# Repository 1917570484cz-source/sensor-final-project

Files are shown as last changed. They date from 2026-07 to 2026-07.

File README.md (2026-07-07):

# sensor-final-project

ESP32-S3 多传感器融合扩展板课程设计项目。项目实现了 MPU6050/MPU6500 兼容 IMU、HMC5883L 磁力计、BMP280/BME280 气压计和 GNSS 模块的数据采集、标定、融合与实验分析。

## 目录说明

```text
sensor-final-project/
├── hardware/                 # 硬件设计文件
│   ├── schematic.pdf          # 原理图 PDF
│   ├── pcb.pdf                # PCB 布局/制板文件说明 PDF
│   ├── gerber/                # Gerber 生产文件
│   └── BOM.csv                # 物料清单
├── firmware/                 # 固件与算法代码
│   ├── drivers/               # 串口记录、离线读取和驱动辅助脚本
│   ├── calibration/           # 加速度计、磁力计、Allan 方差和航向残差标定
│   ├── fusion/                # 互补滤波、Mahony、GNSS/INS、实时姿态显示分析脚本
│   ├── ai_enhance/            # 1D-CNN/卷积去噪与 Kalman 对比
│   └── main.c                 # ESP32-S3 主固件
├── data/                     # 测试数据
│   ├── calibration/           # 标定数据
│   ├── fusion_comparison/     # 融合与算法对比数据
│   └── performance/           # 更新频率、CPU 占用和时间同步数据
├── docs/                     # 文档
│   ├── spec.md                # 系统设计要求
│   ├── test_report.md         # 测试报告
│   ├── final_report.pdf       # 最终课程论文
│   └── final_report.docx      # 可编辑最终课程论文
├── figures/                  # 论文和实验图表
└── README.md                 # 仓库说明
```

## 已完成内容

- 硬件：完成 ESP32-S3 扩展板设计，I2C 总线连接 MPU、HMC5883L 和 BMP280，GNSS 使用 UART 与 PPS 引脚。
- 固件：完成 I2C 扫描、传感器初始化、CSV 串口输出、GPS NMEA 解析、PPS 时间同步记录、BMP/GPS 离线记录。
- 标定：完成加速度计六位置 12 参数标定、磁力计椭球拟合、陀螺仪 Allan 方差分析和温度补偿实验。
- 融合：实现互补滤波和 Mahony 姿态融合，完成实时网页姿态显示。
- AI 增强：完成 IMU 静态数据 1D 卷积去噪，并与传统低通、一阶 Kalman 混合结构进行 SNR 对比。
- 实验：完成标定精度、磁力计 3D 散点、Allan 曲线、BMP 楼梯高度、GNSS NMEA 解析、GNSS/INS 松耦合静态分析和更新频率测试。

## 构建与运行

固件基于 ESP-IDF，目标芯片为 ESP32-S3。

```powershell
cd firmware
idf.py set-target esp32s3
idf.py -p COM7 flash monitor
```

Python 分析脚本位于 `firmware/calibration`、`firmware/fusion`、`firmware/ai_enhance` 和 `firmware/drivers`。原始实验 CSV 位于 `data/`。

## 说明

本仓库是课程提交用整理版。原始 ESP-IDF 工程采用单文件主固件 `main.c`，传感器驱动、标定参数、融合算法和日志命令均集中在该文件中；离线标定和可视化脚本按老师要求拆分到对应目录。

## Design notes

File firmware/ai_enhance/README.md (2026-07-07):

# ai_enhance

本目录包含 AI 增强传感器算法：

- `ai_imu_denoise.py`：基于 1D 卷积的 IMU 静态噪声抑制，并对比传统低通和 1D 卷积 + 一阶 Kalman 混合结构。

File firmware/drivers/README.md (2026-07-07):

# drivers

ESP32-S3 固件主驱动集中在 `../main.c` 中，包括：

- I2C 初始化与扫描
- MPU6050/MPU6500 兼容 IMU 读取
- HMC5883L 磁力计读取
- BMP280/BME280 气压计补偿读取
- GNSS UART/NMEA 接收
- PPS GPIO 中断时间同步

本目录存放 PC 端串口记录和离线读取辅助脚本。

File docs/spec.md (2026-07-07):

# 二、系统设计要求

## 1. 硬件设计要求（ESP32 扩展板）

### 1.1 基础规格

- 尺寸限制：≤70mm×50mm（适配嘉立创打样尺寸，标准 2 层板）
- 供电：通过 ESP32 开发板 5V/3.3V 供电，无需外部电源
- 接口：
  - 全部采用 2.54mm 排针，与 ESP32 开发板引脚一一对应
  - I²C 总线共享（SCL/SDA），所有传感器挂同一 I²C 总线
  - GPS 接口：4-pin 2.54mm 排针（VCC/GND/TX/RX），外接 NEO-6M，用杜邦线连
  - LED 指示：至少 1 个电源指示 LED，绿色，串 1kΩ 电阻
- 布局建议：
  - MPU6050 放板中央，减少边缘应力，距板边 ≥ 5mm
  - HMC5883L 远离 ESP32，避免 ESP32 芯片 / WiFi 天线的磁干扰
  - 远离发热元件，避免温度影响气压读数
  - GPS 排针在板边缘，方便连线朝外
  - I²C 上拉电阻一组就够（多个会并联降阻），4.7kΩ × 2（SCL/SDA 各一个）

### 1.2 必修传感器电路

#### MPU6050 六轴 IMU

- 通信接口：SPI（优先）或 I2C
- 必须包含 0.1μF 去耦电容、电源滤波电路
- 预留中断引脚，用于数据就绪触发

#### HMC5883L 三轴磁力计

- 通信接口：I2C
- 必须包含去耦电容和上拉电阻
- 布局远离电源、电机等强干扰源

### 1.3 选修传感器电路（鼓励至少选 1 种）

- MS5611 或 BMP280 气压计：SPI 接口，高精度气压高度测量
- Ublox M6N GPS 模块：UART 接口，预留天线接口
- 电源管理：可选 3.3V LDO，为传感器提供干净电源

### 1.4 信号完整性要求（对应第六讲内容）

- 所有传感器电源引脚必须就近放置 0.1μF 陶瓷去耦电容
- 模拟信号走线尽量短，避免与数字信号走线交叉
- 完整的地平面设计，分割数字地和模拟地
- 预留测试点，方便调试和信号测量

## 2. 算法设计要求

### 2.1 基础算法（所有组必须完成）

#### 传感器标定算法

- 加速度计六位置标定（12 参数模型），零偏 50mg → 2mg（25×）
- 磁力计椭球拟合标定（硬铁 / 软铁补偿），航向 ±15° → ±2°（7×）
- 陀螺仪零偏校准与 Allan 方差分析，零偏漂移降 10×

#### 传统姿态融合算法（至少实现 2 种）

- 互补滤波
- Mahony 滤波
- Madgwick 滤波
- 扩展卡尔曼滤波（EKF）

#### 性能对比分析

- 对比不同算法的姿态精度、计算复杂度、CPU 占用率
- 量化每种算法带来的精度提升幅度

#### 数据可视化（必做）

| 内容 | 工具 / 方式 | 要求 |
| --- | --- | --- |
| 标定前后精度对比表 | Python matplotlib | 误差降低倍数 |
| Allan 方差曲线 | Python allantools | ARW/BI 标注 |
| 磁力计 3D 散点（校准前后） | Python mplot3d | 椭球 → 球 |
| 实时姿态显示 | 串口 + Python / Web | 倾斜板子看角度变化 |
| GPS 轨迹叠加 | Python folium | 户外测试轨迹 |

### 2.2 进阶算法（80 分以上必须完成）

#### 误差状态卡尔曼滤波（ESKF）

- 基于李群李代数 SO(3) 的姿态表示
- 实现 IMU 预积分与误差状态更新
- 目标姿态精度：≤±0.2°（静态）

#### AI 增强传感器算法（至少实现 1 种）

- 1D-CNN IMU 噪声去除：对比传统低通滤波的 SNR 提升 dB 数
- 一阶卡尔曼滤波与 1D-CNN 的混合去噪架构
- 目标：纯惯导漂移从 10m/min 降低至 ≤3m/min

### 2.3 挑战算法（90 分以上可选）

- 多速率传感器融合：GPS 1Hz + IMU 200Hz 异步状态更新
- LSTM GPS 失锁预测：当 GPS 信号丢失时，用 LSTM 预测轨迹
- TLIO/DeepVIO 核心模块复现：基于深度学习的紧耦合惯导里程计
- 多传感器时间同步：实现 IMU、磁力计、GPS 的微秒级时间对齐

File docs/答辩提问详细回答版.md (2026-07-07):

# 答辩提问详细回答版

这个文档是给不熟悉传感器和融合算法的人准备的详细版。答辩时不需要逐字全背，但要理解每题的核心逻辑。每题都分成：

- 老师到底在问什么
- 基础原理怎么理解
- 结合本项目应该怎么说
- 可以直接背的回答
- 可能追问怎么接

特别注意：本项目有些内容只做了原理分析或离线验证，没有完整做成最终主结果。遇到这些问题时，不要硬说“我已经完整实现”，要先说明项目边界，再回答原理。

---

# 第一类：传感器物理与误差本质

## Q1. 六位置标定得到 12 个参数，它们对应 MPU6050 的哪些物理误差？

### 1. 老师到底在问什么

老师不是只想听你说“我用了最小二乘”。他想确认你知道标定出来的数字到底修正了什么物理问题。

你加速度计的标定模型可以写成：

```text
a_cal = A_inv · (a_raw - c)
```

含义是：

```text
校正后的加速度 = 3×3 修正矩阵 × (原始加速度 - 零偏)
```

其中：

- `a_raw`：MPU6050 原始读数。
- `c`：3×1 零偏向量。
- `A_inv`：3×3 误差修正矩阵。
- `a_cal`：校正后的加速度。

所以 12 个参数就是：

```text
3 个零偏参数 + 9 个矩阵参数 = 12 个参数
```

### 2. c 向量对应什么误差

`c` 是：

```text
c = [cx, cy, cz]^T
```

它对应三轴零偏误差。

比如板子水平静止时，理论上应该是：

```text
ax = 0
ay = 0
az = 1g
```

但实际可能读到：

```text
ax = 0.02g
ay = -0.01g
az = 1.05g
```

其中 `ax`、`ay` 明明应该接近 0，却读出非零值，这就是零偏。`az` 理论上应该接近 1g，却多出一部分，也包含零偏和比例误差。

所以第一步 `(a_raw - c)` 就是先把固定偏移减掉。

### 3. A_inv 矩阵对应什么误差

`A_inv` 是一个 3×3 矩阵：

```text
A_inv =
[ a11  a12  a13
  a21  a22  a23
  a31  a32  a33 ]
```

它主要修正三类误差。

第一类是比例因子误差，也叫灵敏度误差。

比如 X 轴真实受到 1g 加速度，理想输出应该是：

```text
ax = 1.000g
```

但实际可能输出：

```text
ax = 0.980g
```

或者：

```text
ax = 1.030g
```

说明 X 轴这把“尺子”不准。`A_inv` 的对角线元素主要修正三轴比例误差：

```text
a11 修正 X 轴比例
a22 修正 Y 轴比例
a33 修正 Z 轴比例
```

第二类是轴间耦合误差。

理想情况下，X 轴只测 X 方向，Y 轴只测 Y 方向，Z 轴只测 Z 方向。但实际传感器三轴不可能完全独立。

比如真实加速度只有 X 方向：

```text
真实加速度 = [1g, 0, 0]
```

理想读数应该是：

```text
输出 = [1g, 0, 0]
```

但实际可能是：

```text
输出 = [1g, 0.03g, -0.02g]
```

这说明 X 方向的加速度串到了 Y/Z 轴上。`A_inv` 的非对角线元素就是用来修正这种耦合：

```text
a12, a13, a21, a23, a31, a32
```

第三类是安装角误差和三轴不正交误差。

即使 MPU 芯片本身正常，它焊在 PCB 上也可能有非常小的倾斜。比如你以为板子的 X 方向就是传感器 X 方向，但芯片实际歪了 1°。这样真实 X 方向的加速度会投影到 Y/Z 轴，表现出来也像轴间耦合。这部分同样由 `A_inv` 的非对角线修正。

### 4. 如果只有零偏误差，A_inv 应该长什么样

要分两种情况说，最完整。

第一种：只有零偏，比例因子和三轴方向都完全理想。

这时只需要减掉 `c`，不需要矩阵修正，所以：

```text
A_inv =
[1  0  0
 0  1  0
 0  0  1]
```

也就是单位矩阵。

第二种：有零偏，也有各轴比例误差，但没有轴间耦合。

这时 `A_inv` 应该是对角矩阵：

```text
A_inv =
[kx  0   0
 0   ky  0
 0   0   kz]
```

其中 `kx`、`ky`、`kz` 分别修正 X/Y/Z 三轴的灵敏度。非对角线为 0，表示 X 不影响 Y/Z，Y 不影响 X/Z，Z 不影响 X/Y。

### 5. 结合本项目怎么说

本项目中，六位置 12 参数标定后：

- 平均误差从约 `20.068 mg` 降到 `1.798 mg`。
- 最大误差从约 `55.789 mg` 降到 `2.120 mg`。

这说明零偏、比例误差和安装耦合误差都被明显补偿了。

### 6. 可直接背的回答

> 我的加速度计标定模型是 `a_cal = A_inv · (a_raw - c)`。其中 `c` 是 3×1 零偏向量，表示 X、Y、Z 三轴的固定偏移。`A_inv` 是 3×3 修正矩阵，对角线元素主要修正三轴灵敏度或比例因子误差，非对角线元素主要修正轴间耦合、三轴不正交以及传感器安装角误差。如果只有零偏且比例完全理想，`A_inv` 应该接近单位矩阵；如果还有比例误差但没有轴间耦合，`A_inv` 应该退化为对角矩阵，对角元素是各轴灵敏度修正系数，非对角线接近 0。

### 7. 可能追问

如果老师问“为什么叫 A_inv？”：

> 可以把原始传感器看成真实加速度先经过一个误差矩阵 A 扭曲后输出。标定的目的就是求它的逆，把扭曲后的数据拉回真实坐标系，所以代码中叫 `A_inv`。

如果老师问“c 和 A_inv 谁先作用？”：

> 先减零偏 `c`，再乘 `A_inv`。因为零偏是固定偏移，先去掉固定偏移，再修正比例和轴间耦合。

---

## Q2. Allan 方差曲线短时间 -1/2、中段最低点、长时间 +1/2 分别代表什么？

### 1. 老师到底在问什么

老师想知道你是否理解 Allan 方差不是普通曲线，而是用来分析 IMU 噪声来源的工具。

Allan 方差横轴通常是平均时间 `τ`，纵轴是 Allan deviation。它回答的问题是：

> 如果我把陀螺仪数据按不同时间窗口平均，噪声会怎么变化？

不同斜率对应不同噪声源。

### 2. 短时间段斜率 -1/2 是什么

短时间段通常由白噪声主导。对白噪声来说，平均时间越长，随机噪声越容易被平均掉，所以 Allan deviation 会下降。

在双对数图上，白噪声对应斜率约为：

```text
-1/2
```

对陀螺仪来说，这段常用来估计角随机游走 ARW，即 Angular Random Walk。

通俗理解：

> 短时间里，陀螺仪输出主要是在真实值附近随机抖动，这种抖动可以通过平均减小。

### 3. 中段最低点是什么

曲线下降到某个位置后会出现最低点或平台，这附近表示平均到这个时间尺度时噪声最小。

这一段通常和零偏不稳定性 BI，也就是 Bias Instability 有关。

通俗理解：

> 平均时间太短，白噪声还没平均干净；平均时间太长，零偏慢漂移又开始显现。中间最低点就是两类误差折中后最稳定的位置。

### 4. 长时间段斜率 +1/2 是什么

长时间段如果曲线上升，常表示零偏随机游走、温漂、慢变化环境等低频漂移开始主导。

在双对数图上，如果斜率约为：

```text
+1/2
```

通常可理解为 rate random walk 或 bias random walk 类型的慢漂移。

通俗理解：

> 时间越长，陀螺仪零点不是固定的，而是慢慢飘走，所以平均反而不能继续降低误差。

### 5. 和 Kalman 滤波 Q、R 的关系

Kalman 滤波里：

- `R` 表示观测噪声，也就是传感器测量本身有多吵。
- `Q` 表示过程噪声，也就是系统状态预测有多不可靠。

对应关系可以这样理解：

短时间白噪声/角随机游走：

- 反映陀螺仪测量噪声。
- 可以用于设置陀螺仪测量噪声或姿态更新里的噪声项。
- 更接近 `R` 或角速度测量噪声。

长期零偏漂移：

- 反映陀螺仪 bias 会随时间变化。
- 如果滤波器把陀螺零偏作为状态估计，那么 bias 的随机游走噪声应该放进 `Q`。

### 6. 结合本项目怎么说

本项目完成了约 300 s 静态陀螺仪数据采集和 Allan 方差曲线绘制。它主要用于分析噪声特性和辅助滤波器参数选择。

注意不要说“已经严格证明零偏漂移降低 10×”，因为这个需要补偿前后长期对比数据，而当前主要是 Allan 噪声分析。

### 7. 可直接背的回答

> Allan 方差短时间段斜率约 -1/2，说明白噪声主导，对陀螺仪来说对应角随机游走 ARW；中间最低点表示在这个平均时间尺度下零偏最稳定，和 bias instability 有关；长时间段如果斜率变成 +1/2，说明零偏随机游走或慢漂移开始主导。和 Kalman 滤波对应时，短时间白噪声更多用于设置陀螺测量噪声，也就是 R 或角速度噪声；长期零偏漂移则对应状态模型里 bias 的过程噪声，应该进入 Q 矩阵。

### 8. 可能追问

如果老师问“为什么不是平均越久越准？”：

> 因为平均只能降低白噪声，但不能消除零偏慢漂移。时间太长后，零偏本身会变，平均反而把漂移包含进去，所以 Allan 曲线会重新上升。

---

## Q3. HMC5883L 分辨率是 5 mGauss，为什么校准后磁场模长 std 仍然远大于它？

### 1. 老师到底在问什么

老师想看你是否能区分：

- 数据手册里的分辨率
- 实际系统中的精度
- 实验环境带来的干扰

很多人会误以为传感器分辨率就是最终精度，这是错误的。

### 2. 单位先换算

HMC5883L 分辨率是 5 mGauss。

换算关系：

```text
1 Gauss = 100 uT
1 mGauss = 0.1 uT
5 mGauss = 0.5 uT
```

所以数据手册分辨率约为：

```text
0.5 uT
```

### 3. 本项目实测数据

本项目磁力计模长结果：

- 标定前模长标准差：`3.303 uT`
- 标定后模长标准差：`1.892 uT`

校准后 `1.892 uT` 仍然大于数据手册分辨率 `0.5 uT`。

### 4. 为什么会这样

原因是 datasheet 分辨率只说明传感器输出能分辨的最小变化，不等于最终整机精度。

实际系统中还有很多误差：

1. 周围磁环境干扰
   - 桌面、螺丝、手机、电源线、电脑、USB 线都可能影响磁场。

2. PCB 布局和电源噪声
   - 磁力计附近如果有高频数字信号、大电流走线或去耦不好，会增加噪声。

3. 硬铁和软铁残差
   - 椭球拟合能补偿一部分，但如果采集数据覆盖不均匀，补偿不可能完全理想。

4. 采集动作不均匀
   - 如果没有完整覆盖整个球面，某些方向的数据不足，拟合结果会偏。

5. 传感器本身老旧或模块差异
   - HMC5883L 属于较老的磁力计，实际模块质量差异较大。

### 5. 算法不对还是硬件原因

不能简单说算法不对。

如果标定后标准差从 `3.303 uT` 降到 `1.892 uT`，说明算法确实有效。但是剩余误差大于 datasheet 分辨率，主要说明系统级环境和硬件因素仍然存在。

### 6. 可直接背的回答

> HMC5883L 的 5 mGauss 约等于 0.5 uT。我的磁力计标定前模长标准差是 3.303 uT，标定后是 1.892 uT，虽然明显下降，但仍然大于 0.5 uT。这不一定说明算法错误，因为 datasheet 分辨率不等于整机精度。剩余误差主要来自磁环境干扰、PCB 电源和走线影响、采集球面覆盖不均匀，以及硬铁软铁补偿残差。

### 7. 可能追问

如果老师问“怎么进一步降低？”：

> 我会让磁力计远离 ESP32 天线、USB 和电源走线，增加去耦，采集时远离手机和铁磁物体，并用更均匀的全空间旋转数据进行鲁棒椭球拟合。

---

## Q4. 气压计测高精度是多少？误差预算怎么分解？

### 1. 老师到底在问什么

老师想知道你是否明白：BMP280 测高度不是直接测“高度”，而是先测气压，再用气压换算高度。

所以误差不仅来自 BMP280 本身，还来自参考气压、温度、天气变化和真实高度参考。

### 2. 本项目结果

楼梯实验数据：

- 人工测量楼层高度：`3.950 m`
- BMP280 测量相对高度：`3.980 m`
- 绝对误差：`0.030 m`
- 相对误差：`0.76%`

也就是说，在这次短时间楼梯相对高度实验中，误差约为 3 cm。

### 3. 气压高度为什么依赖 P0

气压高度不是直接测出来的，而是由气压公式换算：

```text
h = f(P / P0)
```

其中：

- `P` 是当前气压。
- `P0` 是参考气压。

如果 `P0` 不准，即使 BMP280 当前压力测得很准，高度也会整体偏。

### 4. 误差预算怎么拆

可以拆成以下几项：

1. 传感器压力噪声
   - BMP280 自身压力读数会有噪声。
   - 短时间平均可以降低这部分噪声。

2. P0 参考气压误差
   - 高度换算对 P0 很敏感。
   - P0 不准会造成整体高度偏移。
   - 在绝对高度测量中，这通常是主导误差。

3. 温度补偿误差
   - BMP280 压力补偿依赖温度。
   - 温度变化或温度读取滞后会影响压力换算。

4. 天气漂移
   - 气压会随天气变化。
   - 长时间测试时，天气变化可能造成几十米级高度漂移。
   - 但本项目楼梯实验时间短，所以影响较小。

5. 人工真值误差
   - 楼层高度 3.95 m 是人工测量值，也有测量误差。

6. 气流和动态扰动
   - 上下楼、开门、风流会改变局部气压。

### 5. 哪一项是主导误差

在本项目的短时间楼梯相对高度实验中：

- 主要瓶颈不是 BMP280 分辨率。
- 更主要的是 `P0` 参考、环境气压稳定性、人工测量真值和窗口平均方法。

在长时间绝对高度实验中：

- `P0` 和天气漂移通常是主导误差。

### 6. 可直接背的回答

> 我这次 BMP280 楼梯实验中，人工测量高度是 3.950 m，BMP280 测得 3.980 m，绝对误差 0.030 m，相对误差 0.76%。误差预算可以分为传感器压力噪声、P0 参考气压误差、温度交叉敏感、天气气压漂移、人工高度真值误差和气流扰动。短时间相对高度实验中，BMP280 分辨率不是主要瓶颈，主要瓶颈是 P0 和环境条件；长时间绝对高度中，天气漂移和 P0 会成为主导误差。

---

## Q5. HMC5883L 离 ESP32 WiFi 天线距离变化会怎样影响航向？

### 1. 老师到底在问什么

老师想看你是否从系统电磁兼容角度理解磁力计，而不是只看算法。

磁力计测的是微弱地磁场，地磁场量级大约几十 uT。任何附近电流、天线、高频数字信号、铁磁材料都可能改变磁场读数。

### 2. 距离从 15 mm 变 5 mm 会怎样

如果磁力计离 ESP32 WiFi 天线或电源路径更近，可能会出现：

- 磁场三轴均值偏移。
- 磁场模长标准差变大。
- 航向 yaw 出现固定偏差。
- WiFi 发射时 yaw 抖动增加。

距离变近通常会让干扰增强。具体增强多少取决于天线、电流路径、地平面和磁力计方向。

### 3. 怎么实验验证

可以设计一个很简单的对比实验：

1. 固定板子，不让它动。
2. 记录 WiFi 关闭时的磁场三轴和 yaw。
3. 打开 WiFi 但不传输数据，再记录。
4. WiFi 高负载发包，再记录。
5. 比较三种情况下：
   - `mag_x/y/z` 均值变化。
   - 磁场模长标准差。
   - yaw 平均值偏移。
   - yaw 标准差。

如果 WiFi 影响明显，高负载发包时 yaw 标准差和模长标准差会变大。

### 4. 本项目怎么说

你没有精确测 HMC5883L 到 WiFi 天线距离，也没有做开关 WiFi 对比实验，所以不要乱报具体数值。

可以回答：

> 这一项我没有单独量化，但从 EMC 角度，下一版 PCB 会让磁力计远离 ESP32 天线、电源和 USB 区域。

### 5. 可直接背的回答

> 磁力计测的是几十 uT 量级的地磁场，离 ESP32 WiFi 天线或大电流路径太近，会引入电磁干扰和局部磁场扰动。距离从 15 mm 减到 5 mm，我预期磁场模长波动和 yaw 标准差都会增大。验证方法是固定板子，分别在 WiFi 关闭、开启、持续发包三种情况下采集磁场和 yaw，比较均值偏移和标准差变化。

---

# 第二类：标定算法的数学深度

## Q6. 椭球拟合 SVD 为什么取最小奇异值对应的右奇异向量？

### 1. 老师到底在问什么

老师想确认你知道 SVD 在这里不是“固定套路”，而是在求一个最小残差解。

椭球拟合可以写成齐次方程：

```text
Phi · q = 0
```

其中：

- `Phi` 是由磁力计采样点构成的矩阵。
- `q` 是椭球方程参数。

### 2. 为什么不能直接解

因为这是齐次方程，`q = 0` 永远满足：

```text
Phi · 0 = 0
```

但 `q=0` 没有任何物理意义。所以要加一个约束：

```text
||q|| = 1
```

也就是在单位长度的所有 `q` 里面，找一个让残差最小的方向。

目标变成：

```text
min ||Phi · q||
subject to ||q|| = 1
```

### 3. SVD 为什么取最小奇异值

SVD 分解：

```text
Phi = U · S · V^T
```

奇异值表示矩阵在不同方向上的放大能力。

最小奇异值对应的右奇异向量，就是被 `Phi` 放大最小的方向。也就是说，在单位长度条件下，它让：

```text
||Phi · q||
```

最小。

所以取最小奇异值对应的右奇异向量，而不是最大奇异值。最大奇异值方向是残差最大的方向，正好相反。

### 4. 如果数据只覆盖半个球面会怎样

椭球拟合要求数据尽量覆盖完整三维空间。如果只转了半个球面，会出现：

- 某些方向没有约束。
- 奇异值分布退化。
- 最小奇异值对应的方向不稳定。
- 椭球中心和轴长可能严重偏。
- 解可能不唯一。

通俗说：

> 数据没有告诉算法“另一半球面长什么样”，算法只能猜，所以拟合会不可靠。

### 5. 可直接背的回答

> 椭球拟合可以写成齐次方程 `Phi q = 0`。因为零解没有意义，所以加 `||q||=1` 的约束，本质上是在单位长度的 q 中找让 `||Phi q||` 最小的方向。SVD 中最小奇异值对应的右奇异向量正是最小残差方向，所以取它。如果采集数据只覆盖半个球面，某些方向约束不足，奇异值会退化，解会变得不唯一或不稳定，椭球中心和轴长都可能偏。

---

## Q7. 六位置标定时桌面不水平，误差会进入标定结果吗？

### 1. 老师到底在问什么

老师想看你是否理解“六个面的真值”不是天然准确的。你把板子放在桌面上，默认桌面是水平的。但如果桌面倾斜 2°，理论真值就不是完美的 ±X/±Y/±Z。

### 2. 桌面倾斜会造成什么

假设你以为当前是 +Z 朝上，理论加速度应为：

```text
[0, 0, 1g]
```

但桌面倾斜 2° 时，重力会在 X/Y 方向有投影。

小角度下：

```text
sin(2°) ≈ 0.0349
```

也就是会产生约：

```text
0.035g = 35 mg
```

的横向分量。

这已经比 2 mg 目标大很多。

### 3. 误差会不会进入标定结果

会。

如果你仍然把这个位置当作理想 +Z，那么标定算法会认为这个横向分量是传感器误差，并把它吸收到：

- 零偏 `c`
- 非正交矩阵 `A_inv`
- 安装角误差项

里。

这样标定出来的参数会包含桌面倾斜误差。

### 4. 如何消除

方法：

1. 使用水平仪或高精度水平平台。
2. 每个方向多次摆放并取平均。
3. 用夹具保证六个方向正交。
4. 不只用六位置，而是采集更多随机姿态，用重力模长 `|g|=1` 约束做球面标定。
5. 标定时记录平台倾角并修正真值方向。

### 5. 本项目怎么说

你的项目中确实是手动六位置采集，所以可以承认：

> 摆放误差会影响标定结果，因此我通过每个位置采集多样本并筛选稳定数据来降低随机影响，但如果平台系统性倾斜，仍然会进入标定参数。

### 6. 可直接背的回答

> 会进入。因为六位置标定默认六个面的真值是 ±X、±Y、±Z，如果桌面倾斜 2°，重力会产生约 sin2°≈0.035g，也就是 35mg 的横向分量。算法可能把这个误差吸收到非正交矩阵或安装角误差里。消除方法是使用水平平台或夹具，或者采集更多随机姿态，用重力模长约束做自校准。

---

## Q8. 温度补偿二次多项式系数怎么确定？外推到 60°C 会怎样？

### 1. 老师到底在问什么

老师想确认你知道标定模型有适用范围。一个模型在标定温度范围内可能有效，但超出范围就不一定可靠。

### 2. 二次温度补偿模型是什么

陀螺仪零偏会随温度变化，可以建模为：

```text
b(T) = α + βT + γT²
```

其中：

- `b(T)` 是某一温度下的零偏。
- `T` 是温度。
- `α、β、γ` 是拟合系数。

三轴陀螺通常每个轴都要拟合一组三个系数。

### 3. 系数怎么确定

需要在多个温度点下采集静态陀螺数据：

```text
T1 -> b1
T2 -> b2
T3 -> b3
...
```

然后用最小二乘拟合：

```text
b(T) = α + βT + γT²
```

温度点越多、覆盖越均匀，拟合越可靠。

### 4. 20°C 到 50°C 和 60°C 的区别

如果标定数据覆盖 20°C 到 50°C：

- 在 20-50°C 内使用，叫插值。
- 在 60°C 使用，叫外推。

插值相对可靠，因为模型在已知数据范围内。

外推不可靠，因为 60°C 没有数据约束，二次多项式可能偏离真实传感器特性。

### 5. 外推误差属于什么误差

属于模型外推误差，也可以说是模型适用范围外误差。

如果多项式阶数更高，还可能出现 Runge 现象，即在区间外或边缘出现剧烈振荡。

### 6. 项目边界

如果老师问“你的温度补偿”，但你没有完整做温箱实验，不要硬说已经做完。

你可以说：

> 本项目主要完成 Allan 方差和静态噪声分析，温度补偿作为可扩展方法；如果要做，需要按温度点采集零偏并拟合系数。

### 7. 可直接背的回答

> 二次温度补偿系数需要在多个温度点下静态采集陀螺零偏，然后用最小二乘拟合 `b(T)=α+βT+γT²`。20°C 到 50°C 内使用属于插值，60°C 使用属于外推。外推没有实测数据约束，误差可能明显增大，属于模型外推误差；高阶多项式还可能在区间外产生振荡。

---

## Q9. 磁力计椭球拟合中离群点有什么影响？如何减少？

### 1. 老师到底在问什么

老师想看你是否知道普通最小二乘对异常点很敏感。

### 2. 为什么离群点影响大

SVD 椭球拟合本质上是最小二乘思想，最小化所有点的整体残差。

普通最小二乘相当于使用 L2 损失：

```text
loss = residual²
```

残差会被平方，所以一个很大的离群点会被赋予非常大的影响。

比如采集时手机靠近一下，磁力计读数突然跳变，这个点可能把椭球中心和轴长拉偏。

### 3. 离群点会造成什么结果

可能导致：

- 硬铁中心估计错误。
- 软铁矩阵估计错误。
- 校准后球面仍然不圆。
- 航向角出现固定偏差或局部方向误差。

### 4. 如何减少离群点影响

方法：

1. 采集时实时看磁场模长，明显异常就重采。
2. 标定前按模长范围筛选数据。
3. 用 RANSAC：
   - 随机选一部分点拟合。
   - 看有多少点符合模型。
   - 保留内点最多的模型。
4. 用 Huber 损失或 Tukey 损失替代普通 L2。
5. 拟合后根据残差再次剔除异常点并重新拟合。

### 5. 可直接背的回答

> 离群点对普通 SVD 椭球拟合影响很大，因为它本质上接近最小二乘，L2 损失会把大残差平方放大。一个手机靠近造成的异常点可能拉偏椭球中心和轴长。减少影响的方法包括采集前后做模长阈值筛选、用 RANSAC 找内点、用 Huber 等鲁棒损失，或者先拟合再按残差剔除异常点重新拟合。

---

## Q10. BMP280 的 t_fine 是什么？为什么温度补偿结果会用于气压补偿？

### 1. 老师到底在问什么

老师想确认你不是直接复制 Bosch 代码，而是理解温度和压力补偿之间的耦合。

### 2. t_fine 是什么

BMP280 里温度 ADC 不是直接等于真实温度，压力 ADC 也不是直接等于真实压力。

Bosch 补偿算法先根据温度原始值和芯片内部校准参数算出一个中间量：

```text
t_fine
```

它可以理解为高精度内部温度补偿状态。

它不是简单的摄氏温度显示值，而是用于后续补偿计算的内部变量。

### 3. 为什么气压补偿也要用 t_fine

压力传感器对温度敏感。也就是说，同一个真实压力下，如果温度不同，压力 ADC 输出也会变。

所以压力补偿时必须知道当前温度状态。

Bosch 的算法就是：

1. 先用温度原始值计算 `t_fine`。
2. 再用 `t_fine` 修正压力原始值。

这说明温度补偿和压力补偿不是完全独立的。

### 4. 温度和气压读取时间差 100 ms 会怎样

如果温度和气压读取差了 100 ms，在室内慢温变条件下影响可能很小。

但如果环境温度变化很快，比如：

- 手指触摸芯片
- 热风吹过
- 设备从室内到室外
- 电路发热快速变化

那么压力补偿使用的温度就不是压力采样时的真实温度，会引入温度交叉敏感误差。

### 5. 可直接背的回答

> t_fine 是 Bosch 补偿算法中的内部精细温度变量，由温度原始 ADC 和芯片校准参数计算得到。BMP280 的压力输出受温度影响，所以压力补偿必须使用 t_fine。若温度和压力读取相差 100 ms，在温度变化慢的室内影响较小；但在快速温变下，会用不匹配的温度去补偿压力，从而引入温度交叉敏感误差。

---

# 第三类：融合算法的工程理解

## Q11. Madgwick 滤波器 beta 怎么选？快速机动时有什么影响？

### 1. 先说明项目边界

本项目最终展示的是：

- 互补滤波
- Mahony 滤波
- ESKF 静态分析

没有把 Madgwick 滤波作为最终主结果。因此答题时不能硬说“我的 Madgwick 参数是多少”。可以先说明：

> 本项目最终没有把 Madgwick 作为主结果，但从 Madgwick 原理看，beta 的作用是这样的。

### 2. beta 是什么

Madgwick 滤波中，陀螺仪负责预测姿态，加速度计和磁力计负责修正姿态。`beta` 控制修正项强度。

简单理解：

- `beta` 大：更相信加速度计/磁力计修正，收敛快，但动态时容易被干扰。
- `beta` 小：更相信陀螺积分，动态更平滑，但长期漂移更明显。

### 3. 快速急转弯时为什么 beta 要小心

飞机快速急转弯时，加速度计测到的不再只是重力，还包含：

- 离心加速度
- 机动加速度
- 振动

Madgwick 的姿态修正默认加速度计主要测重力方向。如果这个假设不成立，过大的 beta 会把非重力加速度误认为姿态倾斜，从而把姿态拉错。

### 4. 200 deg/s 持续 0.5 秒的影响

角速度 200 deg/s 持续 0.5 s，姿态变化量约：

```text
200 × 0.5 = 100°
```

这是很强的动态机动。此时应降低加速度计修正权重，也就是降低 beta，或者动态调整 beta。

### 5. 可直接背的回答

> 本项目最终展示的是互补滤波和 Mahony 滤波，没有把 Madgwick 作为主结果。如果从 Madgwick 原理看，beta 是梯度下降修正项权重。beta 越大，越相信加速度计和磁力计，收敛快但动态机动时容易被非重力加速度误导；beta 越小，越相信陀螺积分，动态更平滑但长期漂移更大。飞机快速急转时，加速度计测到的不只是重力，所以 beta 应该适当降低或自适应调整。

---

## Q12. Roll/Pitch 和 Yaw 精度是多少？为什么 Yaw 比 Roll/Pitch 差？

### 1. 本项目可报数据

静态姿态实验：

- ESKF roll 标准差：`0.074643°`
- ESKF pitch 标准差：`0.132308°`
- 静态稳定 RMS：`0.151800°`

航向残差补偿：

- 平均绝对误差：`1.907°`
- 最大绝对误差：`6.940°`

### 2. 为什么 Roll/Pitch 比 Yaw 好

静止时，加速度计可以测到重力方向。

重力方向可以约束：

- Roll
- Pitch

因为板子前后倾、左右倾，重力在三轴上的投影会变化。

但是 Yaw 是绕重力轴旋转。比如板子水平放在桌上，原地转一圈，重力方向在传感器坐标里的投影基本不变。

所以：

```text
加速度计无法观测 Yaw
```

Yaw 必须依赖：

- 磁力计
- GPS 航向
- 视觉
- 双天线 GNSS

而磁力计很容易受到磁环境影响，所以 Yaw 通常比 Roll/Pitch 差。

### 3. 如果去掉磁力计，Yaw 10 分钟会漂多少

去掉磁力计后，Yaw 只能靠陀螺积分。

漂移估算公式：

```text
Yaw 漂移 ≈ 陀螺零偏 × 时间
```

10 分钟：

```text
600 s
```

如果陀螺 Z 轴零偏是 `0.05 deg/s`，则：

```text
0.05 × 600 = 30°
```

如果零偏是 `0.01 deg/s`，则：

```text
0.01 × 600 = 6°
```

所以具体漂移要看实测陀螺零偏，但一定会随时间累积。

### 4. 可直接背的回答

> 本项目静态姿态中，Roll 标准差约 0.0746°，Pitch 标准差约 0.1323°，静态稳定 RMS 约 0.1518°。航向补偿后平均绝对误差约 1.907°，最大约 6.940°。Yaw 比 Roll/Pitch 差，是因为加速度计只能观测重力方向，可以约束 Roll 和 Pitch，但绕重力轴旋转的 Yaw 对加速度计不可观，必须依赖磁力计，而磁力计又容易受环境干扰。去掉磁力计后，Yaw 会按陀螺零偏乘时间累积漂移，比如 0.05 deg/s 的零偏 10 分钟会漂约 30°。

---

## Q13. 卡尔曼滤波 Q 矩阵代表什么？Q 过小或过大会怎样？

### 1. 老师到底在问什么

老师想确认你理解 KF 调参，而不是只会调用公式。

Kalman 滤波核心是平衡：

- 模型预测
- 传感器观测

### 2. Q 和 R 的区别

`Q` 是过程噪声协方差。

它表示：

> 我对系统模型预测有多不信任。

`R` 是观测噪声协方差。

它表示：

> 我对传感器测量有多不信任。

### 3. Q 过小会怎样

Q 过小表示滤波器过度相信模型预测。

现象：

- 曲线很平滑。
- 对真实变化反应慢。
- 楼梯高度变化时可能跟不上。
- 严重时滤波器过度自信，真实状态变化后仍不修正，可能发散。

这叫：

- over-confidence
- filter divergence

### 4. Q 过大会怎样

Q 过大表示滤波器认为模型很不可靠，于是更相信观测。

现象：

- 曲线跟着测量抖动。
- 滤波效果变差。
- 近似退化成直接测量或加权平均。

### 5. 项目边界

如果老师问“你的高度 KF”，但本项目最终主要展示 BMP280 相对高度实验，而不是完整 GPS/气压高度 KF，可以说：

> 本项目主要完成 BMP280 相对高度验证，KF 参数属于扩展分析。如果使用高度 KF，Q 应根据真实垂直运动变化和气压高度模型误差来设置。

### 6. 可直接背的回答

> Q 是过程噪声协方差，表示模型预测的不确定性；R 是观测噪声协方差，表示传感器测量的不确定性。Q 设得太小，滤波器过度相信模型，输出很平滑但跟踪真实变化慢，严重时过度自信甚至发散；Q 设得太大，滤波器过度相信观测，输出会抖，滤波效果减弱，接近直接跟随测量。

---

## Q14. GPS/气压互补滤波 alpha=0.98 对应多长时间常数？气压天气漂移怎么办？

### 1. 项目边界

本项目最终没有把 GPS/气压动态互补滤波作为主结果，完成的是：

- BMP280 楼梯相对高度实验。
- GNSS NMEA 解析。
- 静态 GPS 数据分析。

所以如果老师问，可以先说：

> 本项目没有把 GPS/气压动态互补作为最终主结果，但从一阶互补滤波原理看，alpha 可以这样理解。

### 2. alpha 和时间常数关系

一阶滤波中，近似时间常数：

```text
tau = dt / (1 - alpha)
```

如果：

```text
alpha = 0.98
dt = 0.02 s
```

则：

```text
tau = 0.02 / 0.02 = 1 s
```

意思是滤波器大约用 1 秒时间响应变化。

### 3. 台风前气压下降 3 hPa 会造成多大高度误差

近似关系：

```text
1 hPa ≈ 8.4 m
```

所以：

```text
3 hPa ≈ 25.2 m
```

如果不更新 `P0`，气压高度会慢慢漂移约 25 m。

### 4. 怎么补偿

方法：

1. 定期用 GPS 高度或已知高度修正 `P0`。
2. 引入气象站参考气压。
3. 对气压慢漂建模，把 `P0` 作为状态估计。
4. 动态调整 alpha，在长期慢漂时增加 GPS/外部参考权重。

### 5. 可直接背的回答

> 本项目没有把 GPS/气压动态互补作为最终主结果。如果按 alpha=0.98、dt=0.02s 计算，时间常数约为 1s。气压高度对天气很敏感，1hPa 约等于 8.4m 高度变化，所以 1 小时下降 3hPa 会造成约 25m 的高度漂移。解决方法是定期用 GPS 或已知高度重置 P0，或者把 P0 漂移作为状态估计，而不能长期只依赖气压计。

---

## Q15. I2C 总线上三个传感器如何调度？中断竞争怎么处理？

### 1. 老师到底在问什么

老师想看你是否理解嵌入式实时系统中总线共享和中断竞争。

本项目 I2C 总线挂了：

- MPU6050/MPU6500：`0x68`
- HMC5883L：`0x1E`
- BMP280：`0x76`

### 2. I2C 总线基本特点

I2C 是主从总线。

ESP32-S3 是主设备，传感器是从设备。所有读写都由 ESP32-S3 发起。

关键点：

> 同一时刻 I2C 总线上只能有一个事务。

所以不能同时读 MPU、HMC 和 BMP，必须排队。

### 3. 如何调度读取顺序

按传感器更新需求：

- IMU 频率最高，优先读。
- 磁力计频率中等。
- BMP280 气压变化慢，频率可以最低。

可用调度方式：

```text
每个循环读 IMU
每 N 个循环读磁力计
每 M 个循环读 BMP280
```

这样既保证姿态融合实时性，也减少总线占用。

### 4. MPU 中断在 BMP 读取途中触发会怎样

如果 MPU 的 data ready 中断在 BMP280 I2C 读取途中触发：

- 硬件上不会打断当前 I2C 事务。
- 中断只是通知“MPU 数据好了”。
- 正确做法是在中断服务函数里只置标志位。
- 当前 BMP 读完后，主循环或任务再处理 MPU 读取。

### 5. 多任务竞争怎么处理

如果 FreeRTOS 多个任务都可能访问 I2C，需要 mutex：

```text
take mutex
I2C read/write
give mutex
```

否则任务切换可能导致两个任务同时操作 I2C 驱动，造成通信异常。

### 6. 可直接背的回答

> I2C 是主从总线，ESP32-S3 控制所有时序，所以三个传感器不能同时读，必须由主控调度。我会让 IMU 高频读取，磁力计和 BMP280 低频读取。MPU 中断在 BMP280 读取途中触发时，不会打断当前 I2C 事务，中断里只置 data-ready 标志，等当前事务结束后再读 MPU。如果多个 FreeRTOS 任务访问 I2C，则必须用 mutex 保护总线。

---

# 第四类：系统工程与批判性思维

## Q16. MPU6050 安装倾斜能被六位置标定补偿吗？

### 1. 老师到底在问什么

老师想确认你理解“标定参数”和“机械安装状态”绑定。

如果传感器焊死在 PCB 上，安装误差是固定的，可以通过标定补偿。

如果传感器用杜邦线晃来晃去，安装误差每次都变，标定参数就失效。

### 2. 安装倾斜是什么

安装倾斜指的是：

> 传感器芯片坐标系和 PCB 板坐标系不完全重合。

比如板子 X 方向和 MPU 芯片 X 方向差了 1°。

这会导致真实 X 方向加速度投影到 Y/Z 轴，看起来像轴间耦合。

### 3. 六位置标定能不能补偿

能，但有前提：

- 传感器固定在 PCB 上。
- 标定后相对位置不再变化。
- 后续使用时仍保持同一安装状态。

补偿发生在：

```text
a_cal = A_inv · (a_raw - c)
```

其中 `A_inv` 的非对角项吸收安装角误差。

### 4. 什么情况不能补偿

如果传感器不是固定的，比如：

- 杜邦线连接
- 模块悬空
- 每次插拔角度不同

那安装关系会变。一次标定得到的 `A_inv` 只对当时状态有效，换个姿态就不准确。

### 5. 可直接背的回答

> 如果 MPU6050 固定焊接在 PCB 上，安装倾斜是固定误差，可以被六位置 12 参数标定补偿，主要体现在 A_inv 的非对角项里。补偿发生在 `A_inv · (raw-c)` 这一步。但如果传感器用杜邦线连接，每次相对角度都变，那么安装误差不是固定的，之前的标定参数就不能长期有效。

---

## Q17. 无人机电机启动后磁力计跳变，有哪些解决方案？

### 1. 老师到底在问什么

老师想看你能不能从系统工程角度解决磁干扰问题，而不是只说“屏蔽一下”。

电机启动后，磁力计跳变可能来自：

- 电机磁场。
- 电调电流。
- 电源线大电流。
- 机架铁磁材料。
- 高频 EMI。

### 2. 方案一：磁力计远离干扰源

做法：

- 用延伸杆把磁力计远离电机、电调和大电流线。

优点：

- 从源头降低干扰。
- 简单直接。

缺点：

- 结构复杂。
- 线缆变长，可能引入通信和振动问题。

### 3. 方案二：电流补偿

做法：

- 测量电机电流。
- 建立磁干扰和电流之间的模型。
- 飞行中根据电流补偿磁力计。

类似 ArduPilot 的 COMPASS_MOT 思路。

优点：

- 能补偿随油门变化的磁干扰。

缺点：

- 需要电流传感器。
- 需要专门标定。
- 对复杂干扰不一定完全有效。

### 4. 方案三：降低磁力计权重

做法：

- 当检测到磁场模长异常时，降低磁力计在姿态融合里的权重。
- 短时间更多依赖陀螺和其他传感器。

优点：

- 软件实现，不需要改硬件。

缺点：

- 长时间不用磁力计，Yaw 会漂。

### 5. 方案四：双天线 GNSS 测向

做法：

- 用双 GNSS 天线直接测航向。

优点：

- 不受电机磁场影响。
- 大型无人机上更可靠。

缺点：

- 成本高。
- 需要足够天线基线。
- 室内或遮挡环境不好用。

### 6. 我会选什么

优先级：

1. 先做硬件隔离：磁力计远离电机和大电流线。
2. 再做磁异常检测和电流补偿。
3. 如果是大型平台，再考虑双天线 GNSS。

### 7. 可直接背的回答

> 我会先从硬件上把磁力计远离电机、电调和大电流线，这是最直接有效的；其次可以做类似 COMPASS_MOT 的电流补偿，根据电流估计磁干扰；软件上还可以检测磁场模长异常，在异常时降低磁力计权重；如果是大型无人机，可以用双天线 GNSS 测向替代磁罗盘。单纯屏蔽不一定可靠，因为低频磁场很难用普通屏蔽完全消除。

---

## Q18. 如果重新设计 PCB，会改哪些 Layout？

### 1. 老师到底在问什么

老师想看你是否能批判性分析自己的硬件，而不是只说“下次优化布局”。

### 2. 不知道铺铜覆盖率怎么办

如果你没有精确计算背面铺铜覆盖率，不要乱报数字。

可以说：

> 我没有在答辩前精确统计铺铜覆盖率，但从这次调试结果看，下一版我会重点改磁力计位置、电源去耦和 I2C 参考地。

### 3. 改进点一：磁力计远离干扰源

问题：

- HMC5883L 对磁环境很敏感。
- 靠近 ESP32、USB、电源走线或大电流路径会影响 yaw。

改进：

- 把磁力计放到 PCB 边缘。
- 远离天线、电源芯片、USB 口、大电流走线。

收益：

- 降低磁场均值偏移和模长波动。
- 有助于降低航向角误差。

### 4. 改进点二：去耦电容靠近传感器

问题：

- 电源噪声会影响传感器读数。

改进：

- 每个传感器 VCC 附近放 0.1 uF 去耦电容。
- BMP280、HMC5883L、MPU 电源旁边尽量短回路。

收益：

- 降低电源纹波。
- 减少 uT 级磁场波动和 I2C 通信异常概率。

### 5. 改进点三：I2C 走线和参考地

问题：

- I2C 是数字信号，如果走线长、参考地不连续，容易产生毛刺。

改进：

- SDA/SCL 尽量短。
- 走线下方保持连续地平面。
- 上拉电阻靠近总线合适位置。
- 避免穿过电源噪声区域。

收益：

- 提高 400 kHz I2C 稳定性。
- 降低通信错误和边沿串扰。

### 6. 改进点四：地平面连续

问题：

- 地平面被切割会导致回流路径变长，增加 EMI。

改进：

- 保持连续铺地。
- 高速数字区和敏感传感器区合理分区。

收益：

- 减少数字噪声耦合到模拟/磁传感器。

### 7. 可直接背的回答

> 我没有精确统计铺铜覆盖率，但如果重新设计，我会优先改三点。第一，把 HMC5883L 放到远离 ESP32 天线、USB 和电源走线的位置，降低磁干扰。第二，把各传感器去耦电容更靠近电源引脚，减小电源纹波。第三，优化 I2C 走线，保证 SDA/SCL 短且有连续参考地，避免跨分割地。这样可以提高 I2C 稳定性，并降低磁力计模长波动和航向误差。

---

## Q19. 系统最终精度是多少？误差预算怎么做？

### 1. 老师到底在问什么

这是综合题。老师想看你是否知道每个结果的瓶颈在哪里，而不是只报一个数字。

### 2. 本项目可报精度

| 指标 | 当前结果 | 主要瓶颈 |
|---|---:|---|
| Roll 静态标准差 | 0.0746° | 加速度计噪声、安装误差、桌面水平度 |
| Pitch 静态标准差 | 0.1323° | 加速度计噪声、安装误差、桌面水平度 |
| 姿态静态 RMS | 0.1518° | 静态数据质量、滤波参数 |
| 航向平均绝对误差 | 1.907° | 磁环境、参考方向摆放、磁力计残差 |
| 航向最大误差 | 6.940° | 局部磁干扰、采集方向误差 |
| BMP 相对高度误差 | 0.030 m | P0、温度、气压环境、人工真值 |
| GPS 静态最大漂移 | 0.171 m | 卫星几何、室外环境、接收机噪声 |

### 3. Roll/Pitch 的瓶颈

Roll/Pitch 主要由重力方向约束，因此瓶颈是：

- 加速度计标定残差。
- 板子放置水平度。
- 静态振动和噪声。
- 滤波参数。

纯软件提升空间：

- 继续优化加速度计标定。
- 使用更好的异常检测和滤波。
- 提升有限，因为硬件和摆放误差已经成为重要因素。

### 4. Yaw/航向的瓶颈

Yaw 的瓶颈主要是磁力计：

- 磁环境干扰。
- HMC5883L 安装位置。
- 椭球拟合数据覆盖程度。
- 参考方向摆放误差。

纯软件提升空间：

- 鲁棒椭球拟合。
- 磁异常检测。
- 航向残差补偿。
- 但如果硬件环境磁干扰很大，纯软件提升有限。

### 5. 高度的瓶颈

BMP280 相对高度短时间表现较好，但长期高度瓶颈不是分辨率，而是：

- `P0` 参考气压。
- 天气气压漂移。
- 温度交叉敏感。
- 气流扰动。

### 6. 可直接背的回答

> 当前 Roll/Pitch 静态标准差分别约 0.0746° 和 0.1323°，静态 RMS 约 0.1518°；航向补偿后平均绝对误差约 1.907°，最大约 6.940°；BMP280 楼梯相对高度误差约 0.030 m；GPS 静态最大漂移约 0.171 m。误差瓶颈上，Roll/Pitch 主要受加速度计标定残差和平台水平度影响，Yaw 主要受磁干扰和参考方向影响，高度主要受 P0 和气压环境影响，而不是 BMP280 分辨率。现有硬件上，软件还能通过鲁棒磁标定、磁异常检测和更好的滤波继续改善，但如果磁环境和安装位置不变，Yaw 提升会有限。

---

## Q20. 如果装到真实大型垂起固定翼无人机，还缺什么？

### 1. 老师到底在问什么

老师想看你能不能从课程实验扩展到真实工程系统。

真实无人机和实验桌面最大区别是：

- 振动更强。
- 电机电流更大。
- 磁干扰更复杂。
- GNSS 会丢星或延迟。
- 温度、电源、机械冲击都更复杂。
- 安全性要求更高。

### 2. 优先改进点一：航向可靠性

问题：

- 无人机电机和电调会严重干扰磁力计。

改进：

- 磁力计延伸杆安装。
- 电流补偿。
- 磁异常检测。
- 双天线 GNSS 测向。

预期收益：

- 航向从数度级波动向 2°以内逼近。
- 悬停和航线跟踪更稳定。

### 3. 优先改进点二：动态 GNSS/INS 融合

问题：

- 当前项目主要是静态或离线验证，没有完整飞行动力学融合。

改进：

- IMU 高频预测。
- GNSS 低频校正。
- 处理 GPS 延迟、丢星、异常点。
- 增加速度和位置状态估计。

预期收益：

- 动态定位更连续。
- GPS 短时异常时系统不至于立刻失效。

### 4. 优先改进点三：工程可靠性

问题：

- 课程实验板还不是飞控级可靠系统。

改进：

- 电源冗余。
- EMI/EMC 优化。
- 振动隔离。
- 温度补偿。
- 日志和故障检测。

预期收益：

- 提高安全性和可追溯性。
- 让系统从实验验证走向工程应用。

### 5. 可直接背的回答

> 如果装到真实大型垂起固定翼无人机，我认为最缺的是工程可靠性和动态环境适应能力。第一要提升航向可靠性，包括磁力计远离电机、电流补偿和必要时双天线 GNSS 测向；第二要做真正的动态 GNSS/INS 融合，处理 GPS 延迟、丢星和异常点；第三要加强电源、EMC、振动隔离、温度补偿和日志系统。这样带来的提升不是单纯静态精度，而是飞行中的安全性和鲁棒性。

---

# 最后提醒：哪些话不能硬说

以下说法答辩时不要讲：

- 不要说动态 GPS 轨迹已经完整完成。
- 不要说航向所有方向都达到 ±2°。
- 不要说陀螺仪零偏漂移已经严格下降 10×。
- 不要说 AI 模型已经部署到 ESP32-S3 板端。
- 不要说 GNSS/INS 达到厘米级动态定位。
- 不要说 BMP280 绝对高度很准，应强调短时间相对高度。
- 不要说 Madgwick 是你的主结果，因为项目主展示是互补滤波和 Mahony。

答辩时更稳的说法是：

> 本项目已经完成硬件采集、传感器驱动、加速度计与磁力计标定、姿态融合、AI 离线去噪、BMP 相对高度和 GNSS 静态解析。部分动态 GPS/INS 和板端 AI 部署属于后续扩展，没有作为最终主结果。

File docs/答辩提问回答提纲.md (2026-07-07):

# 答辩提问回答提纲

原则：回答时以自己真实完成的实验为准。没做完整验证的内容不要硬说已经完成，可以回答“本项目中未作为最终主结果，但从原理上应这样处理”。

## 第一类：传感器物理与误差本质

### Q1. 六位置标定 12 参数分别对应哪些物理误差？

回答要点：

- 12 参数模型可以写成：

  `a_cal = A_inv * (a_raw - c)`

- `c` 是 3×1 零偏向量，对应 X/Y/Z 三轴在零输入时的固定偏移。
- `A_inv` 是 3×3 修正矩阵：
  - 对角线元素主要对应三轴比例因子/灵敏度误差。
  - 非对角线元素对应三轴非正交、轴间耦合、安装角误差。
- 如果只有零偏和各轴比例误差，没有轴间耦合，`A_inv` 应该退化为对角矩阵：

  `diag(kx, ky, kz)`

- 如果三轴比例也完全理想，那么 `A_inv` 接近单位矩阵，只剩下 `c` 起作用。

可答版本：

> 我的 12 参数中，3 个是零偏，9 个是比例因子和轴间耦合修正。理想情况下如果只有零偏，没有轴间耦合，A_inv 应该是对角矩阵，对角元素是各轴灵敏度修正系数；如果连比例误差也没有，它就接近单位阵。

### Q2. Allan 方差三段斜率和 KF 的 Q/R 有什么关系？

回答要点：

- 短时间段斜率约 `-1/2`：白噪声主导，对应角随机游走 ARW。
- 中段最低点：零偏稳定性最好的一段，可用于估计 bias instability。
- 长时间段斜率约 `+1/2`：零偏随机游走或慢漂移开始主导。
- 对 KF 的关系：
  - 陀螺仪白噪声影响量测噪声或角速度积分噪声，可用于设定 `R` 或陀螺测量噪声。
  - 零偏随机游走影响状态方程里的 bias 漂移，主要进入 `Q` 矩阵。

可答版本：

> Allan 曲线短时间 -1/2 斜率说明白噪声主导，也就是角随机游走；中间最低点代表零偏最稳定的时间尺度；长时间 +1/2 斜率说明慢漂移或零偏随机游走变明显。白噪声更多影响测量噪声 R，零偏随机游走对应状态噪声 Q 中 bias 状态的过程噪声。

### Q3. HMC5883L 分辨率 5 mGauss，实测 std 远大于它说明什么？

项目数据：

- 标定前磁场模长标准差：`3.303 uT`
- 标定后磁场模长标准差：`1.892 uT`
- 5 mGauss = `0.5 uT`

回答要点：

- 校准后 `1.892 uT` 仍大于数据手册分辨率 `0.5 uT`。
- 这不一定说明算法错了，因为 datasheet 分辨率只是理想量化/输出分辨率，不等于整机系统误差。
- 主要可能来自：
  - 周围铁磁物体和电流造成的磁干扰。
  - PCB 走线、电源噪声和去耦不足。
  - 采集旋转不均匀，椭球拟合残差较大。
  - HMC5883L 本身老旧，模块一致性有限。

可答版本：

> 我的标定后模长标准差约 1.892 uT，确实大于 5 mGauss，也就是 0.5 uT。这说明当前误差主要不是量化分辨率限制，而是系统级误差，包括磁环境干扰、PCB 电源和布局影响、采集覆盖不均匀以及传感器本身噪声。

### Q4. 气压计测高误差预算怎么分解？

项目数据：

- 人工测量楼层高度：`3.950 m`
- BMP280 测量相对高度：`3.980 m`
- 绝对误差：`0.030 m`
- 相对误差：`0.76%`

回答要点：

- 气压高度公式本质依赖参考气压 `P0`。
- 短时间相对高度实验中，BMP280 分辨率不是主要误差。
- 误差来源：
  - `P0` 参考气压标定误差：通常是主导项。
  - 温度补偿误差：影响气压换算。
  - 天气气压漂移：长时间实验会变成主导项。
  - 楼层真实高度测量误差。
  - 窗口平均和动态气流扰动。

可答版本：

> 我这次楼梯实验的相对误差约 3 cm。短时间相对测高里，BMP280 分辨率不是主要瓶颈，主要瓶颈是 P0 校准、环境气压变化、温度交叉敏感和人工高度参考。长时间测试时，天气气压漂移会比传感器分辨率更重要。

### Q5. HMC5883L 离 WiFi 天线距离变化会怎样影响航向？

回答要点：

- 如果磁力计离 ESP32 WiFi 天线或大电流路径更近，可能引入电磁干扰和局部磁场扰动。
- 距离从 15 mm 减到 5 mm，干扰通常会明显增大，航向角波动和偏移都会变大。
- 实验验证方法：
  - 固定板子方向不动。
  - 分别关闭 WiFi、打开 WiFi、连续发包。
  - 记录磁场三轴、模长、yaw 标准差。
  - 比较 yaw std、模长 std 和均值偏移。

可答版本：

> 距离变近会增加磁力计受到的电磁和电源干扰，航向角可能出现固定偏移和更大波动。我会用开关 WiFi 对比实验验证：固定姿态，分别记录 WiFi 关闭和高负载发包时的磁场模长标准差与 yaw 标准差。

## 第二类：标定算法的数学深度

### Q6. 椭球拟合为什么取最小奇异值对应右奇异向量？

回答要点：

- 椭球拟合齐次方程：`Phi q = 0`。
- 不能取零解，所以约束 `||q|| = 1`。
- 目标是让残差 `||Phi q||` 最小。
- SVD 中最小奇异值对应的右奇异向量，就是单位长度条件下残差最小的方向。
- 如果数据只覆盖半个球面：
  - 某些方向约束不足。
  - 奇异值可能接近退化。
  - 解不稳定，椭球轴长和中心可能严重偏移。

可答版本：

> 因为齐次方程不能直接取 q=0，所以加单位范数约束后，本质是求使 ||Phi q|| 最小的方向。SVD 中最小奇异值对应的右奇异向量正是最小残差方向。如果只采半个球面，约束不充分，奇异值会退化，解会变得不唯一或非常不稳定。

### Q7. 桌面倾斜 2° 会进入六位置标定结果吗？如何消除？

回答要点：

- 会影响每个面的“真实重力方向”。
- 如果直接把每个面当作完全标准的 ±X/±Y/±Z，桌面倾斜会被模型吸收到 `A_inv` 的非对角项里。
- 但六位置标定本质利用的是重力模长 `|g|=1`，如果算法用模长约束或多姿态拟合，可以减小单个桌面不水平带来的影响。
- 消除方法：
  - 使用水平仪或调平平台。
  - 多次换方向采集并平均。
  - 使用更多随机姿态的球面标定，而不是只依赖六个理想面。
  - 用高精度夹具。

可答版本：

> 会进入结果。如果桌面倾斜而我还把它当成理想六方向，模型会把这部分误差吸收到安装误差或非正交矩阵里。消除方法是用水平平台、夹具，或者使用更多姿态并利用重力模长约束做自校准。

### Q8. 温度补偿二次多项式系数怎么确定？外推到 60°C 会怎样？

回答要点：

- 系数通过不同温度下静态采集零偏数据，然后最小二乘拟合 `b(T)=α+βT+γT²`。
- 20-50°C 内使用是插值。
- 60°C 使用是外推。
- 外推误差通常不可控，高阶多项式可能在区间外放大误差，甚至出现振荡。
- 属于模型外推误差/模型适用范围误差。

项目注意：

- 如果你没有完整做温度箱实验，要说“我的项目主要完成 Allan 和静态噪声分析，温度补偿属于可扩展方法”。

可答版本：

> 系数应通过不同温度点下采集陀螺零偏，然后最小二乘拟合得到。20 到 50°C 内属于插值，60°C 属于外推，误差会明显增大，因为多项式在标定区间外没有约束，甚至可能出现 Runge 现象。这属于模型外推误差。

### Q9. 离群点对 SVD 椭球拟合有什么影响？如何降低？

回答要点：

- 标准 SVD/最小二乘对离群点敏感，因为 L2 损失会放大大残差点影响。
- 一个手机靠近造成的磁异常可能拉偏椭球中心和轴长。
- 解决方法：
  - 采集前做实时模长范围检查。
  - 用 RANSAC 剔除离群点。
  - 用 Huber 损失、Tukey 损失等鲁棒估计替代普通 L2。
  - 先按模长、三轴范围、残差阈值剔除异常点，再拟合。

可答版本：

> 离群点会显著影响普通最小二乘，因为大残差会被平方放大，可能导致椭球中心和软铁矩阵被拉偏。可以用 RANSAC、Huber 损失或拟合前的模长阈值筛选来提高鲁棒性。

### Q10. BMP280 的 t_fine 是什么？温压读取相差 100 ms 会怎样？

回答要点：

- `t_fine` 是 Bosch 补偿算法中的中间温度变量。
- 它不是最终温度，而是用温度 ADC 和温度校准系数算出的高精度内部温度补偿量。
- BMP280 的压力测量受温度影响，所以压力补偿公式要使用 `t_fine`。
- 如果温度和气压读取间隔较大：
  - 在温度变化快的环境中，压力补偿使用的温度不匹配。
  - 会引入温度交叉敏感误差。
  - 100 ms 在室内慢温变下通常很小，但在热风、手触、快速气流下会变明显。

可答版本：

> t_fine 是温度补偿计算出的内部精细温度量，压力补偿也要用它，因为压力传感器本身存在温度交叉敏感。温度和压力读取相差 100 ms 时，如果环境温度变化快，就会用错误温度补偿压力，产生交叉敏感误差；室内慢温变时影响较小。

## 第三类：融合算法的工程理解

### Q11. Madgwick 的 beta 怎么选？快速机动有什么影响？

项目注意：

- 你的最终项目主要实现的是互补滤波和 Mahony 滤波，不要硬说实现了 Madgwick。

回答方式：

> 本项目最终展示的是互补滤波和 Mahony 滤波，没有把 Madgwick 作为主结果。如果从 Madgwick 原理看，beta 是梯度下降校正项权重，beta 越大，越相信加速度计/磁力计修正，收敛快但动态机动时容易被非重力加速度误导；beta 越小，越相信陀螺积分，动态响应更平滑但长期漂移更大。飞机快速急转时，加速度计测到的不再只是重力，所以 beta 应适当降低。

### Q12. Roll/Pitch 和 Yaw 精度是多少？为什么 Yaw 更差？

项目数据：

- ESKF roll std：`0.074643°`
- ESKF pitch std：`0.132308°`
- 静态稳定 RMS：`0.151800°`
- 航向残差补偿后平均绝对误差：`1.907°`
- 航向残差补偿后最大绝对误差：`6.940°`

回答要点：

- Roll/Pitch 可由加速度计观测重力方向，因此静态可观测。
- Yaw 是绕重力方向旋转，加速度计无法约束，必须依赖磁力计或 GNSS/视觉等外部参考。
- 去掉磁力计后，Yaw 只能靠陀螺积分，会随零偏漂移。
- 10 分钟漂移估计：`漂移角 ≈ 陀螺零偏 deg/s × 600 s`。

可答版本：

> 静态实验中 Roll/Pitch 的 1σ 稳定性约 0.075° 和 0.132°，RMS 约 0.152°。Yaw 经过残差补偿后平均绝对误差约 1.91°，最大约 6.94°。Yaw 更差是因为加速度计只能约束重力方向，也就是 Roll/Pitch，绕重力轴的 Yaw 对加速度计不可观，必须依赖磁力计，而磁力计又容易受环境干扰。若去掉磁力计，10 分钟漂移可按陀螺零偏乘 600 秒估算。

### Q13. KF 的 Q 矩阵代表什么？Q 过大过小会怎样？

回答要点：

- `Q` 是过程噪声协方差，表示模型预测本身有多不可靠。
- `R` 是观测噪声协方差，表示传感器观测有多不可靠。
- Q 太小：
  - 滤波器过度相信模型。
  - 对真实变化反应慢。
  - 可能出现过度自信，严重时发散。
- Q 太大：
  - 过度相信观测。
  - 曲线变抖，滤波效果变差。
  - 近似退化为直接跟随测量。

项目注意：

- 如果问高度 KF，你可以说本项目主要完成 BMP 相对高度实验和静态分析，KF 参数更多是工程扩展。

可答版本：

> Q 表示状态模型的不确定性。Q 设得太小，滤波器会过度相信预测，真实高度变化时跟踪慢，严重时出现 over-confidence 甚至发散；Q 设得太大，则过度相信观测，输出会抖，滤波效果减弱。

### Q14. GPS/气压互补 alpha=0.98 对应时间常数？台风气压漂移怎么办？

项目注意：

- 你没有把 GPS/气压动态互补作为最终主结果，回答时先说明。

原理回答：

- 一阶低通/互补滤波时间常数近似：`tau = dt / (1 - alpha)`。
- 如果 `dt = 0.02 s`，`alpha=0.98`，则 `tau ≈ 1 s`。
- 气压变化 1 hPa 约对应 8.4 m 高度变化。
- 3 hPa 约对应 `25.2 m` 高度误差。
- 气象慢漂会完全渗透到气压高度中，因此需要：
  - 定期用 GPS 或已知高度重置 `P0`。
  - 引入气象站参考气压。
  - 对气压慢漂单独建模。
  - 动态调整 alpha。

可答版本：

> 本项目没有把 GPS/气压动态互补作为最终主结果。如果按 alpha=0.98、dt=0.02 s 估算，时间常数约 1 s。台风前 1 小时下降 3 hPa，会造成约 25 m 的气压高度漂移，因此必须定期用 GPS 或已知高度重置 P0，不能长期只信气压高度。

### Q15. I2C 多设备读取怎么调度？中断竞争怎么处理？

回答要点：

- I2C 是主从总线，ESP32-S3 是主设备，所有读写由主设备发起。
- 同一时刻总线上只能有一个事务。
- MPU 中断只是提醒数据就绪，不会物理上打断正在进行的 BMP280 I2C 读操作。
- 程序上应该：
  - 高频读取 IMU。
  - 磁力计、BMP280 低频读取。
  - 所有 I2C 访问用同一任务串行调度，或用 mutex 保护。
  - 中断中只置标志位，不直接做 I2C 读写。

可答版本：

> I2C 是主设备控制时序，所以即使 MPU 中断在 BMP280 读取中触发，也不会打断当前 I2C 事务。正确做法是中断里只置 data-ready 标志，在任务里按优先级调度读取；如果多任务访问 I2C，则必须用 mutex 保证一次只有一个 I2C 事务。

## 第四类：系统工程与批判性思维

### Q16. 安装倾斜能被六位置标定补偿吗？

回答要点：

- 如果传感器固定在 PCB 上，且标定后不再移动，安装倾斜可以被 12 参数模型中的非对角项吸收。
- 补偿发生在 `A_inv * (raw - c)` 这一步。
- 如果传感器不是固定安装，比如杜邦线每次弯折位置不同，那么安装关系变化，旧标定参数失效。

可答版本：

> 可以补偿固定安装后的安装角误差，主要体现在 A_inv 的非对角项里。前提是标定后传感器和板子的相对姿态不再变化。如果用杜邦线悬空连接，每次姿态都变，就不能靠一次标定长期补偿。

### Q17. 无人机电机启动后磁力计跳变怎么办？

方案：

1. 磁力计远离电机和电源线，例如延伸杆安装。
   - 优点：从源头降低干扰。
   - 缺点：结构复杂，线缆更长。
2. 做电流补偿，类似 ArduPilot COMPASS_MOT。
   - 优点：能补偿随电流变化的磁干扰。
   - 缺点：需要电流传感器和标定。
3. 飞行中降低磁力计权重，更多依赖陀螺、GPS 航向或视觉。
   - 优点：动态抗干扰更好。
   - 缺点：低速或悬停时 yaw 约束变弱。
4. 双天线 GNSS 测向替代磁罗盘。
   - 优点：不受电机磁场影响。
   - 缺点：成本和尺寸更高。

可答版本：

> 我会优先把磁力计远离电机和大电流线，同时做电流相关补偿。如果是大型平台，可以考虑双天线 GNSS 测向。单纯屏蔽不一定有效，因为低频磁场很难靠普通屏蔽解决。

### Q18. 如果重新设计 PCB，改哪些 Layout？

可答三点：

1. 磁力计远离 ESP32 天线、USB、电源和大电流走线。
   - 预期收益：降低磁场偏置和 yaw 波动。
2. 传感器电源去耦电容更靠近 VCC/GND 引脚。
   - 预期收益：降低电源纹波和 I2C/ADC 噪声，改善 uT 级磁场波动。
3. I2C 走线短、等长、有连续参考地，避免跨分割地。
   - 预期收益：降低通信毛刺，提高 400 kHz I2C 稳定性。
4. 地平面连续铺铜，模拟传感器下方避免高速数字线穿过。
   - 预期收益：降低 EMI 耦合。

如果不知道铺铜覆盖率，不要乱报：

> 我没有在答辩前精确计算背面铺铜覆盖率，但从工程角度，下一版会优先保证连续地平面和磁力计区域远离高频/大电流干扰源。

### Q19. 系统最终精度和误差预算

项目可报数据：

| 指标 | 当前结果 | 主要瓶颈 |
|---|---:|---|
| Roll 静态标准差 | 0.0746° | 加速度计噪声、安装姿态、桌面水平度 |
| Pitch 静态标准差 | 0.1323° | 加速度计噪声、安装姿态、桌面水平度 |
| 姿态 RMS | 0.1518° | 静态数据质量和滤波参数 |
| 航向平均绝对误差 | 1.907° | 磁干扰、参考方向摆放、磁力计标定残差 |
| 航向最大误差 | 6.940° | 局部磁环境和采集方向误差 |
| BMP 相对高度误差 | 0.030 m | P0 参考、温度、气压环境、人工真值 |

回答要点：

- Roll/Pitch 瓶颈主要是加速度计标定残差和静态平台误差。
- Yaw/航向瓶颈主要是磁环境，不是算法本身。
- 高度瓶颈主要是 P0 和环境气压漂移，不是 BMP280 分辨率。
- 纯软件还能提升：
  - 航向通过鲁棒椭球拟合、在线磁异常检测可能提升。
  - 高度通过 GPS/气压/已知高度重置 P0 改善长期漂移。
  - Roll/Pitch 提升空间较小，更多依赖机械固定和标定条件。

可答版本：

> 当前 Roll/Pitch 静态标准差约 0.075° 和 0.132°，航向平均绝对误差约 1.91°，最大约 6.94°，BMP 相对高度误差约 0.03 m。Roll/Pitch 的瓶颈是加速度计残差和静态平台，Yaw 的瓶颈是磁干扰，高度的瓶颈是 P0 和气象漂移。现有硬件上，航向通过鲁棒标定和磁异常检测还有提升空间。

### Q20. 装到真实大型垂起固定翼还缺什么？

优先改进三点：

1. 航向系统可靠性
   - 磁力计延伸杆、电流补偿、双 GNSS 测向。
   - 预期：降低电机磁干扰，航向误差从数度级向 2°以内逼近。
2. 动态 GNSS/INS 融合
   - 真正实现 IMU 高频预测 + GNSS 低频校正。
   - 增加丢星、延迟、异常值检测。
   - 预期：提升动态位置和速度估计稳定性。
3. 工程可靠性
   - 电源冗余、EMC、振动隔离、温度补偿、日志系统。
   - 预期：提升飞行安全性，而不仅是静态精度。

可答版本：

> 如果装到真实 VTOL，无人机电机、电源和振动都会比实验室复杂得多。我会优先改航向可靠性、动态 GNSS/INS 融合和工程可靠性。特别是磁力计必须远离电机并做电流补偿，动态融合要考虑 GPS 延迟、丢星和异常点，硬件上还要考虑振动、电源冗余和 EMI。

## 不要硬说的内容

- 不要说动态 GPS 轨迹已经完成。
- 不要说航向所有方向都达到 ±2°。
- 不要说陀螺仪零偏漂移严格下降 10×。
- 不要说 AI 模型已经板端部署。
- 不要说 GNSS/INS 达到厘米级动态定位。
- 不要说 BMP280 绝对高度很准，应强调短时间相对高度。

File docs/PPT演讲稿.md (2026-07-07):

# ESP32-S3 多传感器融合项目汇报演讲稿

说明：本稿按 17 页 PPT 编写，语气偏正式，适合课堂汇报。讲述时以实测数据为准，避免把静态实验或离线分析说成完整工程部署。

## 第 1 页：标题页

各位老师、同学好，我汇报的题目是《ESP32-S3 多传感器融合扩展板与精度提升结果展示》。

本项目围绕课程中对传感器驱动、PCB 硬件设计、传感器标定、多传感器融合以及实验验证的要求展开。系统以 ESP32-S3 为主控，外接 IMU、磁力计、气压计和 GNSS 模块，通过板端固件完成数据采集和串口输出，再在 PC 端用 Python 完成标定、融合分析和可视化。

我这次汇报主要分三部分：第一是系统硬件和总体架构；第二是加速度计、磁力计、陀螺仪等传感器的标定和精度提升；第三是姿态融合、AI 去噪、BMP 高度实验、GNSS 解析和系统性能测试结果。

## 第 2 页：目录

本次汇报按照四个部分展开。

第一部分介绍项目概述与系统设计，包括主控、传感器和上位机分析链路。

第二部分是传感器标定与精度提升，重点包括加速度计六位置 12 参数标定、磁力计椭球标定和航向残差补偿。

第三部分是姿态融合与系统性能，包括互补滤波、Mahony 滤波、Allan 方差、AI 去噪、BMP 高度实验、GNSS 静态分析和更新频率测试。

最后一部分是总结与附录，汇总当前已经完成的内容和仍然适合作为后续扩展的部分。

## 第 3 页：项目概述与系统设计

这一页展示的是系统整体结构。

硬件上，系统以 ESP32-S3 为主控，连接 MPU6500/MPU6050 兼容 IMU、HMC5883L 三轴磁力计、BMP280 气压计和 GNSS 模块。IMU、磁力计和 BMP280 主要通过 I2C 总线完成数据交互，GNSS 模块通过 UART 输出 NMEA 数据。

软件上，ESP32-S3 负责传感器初始化、周期采样、时间戳记录、姿态计算和串口输出。PC 端 Python 程序负责读取串口数据，并完成离线标定、精度分析、融合算法对比和图表生成。

整个系统的目标不是单独读取某一个传感器，而是把硬件采集、传感器误差补偿、姿态估计和实验验证连成一个完整流程。

## 第 4 页：加速度计六位置 12 参数标定

这一页是加速度计标定结果。

加速度计原始数据会受到零偏、比例因子误差和三轴不正交等影响，所以我采用六位置静态标定方法，建立 12 参数误差模型。这里的 12 个参数包括一个 3×3 误差矩阵和 3 个零偏参数，用来修正三轴之间的比例和交叉耦合误差。

从结果看，标定前平均误差约为 20.068 mg，标定后平均向量误差降到 1.798 mg，已经达到约 2 mg 的目标水平。

最大误差方面，标定前最大误差约为 55.789 mg，标定后最大向量误差为 2.120 mg。这个最大值略高于 2 mg，但已经非常接近目标阈值。

所以这一部分的结论是：加速度计 12 参数标定明显降低了静态测量误差，为后续姿态融合提供了更可靠的加速度输入。

## 第 5 页：磁力计椭球标定

这一页展示的是磁力计三维点云标定前后的变化。

磁力计容易受到硬铁和软铁干扰。硬铁误差主要表现为磁场中心偏移，软铁误差会造成三轴比例变化和椭球畸变。因此，理想情况下，板子在空间中旋转一圈后，磁力计三维数据应该接近一个球面；如果存在干扰，点云就会偏移或变成椭球。

图中左侧是标定前的数据，点云明显不是以原点为中心的规则球面；右侧是椭球拟合补偿后的结果，点云分布更接近球面。

这说明通过椭球拟合可以同时补偿硬铁偏移和软铁缩放误差，使磁力计输出更适合用于航向角估计。

## 第 6 页：磁力计模长稳定性

这一页从模长角度进一步量化磁力计标定效果。

标定前，磁场模长均值和标准差为 46.285 / 3.303 uT；标定后，模长均值和标准差变为 52.248 / 1.892 uT。

这里最关键的是标准差从 3.303 uT 降到 1.892 uT，下降约 42.7%。这说明标定后磁场模长的一致性更好，数据波动更小。

磁力计模长稳定之后，航向角计算受到异常缩放和偏移的影响会减小。但需要说明的是，磁力计仍然会受周围磁环境影响，所以后面又进一步做了航向残差补偿。

## 第 7 页：航向残差补偿

这一页是航向角残差补偿结果。

在完成磁力计椭球标定后，航向角仍然可能存在安装方向误差、参考方向摆放误差以及局部磁场干扰导致的系统偏差。因此我又基于多方向参考数据做了残差补偿。

补偿后的验证结果中，RMSE 为 2.83°，平均绝对误差为 1.91°，最大绝对误差为 6.94°。

这里需要客观说明：平均绝对误差已经接近 2°目标，但是最大误差仍然超过 2°。因此不能说所有方向都达到 ±2°，只能说残差补偿有效降低了整体系统性偏差，平均误差已经接近目标。

后续如果要继续提升航向精度，需要改善参考方向标定方法，并尽量远离铁磁物体和电流干扰源。

## 第 8 页：姿态融合与实时显示

这一页展示的是姿态融合算法和实时显示结果。

项目中实现了两种传统姿态融合算法：互补滤波和 Mahony 滤波。互补滤波主要利用陀螺仪短时响应快、加速度计长期稳定的特点，把两者进行频域互补。Mahony 滤波则通过姿态误差反馈来修正陀螺仪积分漂移。

同时，我实现了网页端实时姿态显示，可以显示 Roll、Pitch、Yaw、气压高度、磁场模长等信息。通过实际晃动板子，可以观察到网页中模型随板子姿态变化而变化。

静态稳定性方面，ESKF 静态分析中姿态稳定 RMS 为 0.1518°，1σ 静态精度满足 0.2°级要求。这说明在静态条件下，姿态输出具有较好的稳定性。

## 第 9 页：陀螺仪 Allan 方差

这一页是陀螺仪 Allan 方差分析。

陀螺仪噪声不是一个简单常数，它会随着平均时间不同表现出不同特性，比如角随机游走、零偏不稳定性等。为了分析这些特性，我采集了约 300 秒的静态陀螺仪数据，并绘制 Allan 方差曲线。

图中三条曲线分别对应 X、Y、Z 三轴。通过曲线不同时间尺度下的斜率，可以分析陀螺仪噪声随平均时间变化的趋势。

这一部分的作用主要是完成噪声特性分析，为后续滤波器参数选择提供依据。这里不把它说成已经严格证明零偏漂移下降 10 倍，因为当前实验主要完成的是 Allan 方差分析，而不是完整的前后漂移 10 倍验证。

## 第 10 页：AI 增强 IMU 去噪

这一页是 AI 增强去噪实验。

这里我做的是离线静态 IMU 去噪对比，不是板端实时部署。实验中对比了三种方法：传统低通滤波、1D 卷积去噪，以及 1D 卷积加一阶 Kalman 平滑的混合结构。

从结果看，加速度计平均 SNR 提升方面，传统低通为 9.69 dB，1D 卷积为 18.12 dB，1D 卷积加 Kalman 为 18.69 dB。

陀螺仪方面，传统低通为 12.30 dB，1D 卷积为 15.70 dB，混合结构为 15.84 dB。

因此可以看出，1D 卷积对静态 IMU 噪声有明显抑制效果，尤其在加速度计数据上提升更明显。混合 Kalman 后结果略有提升，但提升幅度不算特别大。

## 第 11 页：BMP280 楼梯高度实验

这一页是 BMP280 气压高度实验。

我用人工测量的楼层高度作为参考，实测楼层高度为 3.950 m。然后通过 BMP280 采集气压数据，换算相对高度变化。

实验结果中，BMP280 测得的相对高度为 3.980 m，与人工测量高度的绝对误差为 0.030 m，相对误差约 0.76%。

这说明在短时间、同一环境条件下，BMP280 用于相对高度变化测量是可行的，尤其适合楼层变化、台阶高度变化这类相对高度场景。

## 第 12 页：GNSS/NMEA 与静态松耦合

这一页是 GNSS 相关实验。

本项目完成了 GNSS 模块的 UART 接入，并实现了 NMEA 语句解析，主要解析 GGA、RMC 等包含经纬度、高度、速度、卫星数和定位质量的信息。

图中展示的是静态条件下的 GNSS/INS 松耦合分析结果，主要用于验证 GPS 数据链路、解析流程和静态融合流程是否打通。

需要说明的是，这里展示的是静态分析，不是完整的户外动态轨迹实验。由于没有获得可靠的户外动态有效轨迹，所以动态 GPS 轨迹叠加不作为本项目的主结果，只作为后续扩展方向。

## 第 13 页：系统性能与更新频率

这一页是板端性能测试结果。

在高速测试模式下，系统主循环更新频率约为 229.62 Hz，IMU 数据采样频率约为 229.62 Hz，互补滤波和 Mahony 滤波的更新频率也约为 229.62 Hz。

算法计算耗时方面，互补滤波单次计算耗时约为 52.39 us，Mahony 滤波单次耗时约为 69.52 us。高速模式下 CPU 占用约为 4.30%。

这些结果说明，当前固件在 ESP32-S3 上能够满足 200 Hz 以上传感器采样和 100 Hz 以上姿态更新的要求，姿态算法计算开销也比较低，适合嵌入式实时运行。

## 第 14 页：总结

这一页是系统总体达标情况。

硬件方面，完成了 ESP32-S3 扩展板和多传感器连接验证，IMU、磁力计、BMP280 和 GNSS 模块都可以采集数据。

驱动方面，完成了 I2C 多设备管理、IMU、磁力计、BMP280 以及 GNSS NMEA 数据解析。

标定方面，完成了加速度计六位置 12 参数标定、磁力计椭球标定、航向残差补偿和 Allan 方差分析。

融合方面，实现了互补滤波和 Mahony 滤波，并完成了 Web 实时姿态显示。AI 增强方面，完成了离线 1D 卷积 IMU 去噪对比。环境感知方面，完成了 BMP280 楼梯高度实验。

GPS 动态轨迹部分没有作为最终主结果展示，主要原因是没有可靠的户外动态有效轨迹数据，这部分更适合作为后续扩展。

## 第 15 页：GPS 静态定位散点图

这一页作为附录，展示 GPS 静态定位散点图。

这张图来自静态条件下的 GPS 有效定位数据，共有 239 个有效定位点。平均坐标为纬度 26.030476°N，经度 119.193105°E。

最大水平漂移为 0.171 m，平均水平偏移为 0.102 m，HDOP 平均约为 0.96，卫星数平均约为 14.6。

所以这张图可以说明模块在静态条件下定位点分布较集中，但它不能代表动态轨迹精度，也不能替代户外运动轨迹测试。

## 第 16 页：GPS 静态漂移与高度变化

这一页继续展示 GPS 静态状态下的漂移和高度变化。

水平定位方面，平均偏移为 0.102 m，标准差为 0.043 m，最大值为 0.171 m。高度方面，平均高度为 33.37 m，标准差为 0.078 m，最大值为 33.50 m。

这些结果可以作为静态定位稳定性的补充说明。需要注意的是，GPS 高度本身通常比水平定位更容易波动，因此这里主要用于观察静态变化趋势，不作为高精度高度测量的唯一依据。

## 第 17 页：结束页

以上就是我的汇报。

总体来说，本项目完成了 ESP32-S3 多传感器扩展板从硬件接入、传感器驱动、误差标定、姿态融合、AI 去噪、气压高度实验到上位机可视化的一整套流程。实验结果表明，加速度计、磁力计和 BMP280 的标定与分析均取得了明显效果，姿态融合和系统更新频率也满足课程设计的主要要求。

不足之处主要是动态 GPS 轨迹没有形成可靠的有效数据，航向最大误差仍然受到磁环境影响。后续可以继续改进户外采集方式、优化磁力计安装环境，并进一步完善 GNSS/INS 动态融合。

我的汇报结束，谢谢各位老师和同学。

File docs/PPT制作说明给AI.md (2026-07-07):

# PPT 制作说明给 AI

请根据以下要求制作课程项目结果展示 PPT。不要重新编造数据，只使用给定图片和数据。

## 1. 基本要求

PPT 主题：

> ESP32-S3 多传感器融合扩展板与精度提升结果展示

整体风格：

- 学术汇报风格，白底或浅灰底，蓝色/黑色作为主色。
- 每页不要堆太多文字，一页一个重点。
- 图片优先放大展示，数据表只保留关键指标。
- 所有图都用 PNG 图片，不要用 SVG。
- 图片路径来自 `ppt_assets/` 文件夹。
- 建议 10-12 页。

## 2. 页面安排

### 第 1 页：标题页

标题：

> ESP32-S3 多传感器融合扩展板与精度提升结果展示

副标题：

> 传感与检测技术课程项目

排版：

- 居中大标题。
- 下方放 3 个关键词：硬件设计 / 传感器标定 / 多传感器融合。
- 不需要放实验图。

### 第 2 页：系统总体架构

标题：

> 系统完成了从硬件采集到上位机分析的完整链路

图片：

- `ppt_assets/01_system_architecture.png`

排版：

- 左侧 30% 放 3 条文字：
  - ESP32-S3 负责传感器初始化、采样和串口输出。
  - IMU、磁力计、BMP280 与 GNSS 形成多源数据输入。
  - PC 端 Python 完成标定、融合分析和图表生成。
- 右侧 70% 放系统架构图，尽量放大。

### 第 3 页：加速度计六位置 12 参数标定

标题：

> 六位置 12 参数标定把加速度计平均误差降到约 2 mg

图片：

- `ppt_assets/02_accel_calibration_errors.png`

排版：

- 左侧放图片，占 60%。
- 右侧放关键数据表：

| 指标 | 标定前 | 标定后 |
|---|---:|---:|
| 平均误差 | 20.068 mg | 1.798 mg |
| 最大向量误差 | - | 2.120 mg |
| 目标值 | - | 2.000 mg |

页面底部一句结论：

> 平均向量误差达到约 2 mg 目标水平，最大误差略高但接近阈值。

### 第 4 页：磁力计椭球标定

标题：

> 椭球拟合让磁力计点云从偏移椭球收敛到近似球面

图片：

- `ppt_assets/03_mag_3d_scatter_before_after.png`

排版：

- 图片居中，占页面 75% 宽度。
- 右下角或底部放 3 条说明：
  - 原始点云受硬铁和软铁误差影响。
  - 标定后点云更接近球面。
  - 用于后续航向角补偿。

### 第 5 页：磁力计模长稳定性

标题：

> 磁力计校准后模长波动明显减小

图片：

- `ppt_assets/04_mag_norm_before_after.png`

排版：

- 左侧放图片，占 65%。
- 右侧放数据：
  - 标定前模长均值/标准差：46.285 / 3.303 uT。
  - 标定后模长均值/标准差：52.248 / 1.892 uT。
  - 标准差下降约：42.7%。

结论：

> 椭球标定提高了磁场模长一致性，为航向估计提供更稳定输入。

### 第 6 页：航向残差补偿

标题：

> 航向残差补偿降低了系统性角度偏差

图片：

- `ppt_assets/05_heading_residual_errors.png`

排版：

- 上半页放图。
- 下半页放 3 个大数字卡片：

| 指标 | 数值 |
|---|---:|
| RMSE | 2.833° |
| 平均绝对误差 | 1.907° |
| 最大绝对误差 | 6.940° |

注意文字：

> 平均绝对误差接近 2°，但最大误差仍受磁环境和参考方向摆放影响，不写成所有方向均达 ±2°。

### 第 7 页：姿态融合与实时显示

标题：

> 互补滤波和 Mahony 滤波支持实时姿态显示

图片：

- `ppt_assets/06_attitude_algorithm_compare.png`

排版：

- 左侧放算法对比图，占 60%。
- 右侧放说明：
  - 已实现算法：互补滤波、Mahony 滤波。
  - Web 实时显示：Roll / Pitch / Yaw、气压高度、磁场模长。
- 右下角放静态稳定性：
  - 静态稳定 RMS：0.151800°。
  - 1σ 静态精度满足 ≤0.2°。

### 第 8 页：陀螺仪 Allan 方差

标题：

> Allan 方差用于分析陀螺仪噪声与零偏稳定性

图片：

- `ppt_assets/07_gyro_allan_deviation.png`

排版：

- 图片居中放大，占页面 70%。
- 底部放 2 条说明：
  - 使用 300 s 级静态陀螺数据进行 Allan 方差分析。
  - 结果用于估计噪声特性和辅助滤波器参数选择。

注意：

> 不要写“严格证明零偏漂移下降 10×”，除非另有数据。

### 第 9 页：AI 增强 IMU 去噪

标题：

> 1D 卷积去噪提高了 IMU 静态信号 SNR

图片：

- 这一页可以不用图片，用表格和柱状图。

排版：

- 左侧放表格：

| 对象 | 传统低通 | 1D 卷积 | 1D 卷积 + Kalman |
|---|---:|---:|---:|
| 加速度计平均 SNR 提升 | 9.686 dB | 18.121 dB | 18.687 dB |
| 陀螺仪平均 SNR 提升 | 12.299 dB | 15.697 dB | 15.837 dB |

- 右侧做一个简单柱状图，分加速度计和陀螺仪两组。

结论：

> 1D 卷积相对传统低通提升更明显，混合 Kalman 在加速度计结果上略优。

### 第 10 页：BMP280 楼梯高度实验

标题：

> BMP280 在楼梯实验中实现 3 cm 级相对高度误差

图片：

- `ppt_assets/08_bmp_stair_height.png`

排版：

- 左侧放曲线图，占 65%。
- 右侧放数据卡片：

| 指标 | 数值 |
|---|---:|
| 人工测量高度 | 3.950 m |
| BMP280 测量高度 | 3.980 m |
| 绝对误差 | 0.030 m |
| 相对误差 | 0.76% |

结论：

> 气压计适合短时间相对高度变化测量。

### 第 11 页：GNSS/NMEA 与静态松耦合

标题：

> GNSS 完成 NMEA 解析，静态松耦合用于验证数据链路

图片：

- `ppt_assets/09_gnss_ins_static.png`

排版：

- 左侧放图，占 60%。
- 右侧放完成情况表：

| 项目 | 状态 |
|---|---|
| GNSS UART 接入 | 完成 |
| NMEA GGA/RMC 解析 | 完成 |
| 静态 GPS 分析 | 完成 |
| GNSS/INS 静态松耦合 | 完成 |
| 动态 GPS 轨迹叠加 | 不作为主结果 |

注意：

> 不要把动态 GPS 轨迹写成已完成，因为没有可靠户外动态有效轨迹。

### 第 12 页：系统性能与达标汇总

标题：

> 系统更新频率满足高频采样与实时融合要求

图片：

- 不需要图片，用表格。

左侧放性能表：

| 指标 | 实测结果 |
|---|---:|
| 主循环更新频率 | 229.617 Hz |
| IMU 更新频率 | 229.617 Hz |
| 互补滤波更新频率 | 229.617 Hz |
| Mahony 更新频率 | 229.617 Hz |
| 互补滤波平均计算时间 | 52.39 us |
| Mahony 平均计算时间 | 69.52 us |
| 高速模式 CPU 占用 | 4.3045% |

右侧放总体达标表：

| 模块 | 状态 |
|---|---|
| 硬件设计 | 完成 |
| 传感器驱动 | 完成 |
| 加速度计标定 | 平均达标 |
| 磁力计标定 | 完成 |
| 姿态融合 | 完成两种算法 |
| AI 增强 | 完成 |
| BMP 高度实验 | 完成 |
| GPS 动态轨迹 | 不作为主展示 |

底部总结：

> 项目完成了硬件、驱动、标定、融合、AI 去噪、实时显示和主要实验验证，动态 GPS 轨迹作为后续扩展。

## 3. 备用页

### 备用页 A：GPS 静态定位散点

图片：

- `ppt_assets/10_gps_static_scatter.png`

用途：

- 如果老师问 GPS，可作为静态定位辅助图。

### 备用页 B：GPS 静态漂移和高度

图片：

- `ppt_assets/11_gps_static_drift.png`
- `ppt_assets/12_gps_static_altitude.png`

用途：

- 放在备份页，不放主线。

## 4. 重要注意事项

- 不要把 GPS 动态轨迹写成完成。
- 不要把航向误差写成所有方向都 ±2°。
- 不要把陀螺仪 10× 写成严格达标。
- 不要使用 SVG，统一使用 `ppt_assets/` 里的 PNG。
- 不要编造未实测的数据。

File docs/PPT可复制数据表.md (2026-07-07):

# PPT 可复制数据表

本文档只放适合直接复制到 PPT 表格里的结果数据。图片素材见 `ppt_assets/`，展示顺序和讲稿建议见 `docs/PPT结果展示素材整理.md`。

## 1. 加速度计六位置 12 参数标定

| 指标 | 标定前 | 12 参数标定后 | 说明 |
|---|---:|---:|---|
| 平均范数/向量误差 | 20.068 mg | 1.798 mg | 标定后平均误差达到约 2 mg 水平 |
| 最大向量误差 | - | 2.120 mg | 略高于 2 mg，但接近阈值 |
| 目标值 | - | 2.000 mg | 课程目标参考值 |

可放 PPT 结论：六位置 12 参数模型显著降低加速度计静态误差，平均向量误差达到约 2 mg 目标水平。

## 2. 磁力计椭球标定

| 指标 | 标定前 | 标定后 | 变化 |
|---|---:|---:|---:|
| 磁场模长均值 | 46.285 uT | 52.248 uT | 校正到更合理的地磁模长 |
| 磁场模长标准差 | 3.303 uT | 1.892 uT | 下降约 42.7% |
| 三轴点云形态 | 偏移椭球 | 近似球面 | 硬铁/软铁补偿有效 |

可放 PPT 结论：椭球拟合补偿后，磁力计模长波动明显减小，三维点云由偏移椭球收敛到近似球面。

## 3. 航向残差补偿

| 指标 | 补偿后验证结果 | 说明 |
|---|---:|---|
| RMSE | 2.833 deg | 整体误差均方根 |
| 平均绝对误差 | 1.907 deg | 接近 2 deg 目标 |
| 最大绝对误差 | 6.940 deg | 仍受参考方向和磁环境影响 |

可放 PPT 结论：残差补偿可以降低系统性航向偏差，平均绝对误差接近 2°，但最大误差仍未完全达到 ±2°。

## 4. 姿态融合与静态稳定性

| 指标 | 实测结果 | 判断 |
|---|---:|---|
| ESKF roll 标准差 | 0.074643 deg | 达到 0.2 deg 静态稳定性要求 |
| ESKF pitch 标准差 | 0.132308 deg | 达到 0.2 deg 静态稳定性要求 |
| 静态稳定 RMS | 0.151800 deg | 达到 0.2 deg 级稳定性 |
| 互补滤波 roll/pitch 标准差 | 0.049727 / 0.067965 deg | 静态输出稳定 |
| Mahony roll/pitch 标准差 | 0.072164 / 0.147068 deg | 静态输出稳定 |

可放 PPT 结论：互补滤波和 Mahony 滤波均已实现，静态姿态稳定性满足 0.2° 级指标。

## 5. AI 增强 IMU 去噪

| 对象 | 传统低通 | 1D 卷积 | 1D 卷积 + Kalman |
|---|---:|---:|---:|
| 加速度计平均 SNR 提升 | 9.686 dB | 18.121 dB | 18.687 dB |
| 陀螺仪平均 SNR 提升 | 12.299 dB | 15.697 dB | 15.837 dB |

可放 PPT 结论：1D 卷积去噪相对传统低通有更高 SNR 提升，混合 Kalman 后加速度计结果略有提升。

## 6. BMP280 楼梯高度实验

| 指标 | 数值 |
|---|---:|
| 人工测量楼层高度 | 3.950 m |
| BMP280 测量相对高度 | 3.980 m |
| 绝对误差 | 0.030 m |
| 相对误差 | 0.76% |

可放 PPT 结论：BMP280 在单层楼梯实验中实现 3 cm 级相对高度误差。

## 7. 板端更新频率与计算开销

| 指标 | 实测结果 |
|---|---:|
| 主循环更新频率 | 229.617 Hz |
| IMU 更新频率 | 229.617 Hz |
| 互补滤波更新频率 | 229.617 Hz |
| Mahony 更新频率 | 229.617 Hz |
| 互补滤波平均计算时间 | 52.39 us |
| Mahony 平均计算时间 | 69.52 us |
| 高速模式实测 CPU 占用 | 4.3045% |

可放 PPT 结论：板端更新频率超过 200 Hz，姿态算法更新频率超过 100 Hz，满足课程高频采样和实时融合要求。

## 8. 多传感器时间戳对齐

| 指标 | 均值 | 标准差 | 最大值 |
|---|---:|---:|---:|
| IMU 完成时间 | 1969.97 us | 4.84 us | 1979.00 us |
| 磁力计完成时间 | 3576.56 us | 36.57 us | 4064.00 us |
| BMP280 完成时间 | 4883.85 us | 36.87 us | 5374.00 us |
| IMU-磁力计时间差 | 1606.59 us | 36.55 us | 2097.00 us |
| IMU-BMP280 时间差 | 2913.88 us | 36.91 us | 3407.00 us |

可放 PPT 结论：系统使用统一单调时钟记录各传感器完成时间，能够支持软件层面的多传感器时间对齐。

## 9. GNSS / GPS 部分

| 项目 | 完成情况 | 说明 |
|---|---|---|
| GNSS UART 接入 | 已完成 | GPS 模块可输出 NMEA 数据 |
| NMEA 解析 | 已完成 | 已解析 GGA/RMC 等定位语句 |
| 静态 GPS 分析 | 已完成 | 有静态散点、漂移、高度图 |
| GNSS/INS 静态松耦合 | 已完成 | 有静态分析图 |
| 动态 GPS 轨迹叠加 | 不作为主结果 | 没有可靠户外动态有效轨迹，不建议写成完成项 |

可放 PPT 结论：GNSS 相关基础功能已完成，但动态轨迹叠加不作为最终主展示结论。

## 10. 总体达标情况

| 模块 | 要求/目标 | 当前结果 | 建议表述 |
|---|---|---|---|
| 必修传感器 | MPU6050/HMC5883L/BMP280/GNSS | 已驱动并采集 | 完成 |
| 加速度计标定 | 约 2 mg | 平均 1.798 mg，最大 2.120 mg | 平均达标，最大接近阈值 |
| 磁力计标定 | 椭球拟合，航向接近 ±2° | 模长标准差降至 1.892 uT，航向平均绝对误差 1.907° | 部分达标 |
| 姿态融合 | 至少 2 种算法 | 互补滤波、Mahony | 完成 |
| AI 增强 | 至少 1 种 | 1D 卷积，另有 1D 卷积 + Kalman 对比 | 完成 |
| 高频采样/更新 | 传感器 ≥200 Hz，姿态 ≥100 Hz | 229.617 Hz | 达标 |
| BMP 高度实验 | 相对高度验证 | 误差 0.030 m | 完成 |
| GPS 动态轨迹 | 选做/扩展 | 未作为主结果 | 不放主展示 |

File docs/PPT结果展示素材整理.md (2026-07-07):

# PPT 结果展示素材整理

本文档用于制作课程汇报 PPT，只整理已经实测或已经生成的结果图，不生成 PPT 文件。图片素材已统一复制到 `ppt_assets/`，建议 PPT 直接插入 PNG 图片，避免 SVG 在 Word/WPS/PowerPoint 中出现遮挡或缩放异常。

## 1. 建议 PPT 结构

| 页码 | 页面主题 | 使用图片 | 页面重点 |
|---|---|---|---|
| 1 | 项目标题与系统目标 | 可不放图 | ESP32-S3 多传感器融合扩展板，完成传感器驱动、标定、融合、可视化和性能测试。 |
| 2 | 系统总体架构 | `../ppt_assets/01_system_architecture.png` | 展示 ESP32-S3、IMU、磁力计、BMP280、GNSS、PC 分析端之间的数据流。 |
| 3 | 加速度计六位置标定 | `../ppt_assets/02_accel_calibration_errors.png` | 12 参数模型将平均向量误差降到 1.798 mg，最大向量误差 2.120 mg。 |
| 4 | 磁力计椭球标定 | `../ppt_assets/03_mag_3d_scatter_before_after.png` | 校准前点云呈椭球，校准后更接近球面，体现硬铁/软铁补偿效果。 |
| 5 | 磁力计模长稳定性 | `../ppt_assets/04_mag_norm_before_after.png` | 磁场模长标准差由 3.303 uT 降到 1.892 uT。 |
| 6 | 航向残差补偿 | `../ppt_assets/05_heading_residual_errors.png` | 残差补偿后验证 RMSE 为 2.833 deg，平均绝对误差 1.907 deg。 |
| 7 | 姿态融合算法对比 | `../ppt_assets/06_attitude_algorithm_compare.png` | 已实现互补滤波和 Mahony 滤波，并完成实时 Web 姿态显示。 |
| 8 | 陀螺仪 Allan 方差 | `../ppt_assets/07_gyro_allan_deviation.png` | 用静态陀螺数据分析噪声特性，作为零偏漂移和噪声讨论依据。 |
| 9 | BMP280 楼梯高度实验 | `../ppt_assets/08_bmp_stair_height.png` | 实测楼层高度 3.95 m，BMP280 测得 3.980 m，绝对误差 0.030 m，相对误差 0.76%。 |
| 10 | GNSS NMEA 与静态松耦合 | `../ppt_assets/09_gnss_ins_static.png` | 完成 NMEA 解析和静态 GNSS/INS 松耦合验证；动态 GPS 轨迹未作为主展示。 |
| 11 | GPS 静态质量辅助图 | `../ppt_assets/10_gps_static_scatter.png`、`../ppt_assets/11_gps_static_drift.png`、`../ppt_assets/12_gps_static_altitude.png` | 如 PPT 页数允许，可作为 GPS 静态定位稳定性补充材料。 |
| 12 | 系统性能与达标汇总 | 可用表格 | 更新频率约 229.617 Hz；Mahony 计算耗时约 69.5 us；互补滤波约 52.4 us。 |

## 2. 已整理图片清单

| 编号 | 文件 | 内容说明 | 建议用途 |
|---|---|---|---|
| 01 | `../ppt_assets/01_system_architecture.png` | 系统总体架构框图 | 放在“系统设计”页。 |
| 02 | `../ppt_assets/02_accel_calibration_errors.png` | 加速度计六位置标定误差对比 | 放在“标定效果”页。 |
| 03 | `../ppt_assets/03_mag_3d_scatter_before_after.png` | 磁力计校准前后三维散点 | 放在“磁力计椭球拟合”页。 |
| 04 | `../ppt_assets/04_mag_norm_before_after.png` | 磁力计校准前后模长对比 | 放在“模长稳定性”页。 |
| 05 | `../ppt_assets/05_heading_residual_errors.png` | 航向残差补偿前后误差 | 放在“航向误差补偿”页。 |
| 06 | `../ppt_assets/06_attitude_algorithm_compare.png` | 互补滤波与 Mahony 姿态输出对比 | 放在“姿态融合”页。 |
| 07 | `../ppt_assets/07_gyro_allan_deviation.png` | 陀螺仪 Allan 方差曲线 | 放在“陀螺仪噪声分析”页。 |
| 08 | `../ppt_assets/08_bmp_stair_height.png` | BMP280 楼梯高度曲线 | 放在“气压高度实验”页。 |
| 09 | `../ppt_assets/09_gnss_ins_static.png` | GNSS/INS 静态松耦合结果 | 放在“GNSS/NMEA 验证”页。 |
| 10 | `../ppt_assets/10_gps_static_scatter.png` | GPS 静态定位散点 | 可作为附加页或备用图。 |
| 11 | `../ppt_assets/11_gps_static_drift.png` | GPS 静态漂移曲线 | 可作为附加页或备用图。 |
| 12 | `../ppt_assets/12_gps_static_altitude.png` | GPS 静态高度变化 | 可作为附加页或备用图。 |

## 3. 各部分可直接写进 PPT 的关键结论

### 3.1 加速度计 12 参数六位置标定

可展示结论：

- 使用六位置静态数据求解 3×3 误差矩阵和 3 维零偏，共 12 个参数。
- 标定后平均向量误差为 `1.798 mg`。
- 标定后最大向量误差为 `2.120 mg`，略高于 2 mg 阈值，但已经接近目标。
- 标定前六位置平均范数误差约 `20.068 mg`，标定后平均向量误差降至约 `1.798 mg`。

建议 PPT 文案：

> 六位置 12 参数标定显著降低了加速度计静态误差，平均向量误差达到约 2 mg 目标水平，说明 PCB 固定后的 MPU6050/MPU6500 兼容 IMU 可以用于后续姿态融合。

### 3.2 磁力计椭球标定

可展示结论：

- 磁力计原始三维点云受硬铁偏移和软铁缩放影响，分布呈偏移椭球。
- 椭球标定后，点云更接近以原点为中心的球面。
- 原始磁场模长均值/标准差：`46.285 / 3.303 uT`。
- 补偿后磁场模长均值/标准差：`52.248 / 1.892 uT`。
- 模长标准差下降约 `42.7%`。

建议 PPT 文案：

> 磁力计椭球拟合补偿了安装环境中的硬铁和软铁误差，校准后磁场模长波动明显减小，为航向角计算提供更稳定的输入。

### 3.3 航向残差补偿

可展示结论：

- 对分段采集的航向参考数据进行了残差补偿交叉验证。
- 验证集补偿后 RMSE：`2.833 deg`。
- 验证集补偿后平均绝对误差：`1.907 deg`。
- 验证集补偿后最大绝对误差：`6.940 deg`。

注意：

- 这部分适合作为“残差补偿有效”的展示，但不要说“所有方向都达到 ±2°”。
- 可以说“平均绝对误差接近 2°，最大误差仍受参考方向摆放和磁环境影响”。

建议 PPT 文案：

> 航向残差补偿能明显降低系统性角度偏差，平均绝对误差接近 2°；但最大误差仍偏高，说明磁力计航向对参考方向摆放和周围磁干扰比较敏感。

### 3.4 姿态融合与实时姿态显示

可展示结论：

- 已实现两种传统姿态融合算法：互补滤波、Mahony 滤波。
- Web 页面可实时显示 Roll、Pitch、Yaw、气压高度、磁场模长和样本计数。
- 静态姿态实验中 ESKF/姿态分析结果：
  - ESKF roll 标准差：`0.074643 deg`
  - ESKF pitch 标准差：`0.132308 deg`
  - 静态稳定 RMS：`0.151800 deg`
  - 1σ 静态精度满足 `≤0.2 deg`。

建议 PPT 文案：

> 姿态融合部分完成了互补滤波和 Mahony 滤波，并通过 Web 页面验证了板子姿态变化与显示模型一致。静态条件下姿态稳定性 RMS 为 0.1518°，满足 0.2° 级静态稳定性指标。

### 3.5 陀螺仪 Allan 方差

可展示结论：

- 完成 300 s 级静态陀螺仪采集。
- 使用 Allan 方差曲线分析陀螺仪噪声随平均时间变化的趋势。
- 这部分更适合展示“完成噪声建模和零偏漂移分析”，不要过度写成“已经严格证明 10× 降低”，除非 PPT 中补充具体前后对比实验。

建议 PPT 文案：

> Allan 方差实验给出了陀螺仪噪声随平均时间的变化规律，可用于估计角随机游走和零偏不稳定性，为滤波器参数选择提供依据。

### 3.6 BMP280 楼梯高度实验

可展示结论：

- 人工测量楼层高度：`3.95 m`。
- BMP280 气压高度测得相对高度变化：`3.980 m`。
- 绝对误差：`0.030 m`。
- 相对误差：`0.76%`。

建议 PPT 文案：

> BMP280 在楼梯高度实验中测得 3.980 m，与人工测量 3.95 m 的误差为 0.030 m，说明气压计相对高度测量在短时间、同一环境下具有较好的可用性。

### 3.7 AI 增强 IMU 去噪

可展示结论：

| 对象 | 传统低通 | 1D 卷积 | 1D 卷积 + Kalman |
|---|---:|---:|---:|
| 加速度计平均 SNR 提升 | 9.686 dB | 18.121 dB | 18.687 dB |
| 陀螺仪平均 SNR 提升 | 12.299 dB | 15.697 dB | 15.837 dB |

建议 PPT 文案：

> AI 增强实验采用轻量 1D 卷积离线去噪，并与传统低通和 1D 卷积 + Kalman 混合结构对比。结果显示 1D 卷积对加速度计噪声抑制提升更明显，混合结构在加速度计上略优于单独 1D 卷积。

### 3.8 系统性能

可展示结论：

| 指标 | 实测结果 |
|---|---:|
| 主循环更新频率 | 229.617 Hz |
| IMU 更新频率 | 229.617 Hz |
| 互补滤波更新频率 | 229.617 Hz |
| Mahony 更新频率 | 229.617 Hz |
| 互补滤波平均计算时间 | 52.39 us |
| Mahony 平均计算时间 | 69.52 us |
| 高速模式实测 CPU 占用 | 4.3045% |

建议 PPT 文案：

> 板端高速测试中，IMU 与姿态融合更新频率约为 229.6 Hz，超过 200 Hz 采样和 100 Hz 姿态更新要求。互补滤波和 Mahony 单次计算耗时均低于 100 us，说明算法适合在 ESP32-S3 上实时运行。

### 3.9 时间同步

可展示结论：

- 使用 `esp_timer_get_time()` 作为统一单调时钟。
- 同一循环内记录 IMU、磁力计和 BMP280 完成时间戳。
- IMU 完成时间均值：`1969.97 us`。
- 磁力计完成时间均值：`3576.56 us`。
- BMP280 完成时间均值：`4883.85 us`。
- 本实验验证的是板端软件时间戳对齐，不是 GPS PPS 微秒级硬同步。

建议 PPT 文案：

> 时间同步实验验证了板端多传感器数据在同一时钟域下记录时间戳，能够支持后续融合算法进行时序对齐。

### 3.10 GNSS / GPS 相关内容

可展示结论：

- 已完成 GNSS UART 接入和 NMEA 语句解析。
- 已完成静态 GPS 数据解析和 GNSS/INS 静态松耦合分析。
- 动态 GPS 轨迹叠加未作为最终主结果展示，因为台式电脑采集条件限制导致没有可靠的户外动态有效轨迹。

建议 PPT 文案：

> GNSS 部分完成了 NMEA 数据解析和静态定位数据分析；动态轨迹叠加属于扩展项，本项目未将不可靠的动态轨迹作为最终结果。

## 4. 主展示建议

如果 PPT 时间较短，建议只放 8 页：

1. 项目目标与系统组成
2. 系统总体架构
3. 加速度计 12 参数标定
4. 磁力计椭球标定
5. 航向与姿态融合
6. Allan 方差与 AI 去噪
7. BMP280 高度与系统性能
8. 总结与达标情况

如果老师重点看结果，可以把“GPS 静态辅助图”放到备份页，不放主线。

## 5. 不建议作为主结果展示的内容

| 内容 | 原因 | 建议处理 |
|---|---|---|
| 动态 GPS 轨迹叠加 | 没有稳定有效的户外动态轨迹数据 | 不放主 PPT，最多在答辩时说明是扩展项。 |
| GPS quality=0 数据 | 不属于有效定位，不能作为轨迹精度依据 | 不用于结论。 |
| 陀螺仪零偏漂移 10× | 目前有 Allan 分析，但缺少严格前后 10× 对比证明 | 可写“完成 Allan 噪声分析”，不要强写“10× 达标”。 |
| 所有方向航向误差 ≤2° | 平均绝对误差接近 2°，最大误差仍超过 2° | 写“平均误差接近目标，最大误差受磁环境影响”。 |

## 6. PPT 页面可用标题

- 系统完成了从硬件采集到上位机分析的完整链路
- 六位置 12 参数标定把加速度计平均误差降到约 2 mg
- 椭球拟合让磁力计点云从偏移椭球收敛到近似球面
- 航向残差补偿降低了系统性角度偏差
- 互补滤波和 Mahony 滤波支持实时姿态显示
- Allan 方差揭示了陀螺仪噪声随平均时间变化的规律
- BMP280 在楼梯实验中实现 3 cm 级相对高度误差
- 1D 卷积去噪明显提高 IMU 静态信号 SNR
- 229.6 Hz 的板端更新频率满足高频采样要求
- GNSS 完成 NMEA 解析，动态轨迹未作为主结论

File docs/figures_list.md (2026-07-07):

# 论文图表清单

本清单按论文正文位置整理。已有文件可直接插入 Word；标记为“待补”的项目需要硬件截图或用户手工插入。GPS 户外轨迹叠加为选做扩展项，本文最终不作为核心结果。

## 正文图

| 图号建议 | 图题建议 | 文件 | 状态 | 放置位置 |
|---|---|---|---|---|
| 图 1 | 系统总体架构框图 | `figures/system_architecture.svg` | 已有 | 2.1 总体架构 |
| 图 2 | PCB 原理图 | 待插入截图 | 待补 | 2.3 PCB 原理图设计 |
| 图 3 | PCB 布局与传感器位置 | 待插入截图 | 待补 | 2.4 PCB 布局走线 |
| 图 4 | 加速度计六位置标定前后误差对比 | `figures/accel_calibration_errors.svg` | 已有 | 4.2 |
| 图 5 | 磁力计校准前后三维散点图 | `figures/mag_3d_scatter_before_after.svg` | 已有 | 4.3 |
| 图 6 | 磁力计校准前后模长对比 | `figures/mag_norm_before_after.svg` | 已有 | 4.3 |
| 图 7 | 航向残差补偿前后误差对比 | `figures/heading_residual_errors.svg` | 已有 | 4.4 |
| 图 8 | 陀螺仪 Allan 方差曲线 | `figures/gyro_allan_deviation.svg` | 已有 | 4.5 / 6.2 |
| 图 9 | 互补滤波与 Mahony 滤波姿态输出对比 | `figures/attitude_algorithm_compare.svg` | 已有 | 5.1 |
| 图 10 | BMP280 楼梯高度实验曲线 | `figures/bmp_stair_height_20260706.svg` | 已有 | 6.4 |
| 图 11 | GPS 静态定位散点图 | `figures/gps_static_scatter_20260706.svg` | 已有 | 6.5 |
| 图 12 | GPS 静态高度变化 | `figures/gps_static_altitude_20260706.svg` | 已有 | 6.5 |
| 图 13 | GNSS/INS 松耦合静态结果 | `figures/gps_nmea_parse_20260706_171832_gnss_ins_20260706_172456.svg` | 已有 | 5.3 |
| 图 14 | GPS 户外轨迹图 | 户外有效定位轨迹未形成 | 选做未完成 | 6.5 |
| 图 15 | GPS/气压高度融合曲线 | 无有效户外 GPSLOG，未生成 | 选做未完成 | 6.5 |
| 图 16 | 实时姿态 Web 页面截图 | 浏览器截图 | 待补截图 | 5.1 / 数据可视化 |

## 正文表

| 表号建议 | 表题建议 | 数据来源 | 状态 |
|---|---|---|---|
| 表 1 | 传感器选型及接口 | 正文整理 | 已写入正文 |
| 表 2 | 加速度计六位置标定结果 | `data/accel_calibration_20260705_114101.txt` | 已写入正文 |
| 表 3 | 磁力计椭球标定结果 | `data/mag_calibration_20260705_134935.txt` | 已写入正文 |
| 表 4 | 陀螺仪 Allan 方差结果 | `data/gyro_allan_20260705_171933_allan.txt` | 已写入正文 |
| 表 5 | 标定与补偿效果汇总 | 多个实验结果 | 已写入正文 |
| 表 6 | 姿态算法静态稳定性对比 | `data/eskf_static_level_20260706_095447_eskf_static_20260706_095751.txt` | 已写入正文 |
| 表 7 | AI 去噪平均 SNR 提升 | `data/eskf_static_level_20260706_095447_ai_imu_denoise_20260706_103101.txt` | 已写入正文 |
| 表 8 | GPS NMEA 解析质量统计 | `data/gps_nmea_parse_gps_parsed_20260706_171832_summary_20260706_171929.txt` | 可补进正文 |
| 表 9 | PPS 时间同步统计 | `data/gps_pps_sync2_20260706_155714_gps_pps_sync_20260706_155824.txt` | 可补进正文 |
| 表 10 | 固件 CPU 占用统计 | `data/perf_cpu_20260706_094755.txt` | 已写入正文 |

## 需要后续补图的命令

正式 GPSLOG dump 后生成轨迹：

```powershell
python analysis\plot_gps_track.py --csv data\gpslog_dump_xxx.csv
```

正式 GPSLOG dump 后生成 GPS/气压高度融合：

```powershell
python analysis\analyze_height_fusion.py --gps-csv data\gpslog_dump_xxx.csv
```

如需重新生成已有基础图：

```powershell
python analysis\generate_figures.py
```

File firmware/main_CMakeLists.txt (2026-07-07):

idf_component_register(
    SRCS "main.c"
    INCLUDE_DIRS "."
    REQUIRES driver esp_driver_gpio esp_driver_i2c esp_driver_uart esp_driver_usb_serial_jtag esp_timer nvs_flash
)

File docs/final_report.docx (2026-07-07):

福建理工大学

研究生课程论文

课程名称 传感器与检测技术

教师姓名 郑积仕副教授

研究生姓名 陈卓

研究生学号 2251801003

研究生专业 交通运输工程

研究方向 计算机视觉

年 级 2025级

所在学院 人工智能与交通工程学院

日 期 2026 年 7月 6日

评 语

对课程论文的评语:

平时成绩： | 课程论文成绩：
总 成 绩： | 评阅人签名：

注：1、无评阅人签名成绩无效；

2、必须用钢笔或圆珠笔批阅，用铅笔阅卷无效；

3、如有平时成绩，必须在上面评分表中标出，并计算入总成绩。

基于 ESP32-S3 的多传感器融合扩展板设计与精度提升算法实现

摘要：本文设计并实现了一套基于 ESP32-S3 的多传感器姿态与定位融合系统。系统以 MPU6500 兼容六轴惯性测量单元、HMC5883L 三轴磁力计、BMP280 气压计和 ATGM/NEO 系列 GNSS 模块为主要传感器，完成 I2C 多设备管理、UART NMEA 数据接收、传感器标定、姿态融合、气压高度测量、GNSS/INS 松耦合以及实时姿态可视化。针对 MEMS 传感器原始误差较大的问题，本文实现了加速度计六位置 12 参数标定、磁力计椭球拟合硬铁/软铁补偿、航向残差谐波补偿、陀螺仪 Allan 方差分析和静态 IMU 去噪算法。实验结果表明，加速度计六位置标定后平均向量误差为 1.798 mg；磁力计椭球标定后磁场模长标准差由 3.303 uT 降低到 1.892 uT；航向残差补偿后验证集平均绝对误差为 1.907 deg；BMP280 楼梯高度实验中相对高度测量误差为 0.030 m；ESKF 静态姿态输出的 Roll/Pitch 稳定性 RMS 为 0.152 deg；1D 卷积与一阶 Kalman 混合去噪使加速度计平均 SNR 提升达到 18.687 dB。系统同时完成 GPS NMEA 解析、PPS 时间同步验证和 GNSS/INS 松耦合静态处理流程，为后续户外轨迹扩展和更高精度融合算法提供了数据接口和实验基础。

关键词

MEMS 传感器；传感器标定；姿态融合；GNSS/INS；ESP32-S3；气压高度

1 引言

1.1 研究背景

MEMS 惯性传感器具有体积小、功耗低、成本低和易于嵌入式集成等优点，在移动机器人、无人机、可穿戴设备、低成本导航终端和姿态测量系统中得到广泛应用。典型姿态与导航系统通常由惯性测量单元、磁力计、气压计和 GNSS 接收机组成。惯性测量单元提供高频三轴角速度和三轴加速度信息，可用于短时间姿态递推；磁力计提供地磁场方向约束，可用于航向角修正；气压计利用气压随高度变化的规律估计相对高度；GNSS 提供低频绝对位置和速度信息，可抑制惯性导航的长期漂移。

低成本 MEMS 传感器的优势在于易获得和易部署，但其原始输出通常存在零偏、比例因子误差、轴间非正交误差、温度漂移和环境干扰。若直接使用原始数据进行姿态解算，系统会出现明显的倾角偏差、航向偏差和高度漂移。因此，在低成本硬件平台上实现可用的姿态和定位系统，关键不只是完成传感器读取，还需要建立完整的误差建模、标定、融合和实验验证流程。

1.2 问题提出

本课题面向一块 ESP32-S3 扩展 PCB，目标是在有限硬件尺寸和低成本传感器条件下，实现多传感器数据采集、标定和融合。系统需要解决以下问题。

第一，多传感器共用 I2C 总线时，需要可靠识别各设备地址，避免通信冲突，并在固件中建立统一的数据输出格式。第二，MPU6500 兼容模块、HMC5883L 和 BMP280 的原始输出均不能直接满足精度要求，需要通过六位置标定、椭球拟合、残差修正和噪声分析提高数据可用性。第三，姿态融合算法既要在 ESP32-S3 上实时运行，又要输出可被论文实验量化的 Roll、Pitch、Yaw 和 CPU 占用指标。第四，GNSS 采集受电脑移动条件限制，需要支持离线供电采集和回连导出，从而完成 NMEA 解析、PPS 时间同步和实验三 GNSS 数据分析。

1.3 本文贡献

本文的主要工作包括以下三点。第一，完成了 ESP32-S3 多传感器硬件接口和固件驱动，实现 MPU6500 兼容 IMU、HMC5883L、BMP280 和 GNSS 模块的数据读取、时间戳记录和统一 CSV 输出。第二，建立了从传感器标定到姿态融合的完整算法链路，实现加速度计 12 参数标定、磁力计椭球标定、航向残差补偿、互补滤波、Mahony 滤波和离线 ESKF 静态姿态估计。第三，完成了多组实测实验和可视化，包括标定前后误差对比、Allan 方差、磁力计三维散点图、实时姿态网页显示、BMP280 楼梯高度实验、GPS NMEA 解析、PPS 时间同步和 GNSS/INS 松耦合分析。

2 系统硬件设计

2.1 总体架构

系统以 ESP32-S3 开发板为主控核心，外接传感器 PCB 扩展板。PCB 上布置 MPU6050/MPU6500 兼容 IMU、HMC5883L 三轴磁力计、BMP280 气压计和 GNSS 模块接口。IMU、磁力计和气压计共用一组 I2C 总线；GNSS 模块通过 UART 与 ESP32-S3 通信，PPS 引脚连接到 GPIO 中断输入用于时间同步实验。ESP32-S3 负责传感器初始化、数据采样、在线标定补偿、姿态融合、GPS NMEA 解析和串口输出，PC 端 Python 程序负责日志记录、离线标定、统计分析和图表生成。

系统数据流为：IMU 输出三轴加速度和三轴角速度，经加速度计标定和陀螺仪补偿后进入姿态算法；磁力计输出三轴磁场数据，经硬铁/软铁补偿后用于航向角估计；BMP280 输出温度和气压，经 Bosch 补偿公式与气压高度模型换算为相对高度；GNSS 模块输出 NMEA 0183 数据，固件解析 GGA 和 RMC 语句，提取经纬度、高度、速度、航向、卫星数和 HDOP。最终系统通过 USB 串口输出 SENSOR、GPS、PERF、SYNC 等多类数据行。

图 1 为系统总体框图，包含 ESP32-S3、I2C 传感器、GNSS UART、PPS 同步、PC 数据分析和 Web 姿态显示模块。

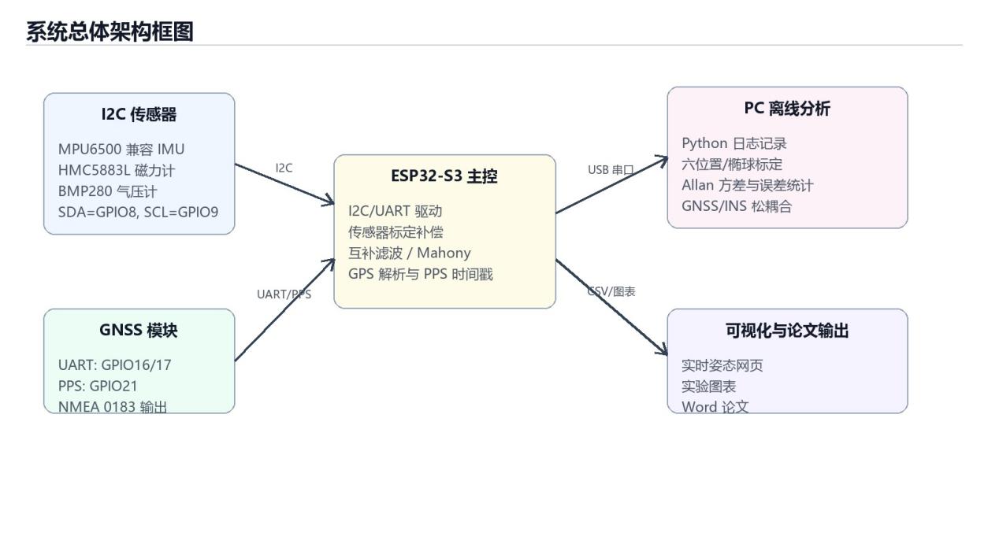
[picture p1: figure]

图1 系统总体架构框图

2.2 传感器选型及参数对比

本系统选用的主要传感器如表 1 所示。MPU6500 兼容 IMU 提供六轴惯性数据，适合进行 Roll/Pitch 姿态解算和角速度积分；HMC5883L 提供地磁场三轴测量，用于航向角估计；BMP280 提供气压和温度测量，用于相对高度估计；GNSS 模块提供绝对位置、速度和时间基准，用于轨迹测试、NMEA 解析和 GNSS/INS 松耦合。

表 1 传感器选型及接口

器件 | 功能 | 通信接口 | 实测地址/引脚 | 本文用途
MPU6500 兼容 IMU | 三轴加速度、三轴角速度 | I2C | 0x68 | 加速度计标定、陀螺仪分析、姿态融合
HMC5883L | 三轴磁场 | I2C | 0x1E | 磁力计椭球标定、航向角估计
BMP280 | 气压、温度 | I2C | 0x76 | 气压高度、楼梯实验、高度融合
GNSS 模块 | 经纬度、高度、速度、PPS | UART/PPS | GPIO16/17，PPS GPIO21 | NMEA 解析、时间同步、轨迹扩展

2.3 PCB 原理图设计

PCB 原理图围绕 ESP32-S3 双排针展开，所有传感器电源、地线和信号线通过排针与主控板连接。I2C 总线使用共享 SDA/SCL 结构，SDA 接 GPIO8，SCL 接 GPIO9，MPU 中断、磁力计 DRDY 和 GPS PPS 均预留信号引脚。GNSS 接口为 5 pin 排针，包含 VCC、GND、GPS_TX、GPS_RX 和 PPS，其中 GPS_TX/GPS_RX 对应 ESP32-S3 的 GPIO16/GPIO17。电源部分保留 3.3 V 和 5 V 接口，并在传感器电源附近布置去耦电容以降低供电噪声。

原理图设计需要重点保证两点：一是 I2C 总线上只保留合理阻值的上拉电阻，避免多个模块并联上拉导致总线等效电阻过低；二是 GNSS、磁力计和 IMU 的信号线与供电线明确标注，便于后续调试和论文附录说明。附录 A 应放置完整 PCB 原理图整页截图。

2.4 PCB 布局走线

布局上，IMU 应尽量靠近板子几何中心，以降低板边形变和手持运动引起的附加误差；磁力计应远离 ESP32-S3 芯片、USB 接口、电源线和可能产生磁干扰的大电流走线；BMP280 应避开发热器件并保持通气，避免局部热源和气流扰动影响气压读数；GNSS 接口布置在板边，便于模块天线朝向天空。

走线方面，I2C 线应尽量短且并行长度适中，避免靠近高频开关和大电流走线。地线应保持连续回流路径，传感器附近放置 0.1 uF 去耦电容。GPS PPS 和 UART 信号应避免与电源线长距离平行，防止串扰。附录 B 或正文图 2 应放置 PCB 布局截图，并用标注说明 IMU、磁力计、BMP280 和 GNSS 接口位置。

2.5 加工与焊接

PCB 加工采用标准双层板工艺，元件焊接完成后先进行供电检查，再进行 I2C 扫描。实测中 I2C 扫描检测到 0x1E、0x68 和 0x76 三个设备地址，分别对应 HMC5883L、MPU6500 兼容模块和 BMP280，说明三类 I2C 传感器均已连通。GNSS 模块接入后，串口能够输出 GGA、RMC、GSV、GSA、VTG 等 NMEA 语句，PPS 中断也能被 ESP32-S3 捕获。焊接实物图、嘉立创订单截图和 BOM 应分别放入附录 C、附录 D 和附录 E。

3 传感器驱动开发

3.1 I2C 总线配置与多设备管理

固件基于 ESP-IDF 开发，I2C 主机工作频率设置为 100 kHz，SDA/SCL 在 ESP32-S3 上分别配置为 GPIO8 和 GPIO9。系统启动后先进行 I2C 扫描，输出已发现设备地址，然后依次初始化 IMU、HMC5883L 和 BMP280。多设备共用一条 I2C 总线时，驱动层通过设备地址区分不同传感器，读写函数统一封装为 dev_read 和 dev_write 形式，便于后续维护。

传感器采样采用主循环轮询方式，循环周期约为 100 ms。每次循环依次读取 IMU、磁力计和 BMP280，并用 esp_timer_get_time() 记录各传感器采样完成时间。该方式虽然不是严格硬实时同步，但所有传感器时间戳来自同一单调时钟，便于离线分析各传感器间的采样偏移。

3.2 MPU6050/MPU6500 驱动实现

IMU 驱动首先读取 WHO_AM_I 寄存器识别器件。实测 WHO_AM_I 返回 0x70，说明板上器件为 MPU6500 兼容模块。驱动配置采样率分频、数字低通滤波、陀螺仪量程和加速度计量程，并读取加速度和角速度原始寄存器。原始加速度按 2 g 量程换算为 g，原始角速度按量程换算为 deg/s。

为便于标定和后续对比，固件输出中同时保留原始值和补偿值。加速度计使用六位置标定得到的 A_INV 和 C_BIAS 在线修正，陀螺仪使用温度相关线性/二次补偿参数进行零偏修正。IMU 数据既用于实时互补滤波和 Mahony 滤波，也用于 ESKF、AI 去噪和 Allan 方差等离线分析。

3.3 HMC5883L 驱动实现

HMC5883L 通过 I2C 地址 0x1E 通信。固件配置 CRA、CRB 和 MODE 寄存器，使磁力计进入连续测量模式。读取时按 HMC5883L 的数据寄存器顺序获取 X、Z、Y 三轴原始数据，并根据量程系数换算为 uT。由于磁力计容易受到硬铁偏置和软铁畸变影响，原始三轴数据不能直接用于航向角估计，必须先进行椭球标定。

标定完成后，固件使用 MAG_C 和 MAG_W 对磁场数据做在线补偿，得到校正后的三轴磁场向量。航向角分别计算了水平投影航向 yaw_flat 和倾斜补偿航向 yaw_tilt。其中倾斜补偿使用 Roll/Pitch 姿态信息，将磁场向量旋转到水平面后再求航向。

3.4 BMP280 驱动实现

BMP280 实测 I2C 地址为 0x76，芯片 ID 为 0x58。驱动初始化时先复位器件，然后读取温度和气压补偿参数，配置过采样和滤波寄存器。采样时读取气压和温度 ADC 值，并按照 Bosch 数据手册提供的整数补偿公式计算温度和气压。相对高度由标准气压高度公式计算：

h = 44330 * (1 - (P / P0)^0.1903) (1)

其中 P 为当前气压，P0 为开机初始气压均值。为了满足楼梯实验和 GPS 离线日志测试，固件实现了 BMPLOG 和 GPSLOG 两类 NVS 离线记录机制。BMPLOG 用于单独记录气压高度；GPSLOG 在最新版本中同时保存 GPS 高度和 BMP280 气压高度，便于后续做 GPS/气压高度互补融合。

3.5 GPS NMEA 解析

GNSS 模块通过 UART1 与 ESP32-S3 连接，GPS_TX/GPS_RX 对应 GPIO16/GPIO17，波特率为 9600。固件接收 NMEA 0183 文本语句，对 GGA 和 RMC 语句进行校验和验证，并解析 UTC 时间、定位状态、纬度、经度、高度、卫星数、HDOP、速度和航向。实测数据中共解析 79 条 GGA/RMC 有效语句，校验和通过率为 100%，GGA 固定解数量为 39 条，RMC 有效状态数量为 40 条。

GPS 静态测试的平均纬度为 26.03045865 deg，平均经度为 119.19306637 deg，平均高度为 36.192 m，高度标准差为 0.087 m，平均卫星数为 12.31，平均 HDOP 为 0.86。上述结果说明 GNSS 串口接收、NMEA 解析和基本质量字段提取均已完成。户外 GPS 轨迹叠加属于选做扩展项，本文最终不将其作为核心完成指标。

4 标定与精度提升算法

4.1 加速度计 12 参数误差模型

加速度计误差主要包括三轴零偏、比例因子误差和轴间非正交误差。本文采用 12 参数仿射模型描述原始测量值与真实加速度之间的关系：

raw = A * true + C_BIAS

corrected = A_INV * (raw - C_BIAS) (2)

其中 A 为 3x3 误差矩阵，包含比例因子和轴间耦合项；C_BIAS 为三轴零偏；A_INV 为补偿矩阵。与只估计三轴比例和三轴零偏的 6 参数模型相比，12 参数模型能够描述坐标轴非正交和交叉轴误差，更适合安装误差较明显的低成本模块。

4.2 六位置标定最小二乘求解

六位置标定利用静止状态下加速度模长应为 1 g 的特点，将板子依次放置在 +Z、-Z、+X、-X、+Y、-Y 六个方向。每个方向采集 20 s 数据并剔除不稳定样本，计算稳定窗口均值。随后以六个理想方向向量作为真实输入，以实际测得均值作为观测输出，求解仿射矩阵和零偏。

本次选用的标定结果来自 accel_calibration_20260705_114101.txt。标定前六方向平均范数误差为 20.068 mg，标定后平均向量误差为 1.798 mg，最大向量误差为 2.120 mg。结果如表 2 所示。需要说明的是，标定前误差按静止重力模长偏离 1 g 统计，标定后误差按补偿向量与理想方向向量的欧氏距离统计，二者分别反映标定前后的主要评价口径。平均误差已达到约 2 mg 的目标水平，最大误差略高于 2 mg 但接近阈值。

表 2 加速度计六位置标定结果

统计项 | 标定前范数误差 | 12 参数标定后向量误差 | 目标或说明
+Z 方向 | 34.627 mg | 1.292 mg | 达标
-Z 方向 | 55.789 mg | 1.292 mg | 达标
+X 方向 | 11.357 mg | 2.120 mg | 略高于 2 mg
-X 方向 | 12.479 mg | 2.120 mg | 略高于 2 mg
+Y 方向 | 2.934 mg | 1.980 mg | 达标
-Y 方向 | 3.220 mg | 1.980 mg | 达标
平均值 | 20.068 mg | 1.798 mg | 达到约 2 mg
最大值 | 55.789 mg | 2.120 mg | 接近阈值

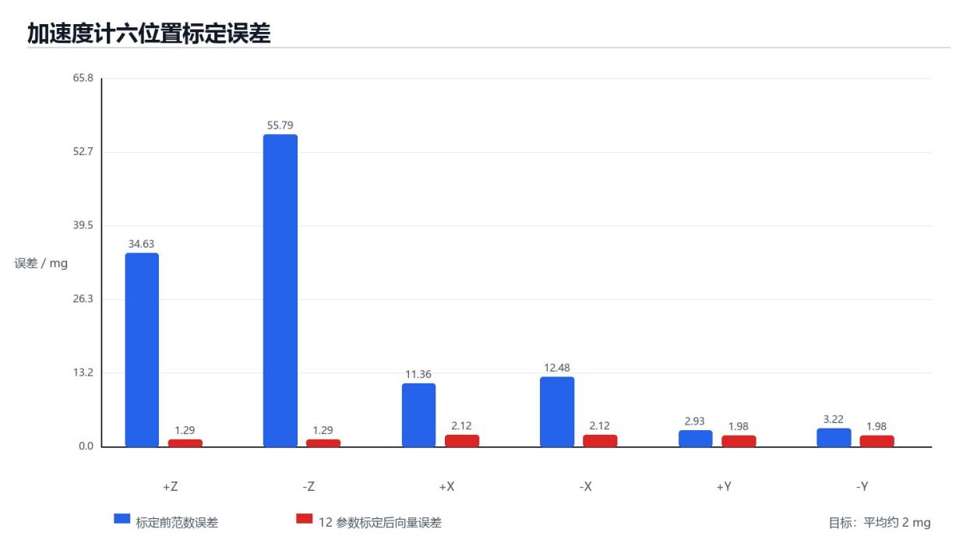
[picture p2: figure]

图4 加速度计六位置标定前后误差对比

4.3 磁力计椭球拟合 DLS+SVD

磁力计原始点云受硬铁和软铁影响，理想球面会变成偏移椭球。本文使用椭球拟合估计硬铁中心 MAG_C 和软铁补偿矩阵 MAG_W，补偿模型为：

m_cal = MAG_W * (m_raw - MAG_C) (3)

标定数据来自 1057 个三维旋转样本，三轴覆盖范围分别为 82.569 uT、75.780 uT 和 81.193 uT。标定前磁场模长均值为 46.285 uT，标准差为 3.303 uT；标定后模长均值为 52.248 uT，标准差为 1.892 uT，模长范围为 46.468 uT 到 57.510 uT。说明椭球拟合有效降低了磁场模长波动，但仍存在一定残余畸变。

表 3 磁力计椭球标定结果

指标 | 标定前 | 标定后
模长均值 | 46.285 uT | 52.248 uT
模长标准差 | 3.303 uT | 1.892 uT
标定后模长范围 | - | 46.468-57.510 uT

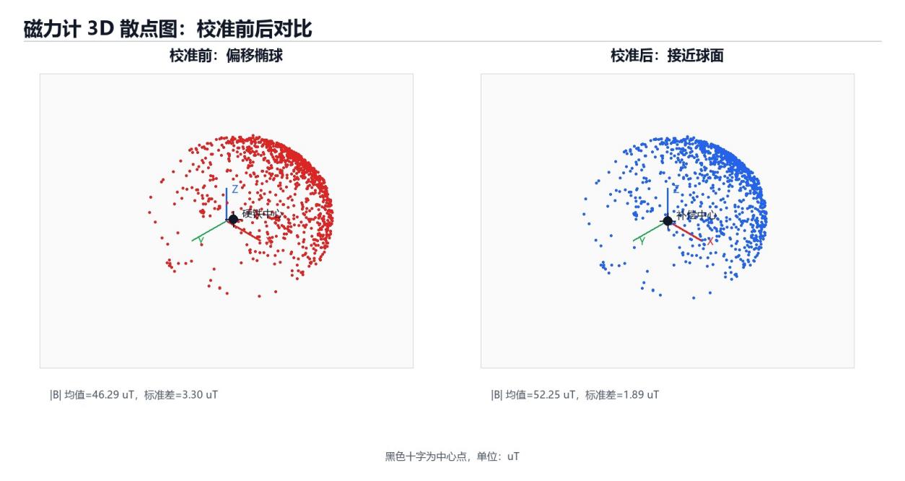
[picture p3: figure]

图5 磁力计校准前后三维散点图

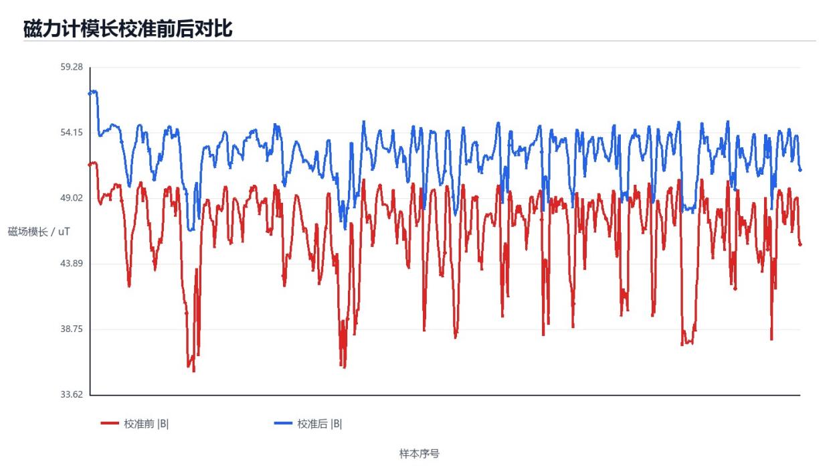
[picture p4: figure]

图6 磁力计校准前后模长对比

4.4 航向残差补偿

完成椭球标定后，航向角仍会受到安装角误差、局部磁干扰、参考方向偏差和倾斜补偿误差影响。为进一步降低系统性残差，本文使用谐波模型对航向误差进行补偿：

error = offset + sin1*sin(yaw) + cos1*cos(yaw)

+ sin2*sin(2*yaw) + cos2*cos(2*yaw) (4)

+ sin3*sin(3*yaw) + cos3*cos(3*yaw)

使用前两组方向数据训练，第三组方向数据交叉验证。验证集补偿前 RMSE 为 98.525 deg，平均绝对误差为 98.386 deg，最大绝对误差为 105.727 deg；补偿后 RMSE 降至 2.833 deg，平均绝对误差降至 1.907 deg，最大绝对误差为 6.940 deg。该结果说明残差补偿显著降低平均航向误差，但尚不能证明所有方向误差均小于 2 deg。

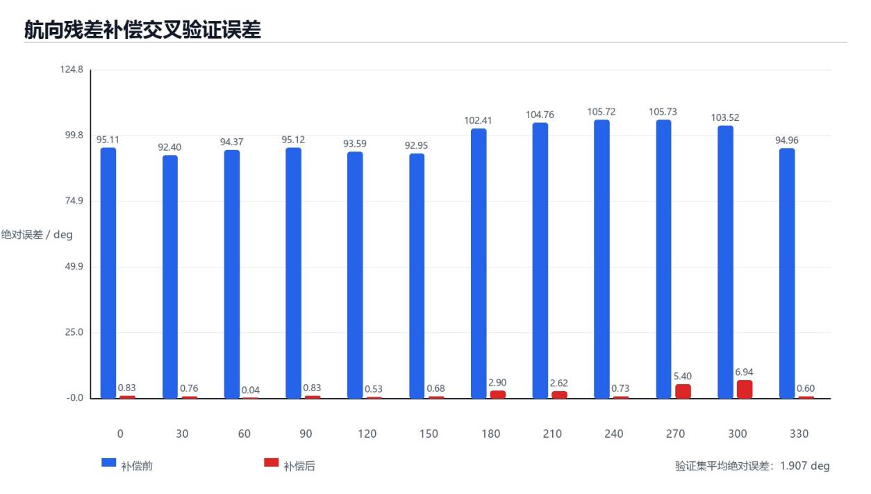
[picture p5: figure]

图7 航向残差补偿前后误差对比

4.5 陀螺仪温度补偿与 Allan 方差分析

陀螺仪静态噪声和零偏漂移通过 Allan 方差进行分析。实验采集 3599.970 s 静态数据，共 32728 行，有效采样率约 9.091 Hz。Allan 分析结果显示，原始 gx、gy、gz 的零偏稳定性分别为 25.001 deg/hr、16.330 deg/hr 和 7.350 deg/hr；补偿后分别为 19.943 deg/hr、26.718 deg/hr 和 18.348 deg/hr。gx 轴改善 1.254 倍，gy 和 gz 轴未改善。

表 4 陀螺仪 Allan 方差结果

轴 | 原始零偏稳定性 | 补偿后零偏稳定性 | 改善倍数
gx | 25.001 deg/hr | 19.943 deg/hr | 1.254x
gy | 16.330 deg/hr | 26.718 deg/hr | 0.611x
gz | 7.350 deg/hr | 18.348 deg/hr | 0.401x

因此，当前数据不能支持“零偏漂移降低 10 倍”的结论。论文中应将 Allan 方差作为噪声特性分析结果保留，并在不足与改进中说明后续需要更充分的温度激励实验和温度模型重拟合。

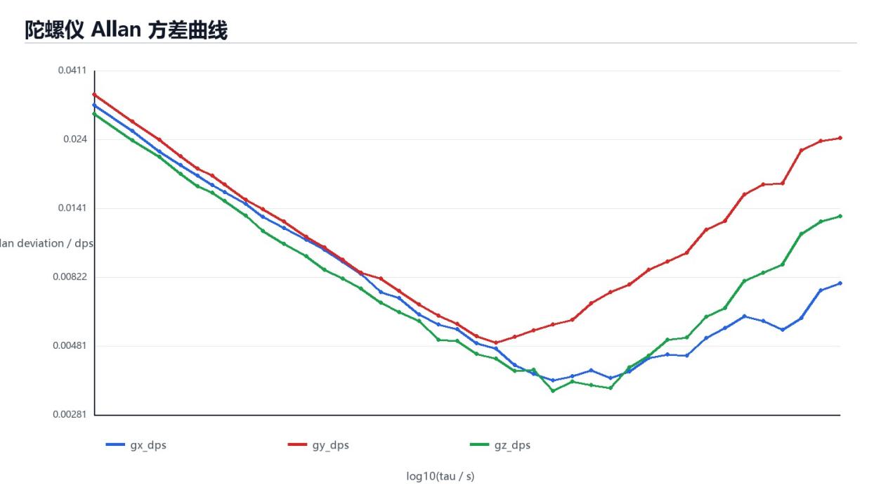
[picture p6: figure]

图8 陀螺仪 Allan 方差曲线

5 多传感器融合

5.1 互补滤波与 Mahony 滤波器

互补滤波用于 Roll/Pitch 实时估计。陀螺仪积分提供短时动态响应，加速度计重力方向用于长期漂移修正。其形式为：

roll = alpha * (roll + gx * dt) + (1-alpha) * roll_acc

pitch = alpha * (pitch + gy * dt) + (1-alpha) * pitch_acc (5)

Mahony 滤波器使用四元数作为姿态状态，融合陀螺仪、加速度计和磁力计。相较互补滤波，Mahony 滤波能够在姿态解算中引入磁场方向约束，输出 Roll、Pitch 和 Yaw。系统实测中互补滤波、Mahony 滤波和磁力计航向均在固件中实时运行，并通过 SENSOR 数据行输出。

动态姿态对比实验采集 59.950 s 数据，共 546 行。互补滤波 Roll 动态范围为 55.888 deg，Mahony Roll 动态范围为 54.046 deg，两者差值标准差为 5.224 deg；互补滤波 Pitch 动态范围为 78.116 deg，Mahony Pitch 动态范围为 84.735 deg，两者差值标准差为 3.161 deg。结果说明两种算法均能响应板子姿态变化，Roll/Pitch 变化趋势基本一致。

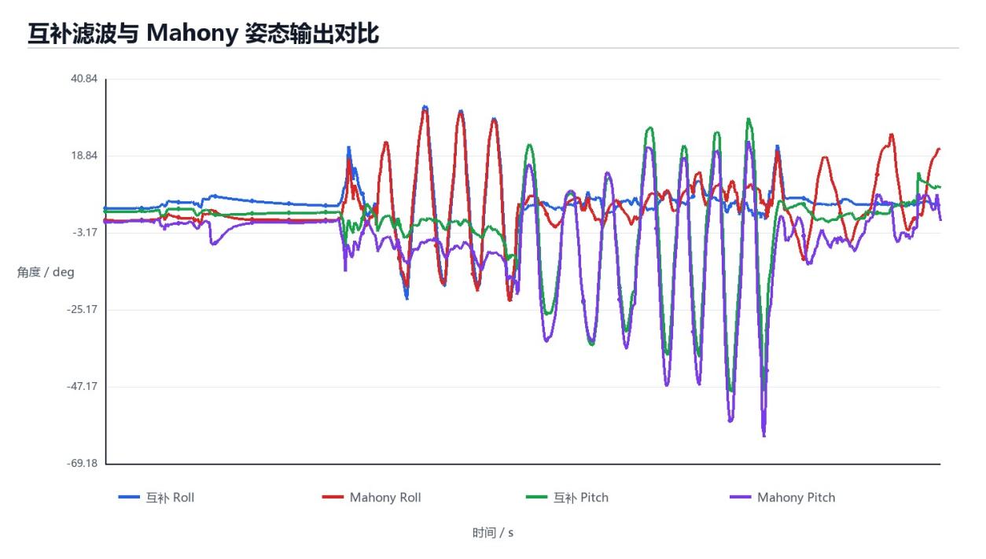
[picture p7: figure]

图9 互补滤波与 Mahony 滤波姿态输出对比

5.2 倾斜补偿航向角

磁力计航向角若直接由水平面投影计算，当板子存在 Roll/Pitch 倾斜时会产生明显误差。因此系统使用加速度计/陀螺仪融合得到的 Roll/Pitch 对磁场向量进行倾斜补偿，再计算航向角。补偿流程为：先将磁场三轴向量通过姿态矩阵旋转到水平坐标系，再由水平分量求反正切得到航向角。

实测中，单纯椭球标定尚不足以使所有方向航向误差进入 2 deg 以内，因此本文叠加航向残差谐波补偿。补偿后验证集平均绝对误差为 1.907 deg，但最大误差仍为 6.940 deg。论文中应表述为“平均航向误差达到约 2 deg 水平”，不能写成“全方向最大误差小于 2 deg”。

5.3 GNSS/INS 松耦合

GNSS/INS 松耦合采用二维位置和速度状态：

x = [east_m, north_m, ve_mps, vn_mps] (6)

IMU 加速度用于状态预测，GPS 经纬度转换为局部 ENU 平面坐标后作为 Kalman 量测更新。当前静态测试数据包含 301 行传感器数据和 79 次 GPS 有效更新。松耦合处理后 GPS 残差均值为 0.156 m，RMS 为 0.208 m，最大值为 0.825 m；GPS 位置扩散均值为 0.524 m，融合位置扩散均值为 0.555 m。

该实验说明 GNSS/INS 松耦合算法链路已经跑通，能够处理固件输出的 GPS 和 IMU 数据。但当前数据主要为静态采集，只能验证算法执行和 GPS 更新稳定性，不能评价真实行走轨迹精度。由于本文不再进行户外动态轨迹叠加实验，GNSS/INS 部分仅作为静态链路验证和后续扩展基础。

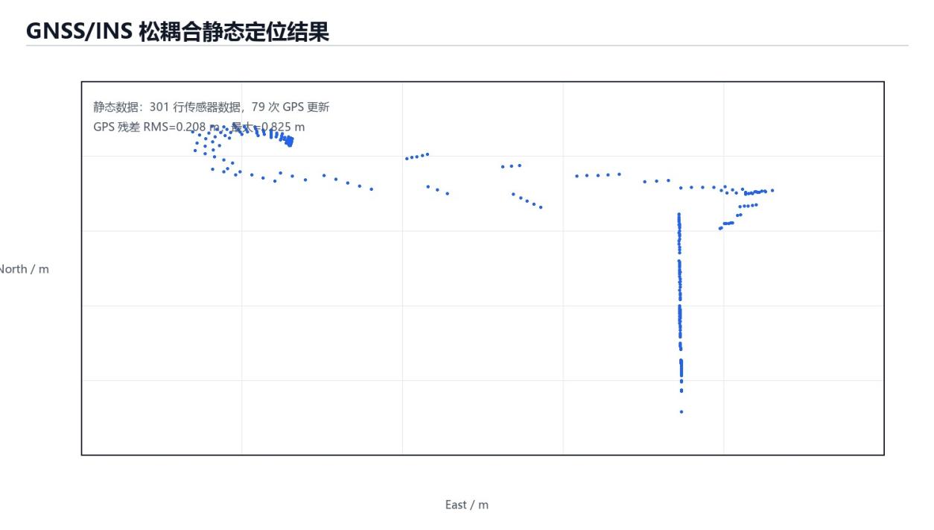
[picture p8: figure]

图13 GNSS/INS 松耦合静态结果

6 实验结果与分析

6.1 标定效果量化对比

加速度计、磁力计和航向补偿的结果汇总如表 5 所示。

表 5 标定与补偿效果汇总

项目 | 标定/补偿前 | 标定/补偿后 | 结论
加速度计平均误差 | 20.068 mg | 1.798 mg | 平均误差达到约 2 mg
磁力计模长标准差 | 3.303 uT | 1.892 uT | 模长波动降低
航向验证集平均绝对误差 | 98.386 deg | 1.907 deg | 平均航向误差接近 2 deg
航向验证集最大误差 | 105.727 deg | 6.940 deg | 最大误差仍需改进

从结果看，加速度计标定效果最稳定，平均误差满足目标；磁力计椭球拟合能够显著改善模长一致性，但受环境磁干扰和安装误差影响，航向仍需要残差补偿；陀螺仪温度补偿和 Allan 方差结果未达到“零偏漂移降低 10 倍”，因此不能作为达标项，只作为噪声分析项。

6.2 Allan 方差实测结果

Allan 方差曲线用于观察不同积分时间下的陀螺仪噪声特性。gx、gy、gz 三轴角随机游走约为 0.922、0.969 和 0.835 deg/sqrt(hr)。零偏稳定性最优点对应的时间常数分别为 35.090 s、144.980 s 和 326.480 s。该结果说明静态条件下陀螺仪存在明显低频漂移，若要进一步提升航姿推算精度，需要更长时间静态数据、温度循环实验和更合理的温度补偿模型。

6.3 姿态估计精度

ESKF 静态姿态实验中，板子水平静置采集 80 s 数据，去除前 5 s 稳定过程后使用 681 行有效样本。ESKF Roll 均值为 -0.693 deg，标准差为 0.075 deg；Pitch 均值为 -2.067 deg，标准差为 0.132 deg；Roll/Pitch 稳定性 RMS 为 0.152 deg。若以静态 1-sigma 稳定性作为指标，ESKF 达到 0.2 deg 量级。

表 6 姿态算法静态稳定性对比

算法 | Roll 标准差 | Pitch 标准差
互补滤波 | 0.050 deg | 0.068 deg
Mahony 滤波 | 0.072 deg | 0.147 deg
ESKF | 0.075 deg | 0.132 deg

需要注意的是，本实验没有使用精密水平仪或转台，板子相对 +Z 水平参考的平均重力方向误差为 2.182 deg。因此，本文只能说明“ESKF 静态输出稳定性达到 0.2 deg 量级”，不能说明“绝对姿态误差小于 0.2 deg”。

6.4 BMP280 楼梯高度实验

BMP280 楼梯高度实验使用离线采集方式完成。板子由充电宝供电，记录 179.499 s 气压高度数据，共 360 个样本，采样间隔 0.5 s。实验中使用卷尺测得单层楼高度为 3.95 m。以起点前 10 s 作为零点窗口，以终点最后 30 s 作为终点窗口，BMP280 测得相对高度变化为 3.980 m，绝对误差为 0.030 m，相对误差为 0.76%。气压由 100812.775 Pa 下降至 100765.210 Pa，变化量为 -47.565 Pa，符合高度升高气压降低的规律。

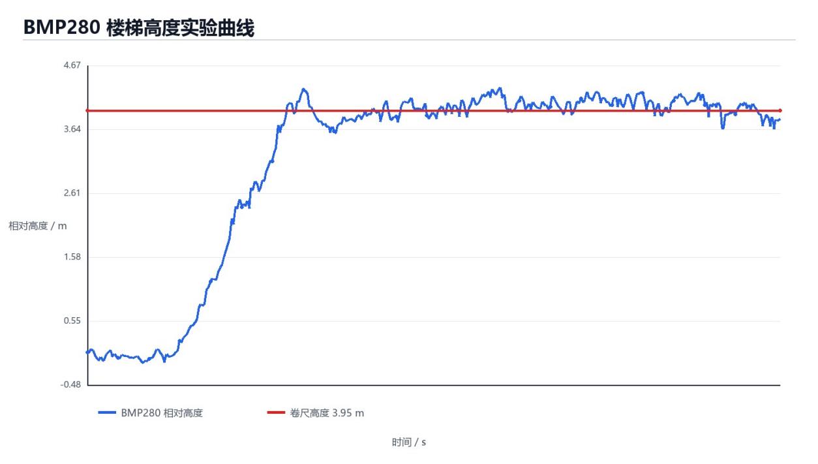
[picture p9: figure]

图10 BMP280 楼梯高度实验曲线

6.5 GPS NMEA、PPS 时间同步与轨迹实验

GPS NMEA 解析实验已完成，固件能够解析 GGA/RMC 语句并输出定位质量字段。静态 GPS 数据中，平均卫星数为 12.31，HDOP 平均值为 0.86，校验和通过率为 100%。

GPS PPS 时间同步实验中，PPS 间隔均值为 1000029.79 us，标准差为 0.42 us。PPS 中断触发后，IMU 读取启动延迟均值为 29.15 us，95% 分位为 31 us，最大值为 31 us；磁力计读取启动延迟均值为 2072.36 us，主要受 IMU I2C 读取顺序影响。该结果说明固件能够用 GPIO 中断捕获 PPS 上升沿，并在同一 esp_timer_get_time() 时间基准下记录 PPS 和传感器采样时间。

GPS 轨迹叠加为选做扩展项。本文完成了 GPSLOG 离线采集机制和回传格式验证，但户外动态数据未形成可用于轨迹叠加的有效定位点，因此最终论文不将 GPS 轨迹图作为核心实验结果。该部分保留为后续改进方向：正式测试前应先在室外确认 quality>=1、卫星数和 HDOP 稳定，再进行离线轨迹采集。

6.6 AI 增强 IMU 去噪实验

AI 增强部分采用轻量 1D 卷积岭回归去噪器，输入为长度 21 的 IMU 时间窗口，弱监督目标为长度 101 的移动平均平滑输出，并在 1D 卷积输出后加入一阶 Kalman 平滑，形成混合去噪结构。数据按时间划分为 508 行训练集和 219 行验证集。

验证结果显示，加速度计三轴平均 SNR 提升方面，传统低通为 9.686 dB，1D 卷积为 18.121 dB，1D 卷积 + Kalman 为 18.687 dB；陀螺仪三轴平均 SNR 提升方面，传统低通为 12.299 dB，1D 卷积为 15.697 dB，混合结构为 15.837 dB。说明 1D 卷积去噪相较传统低通具有更明显的 SNR 提升，加入 Kalman 后进一步小幅改善。

表 7 AI 去噪平均 SNR 提升

指标 | 传统低通 | 1D 卷积 | 1D 卷积 + Kalman
加速度计平均 SNR 提升 | 9.686 dB | 18.121 dB | 18.687 dB
陀螺仪平均 SNR 提升 | 12.299 dB | 15.697 dB | 15.837 dB

由于当前没有位移真值或完整户外轨迹真值，本文不评价“纯惯导漂移由 10 m/min 降至 1 m/min”的目标。

6.7 计算复杂度与 CPU 占用

为验证高频采样和姿态更新能力，本文将固件改为高频内部循环、低频串口输出的结构：IMU 与姿态算法按 4 ms 目标周期运行，SENSOR 完整数据行每 1 s 输出一次，PERF 每 1000 个内部循环输出一次。磁力计和 BMP280 受器件输出率限制，采用异步低频更新，避免阻塞 IMU 主循环。

高频测试共采集 3 个 PERF 统计窗口。实测内部更新频率平均为 229.617 Hz，最小值为 226.239 Hz，最大值为 232.033 Hz；IMU 更新频率、互补滤波更新频率和 Mahony 更新频率均与内部循环一致，平均为 229.617 Hz。主循环计算耗时平均为 2451.25 us，占 4 ms 周期的 61.281%；互补滤波平均耗时 52.39 us，Mahony 滤波平均耗时 69.52 us，航向计算平均耗时 50.27 us，三者合计 CPU 占用约 4.305%。

该结果说明，在降低串口输出频率并采用非阻塞磁力计读取后，系统的 IMU 采样和姿态算法更新频率均超过 200 Hz，满足传感器采样不低于 200 Hz、姿态算法更新不低于 100 Hz 的要求。高频测试报告保存为 data/perf_highrate_20260707_090954.txt。

6.8 Spec 达成度检查

为避免只给出单项实验结果而缺少总体判断，本文将系统设计要求和实测完成情况汇总如表 8。表中“通过”表示已有实验数据支撑；“接近”表示平均指标达到或接近目标但最大误差仍有超限；“未达标”表示当前数据不能支撑要求；“待补充”表示缺少必要实测或附件材料。

表 8 Spec 达成度检查

指标 | 目标 | 当前结果 | 状态
必修传感器 | IMU + HMC5883L | I2C 扫描到 0x68、0x1E，驱动和采集完成 | 通过
扩展传感器 | BMP280/GNSS 至少一种 | BMP280 0x76 连通，GNSS NMEA 和 PPS 已验证 | 通过
加速度计标定 | 12 参数六位置，平均误差约 2 mg | 标定后平均向量误差 1.798 mg，最大 2.120 mg | 平均达标，最大接近阈值
磁力计航向 | 平均航向误差约 2 deg | 残差补偿后验证集平均绝对误差 1.907 deg，最大 6.940 deg | 平均达标，最大未达
陀螺仪 Allan/零偏 | 零偏漂移降低 10x | gx 仅改善 1.254x，gy/gz 未改善 | 未达标
姿态融合算法 | 至少 2 种传统算法 | 已实现互补滤波和 Mahony 滤波，并完成对比 | 通过
ESKF 静态姿态 | 静态姿态精度/稳定性 0.2 deg 级 | Roll/Pitch 输出稳定性 RMS 为 0.152 deg，但无角度真值 | 稳定性通过，绝对精度未验证
AI 增强算法 | 至少 1 种 | 1D 卷积 + Kalman 混合去噪，加速度计平均 SNR 提升 18.687 dB | 通过
BMP280 高度实验 | 相对高度实验 | 楼层真值 3.95 m，测得 3.980 m，误差 0.030 m | 通过
GPS NMEA 解析 | GGA/RMC 解析与质量字段 | 校验和通过率 100%，平均卫星数 12.31，HDOP 0.86 | 通过
PPS 时间同步 | PPS 与传感器时间戳统一 | PPS 间隔标准差 0.42 us，IMU 延迟最大 31 us | 通过
GNSS/INS 松耦合 | GPS 与 IMU 数据链路 | 静态数据完成 79 次 GPS 更新，残差 RMS 0.208 m | 静态链路通过
GPS 轨迹叠加 | folium 户外轨迹 | 属于选做扩展，未形成有效户外轨迹点 | 选做未完成
实时姿态显示 | 串口 + Python/Web 可视化 | 已完成网页虚拟板姿态显示，板子运动可实时反映到页面 | 通过
高频采样/更新率 | IMU >=200 Hz，姿态算法 >=100 Hz | 高频模式下 IMU、互补滤波和 Mahony 平均更新 229.617 Hz，最小 226.239 Hz | 通过
系统功耗 | <=100 mA@3.3 V | 尚未用万用表或 USB 电流表实测 | 待补充

7 总结与展望

7.1 工作总结

本文完成了基于 ESP32-S3 的多传感器姿态与定位融合系统设计。硬件层面，完成了 IMU、磁力计、气压计和 GNSS 接口的 PCB 集成与连通验证。驱动层面，完成了 I2C 多设备管理、BMP280 补偿计算、HMC5883L 连续读取、MPU6500 数据采集、GPS UART 接收与 NMEA 解析。算法层面，完成了加速度计 12 参数标定、磁力计椭球拟合、航向残差补偿、互补滤波、Mahony 滤波、ESKF 静态姿态估计、AI IMU 去噪、GNSS/INS 松耦合和 PPS 时间同步验证。实验层面，生成了标定前后对比图、Allan 方差图、磁力计三维点云图、姿态算法对比图、BMP280 楼梯高度图和实时姿态网页显示。

7.2 不足与改进方向

当前系统仍存在若干不足。第一，磁力计航向虽然平均误差接近 2 deg，但最大误差仍超过 2 deg，需要进一步优化磁力计安装位置、远离磁干扰源，并在更稳定的参考方向下重新采集多方向数据。第二，陀螺仪温度补偿未达到零偏漂移降低 10 倍的目标，后续应进行温度箱或自然升温/降温实验，建立更可靠的温度-零偏模型。第三，ESKF 静态实验验证的是输出稳定性，不是绝对姿态精度，后续需要使用水平仪、角度台或已知姿态工装提供真值。第四，GNSS/INS 当前主要在静态数据上验证，户外 GPS 轨迹叠加选做项未完成，后续应先完善有效定位判断和离线日志回传流程，再评价动态定位效果。第五，AI 去噪使用静态弱监督目标，尚未验证对真实运动轨迹误差的改善。

7.3 个人收获与反思

通过本课题，完成了从 PCB 接线确认、嵌入式驱动开发、数据采集、传感器标定、融合算法实现到论文图表整理的完整流程。实验过程中可以看到，低成本传感器的可用性很大程度取决于标定质量、实验工况和数据验证方法。同一个算法如果缺少合适真值，就不能简单宣称精度达标；同一组数据如果采集流程不闭环，也会导致无法复现实验结果。因此，在后续工程实践中，应先完成短时闭环验证，再进行长时间正式采集；在论文表述中，应严格区分“输出稳定性”“相对误差”和“绝对精度”。

致谢

感谢课程提供的 ESP32-S3 开发平台、传感器实验任务和 PCB 设计要求。感谢实验过程中提供硬件接线、传感器模块和测试环境支持的同学与老师。

参考文献

[1] Bosch Sensortec. BMP280 Digital Pressure Sensor Datasheet．

[2] InvenSense. MPU-6000 and MPU-6050 Product Specification．

[3] Honeywell. HMC5883L 3-Axis Digital Compass IC Datasheet．

[4] Mahony R, Hamel T, Pflimlin J M. Nonlinear complementary filters on the special orthogonal group．IEEE Transactions on Automatic Control, 2008．

[5] Madgwick S O H. An efficient orientation filter for inertial and inertial/magnetic sensor arrays．2010．

[6] Groves P D. Principles of GNSS, Inertial, and Multisensor Integrated Navigation Systems．Artech House, 2013．

[7] IEEE. IEEE Standard for Inertial Sensor Terminology．

附录 A PCB 原理图

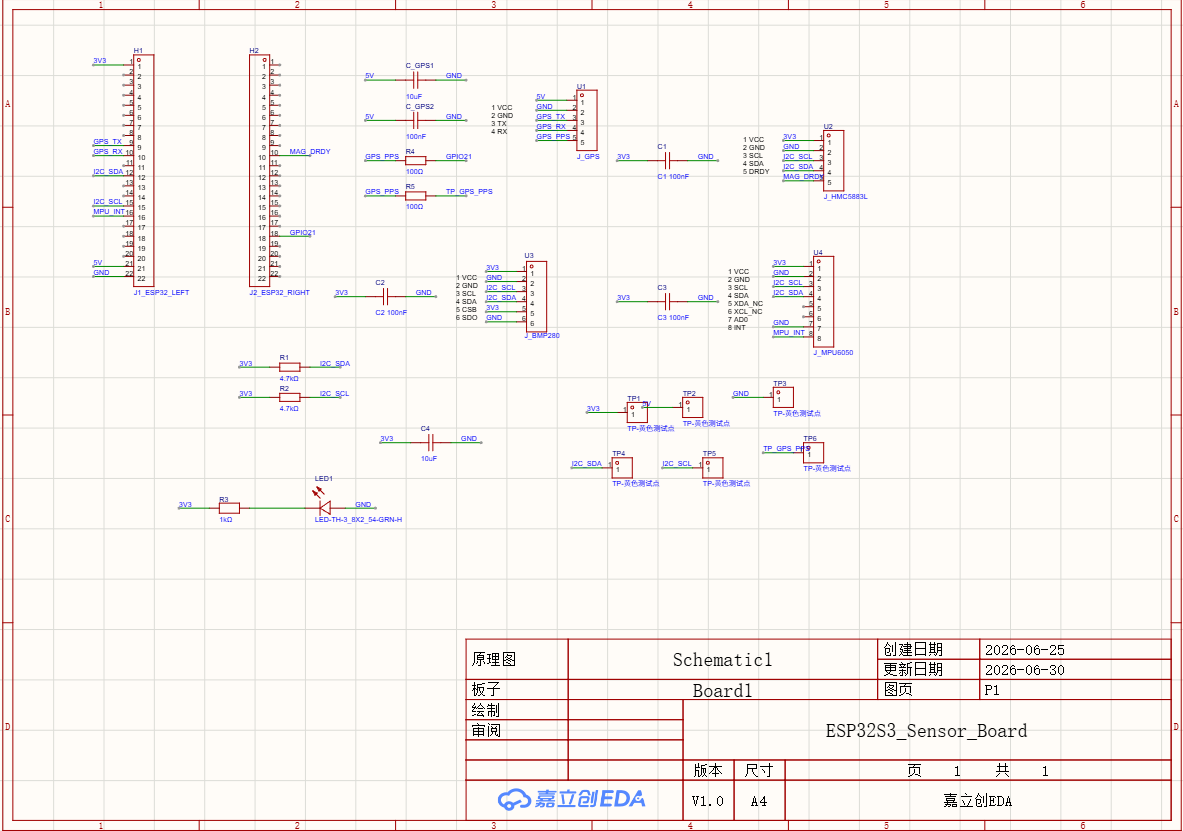
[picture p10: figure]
de08d7e74e2cb897dc14ca3ac1d7065c
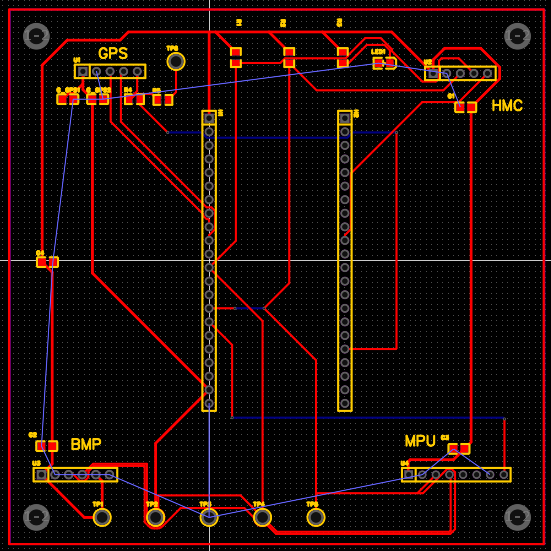
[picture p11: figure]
299129bccc718b297c6448f830902eff

附录 B 关键代码清单

本附录整理本文实验中实际使用的核心程序。完整工程位于 sensor_fusion_nogps_vscode，固件主程序为 main/main.c，离线标定、数据记录和可视化脚本位于 analysis 目录。清单仅保留与论文方法和实验直接对应的关键函数，避免把全部工程代码简单堆入附录。

表 B.1 关键函数与论文内容对应关系

模块 | 文件/函数 | 作用 | 对应章节
I2C 总线 | main/main.c: i2c_bus_init(), i2c_scan() | 配置 ESP32-S3 I2C 主机并扫描 0x1E、0x68、0x76 等设备地址 | 3.1
MPU IMU | mpu_init(), mpu_read_sample(), apply_accel_calibration() | 读取六轴惯性数据，完成 12 参数加速度计标定和陀螺仪温度补偿 | 3.2、4.1、4.4
姿态融合 | complementary_update(), mahony_update() | 实现互补滤波和 Mahony 姿态融合，输出 Roll、Pitch、Yaw | 5.1、6.3
磁力计 | hmc_init(), hmc_read_sample(), mag_calibrate() | 读取三轴磁场，应用椭球拟合得到的硬铁/软铁补偿 | 3.3、4.3、5.2
气压计 | bmp_init(), bmp_read_sample(), pressure_to_altitude() | 读取温度、气压并换算相对高度，用于楼梯高度实验 | 3.4、6.4
GPS | gps_uart_init(), gps_parse_and_print(), gps_pps_isr_handler() | 解析 NMEA GGA/RMC 语句，记录 PPS 时间同步信息 | 3.5、5.3
Python 分析 | analysis/*.py | 完成六位置标定、磁力计椭球拟合、Allan 方差、残差补偿和图表生成 | 4、6

B.1 I2C 总线初始化与设备扫描

I2C 总线采用 ESP-IDF 新版 i2c_master 驱动。初始化后先执行地址扫描，用于确认 IMU、磁力计和气压计是否同时在线。

static esp_err_t i2c_bus_init(void)
{
i2c_master_bus_config_t bus_config = {
.clk_source = I2C_CLK_SRC_DEFAULT,
.i2c_port = I2C_PORT,
.sda_io_num = I2C_SDA_IO,
.scl_io_num = I2C_SCL_IO,
.glitch_ignore_cnt = 7,
.flags.enable_internal_pullup = true,
};
i2c_mutex = xSemaphoreCreateMutex();
return i2c_new_master_bus(&bus_config, &i2c_bus);
}

static void i2c_scan(void)
{
for (uint8_t addr = 1; addr < 0x7F; ++addr) {
if (i2c_master_probe(i2c_bus, addr, 30) == ESP_OK) {
printf("I2C_DEVICE,0x%02X\n", addr);
}
}
}

B.2 MPU 数据读取、12 参数补偿与陀螺仪温度补偿

MPU 原始加速度先按量程换算为 g，再经过 3×3 矩阵和 3×1 零偏向量补偿；角速度使用温度二次模型扣除零偏。

static void apply_accel_calibration(float *ax, float *ay, float *az)
{
float raw[3] = {*ax - C_BIAS[0], *ay - C_BIAS[1], *az - C_BIAS[2]};
float corrected[3];
for (int r = 0; r < 3; ++r) {
corrected[r] = A_INV[r][0] * raw[0] +
A_INV[r][1] * raw[1] +
A_INV[r][2] * raw[2];
}
*ax = corrected[0];
*ay = corrected[1];
*az = corrected[2];
}

static float compensate_gyro(float raw, const float coef[3], float temp)
{
float bias = coef[0] + coef[1] * temp + coef[2] * temp * temp;
return raw - bias;
}

B.3 互补滤波与 Mahony 姿态融合

互补滤波用于 Roll/Pitch 基线姿态估计，Mahony 滤波进一步融合陀螺仪、加速度计和磁力计，输出三轴姿态。

static void complementary_update(const imu_data_t *data)
{
float roll_acc = atan2f(data->ay, data->az) * DEG_PER_RAD;
float pitch_acc = atan2f(-data->ax,
sqrtf(data->ay * data->ay + data->az * data->az)) * DEG_PER_RAD;
float dt_s = (data->timestamp_us - last_attitude_us) / 1000000.0f;
roll_deg = COMP_ALPHA * (roll_deg + data->gx * dt_s) +
(1.0f - COMP_ALPHA) * roll_acc;
pitch_deg = COMP_ALPHA * (pitch_deg + data->gy * dt_s) +
(1.0f - COMP_ALPHA) * pitch_acc;
}

static bool mahony_update(const imu_data_t *imu,
float mx, float my, float mz, float yaw_seed)
{
/* 归一化加速度和磁场，构造误差项 halfex/halfey/halfez。 */
/* 使用比例-积分反馈修正陀螺仪，再积分更新四元数。 */
mahony_update_euler();
return true;
}

B.4 磁力计椭球补偿与倾斜补偿航向

磁力计补偿采用标定得到的硬铁中心 MAG_C 和软铁矩阵 MAG_W。航向计算时先进行倾斜补偿，再由水平磁场分量求角度。

static void mag_calibrate(float bx, float by, float bz,
float *bx_cal, float *by_cal, float *bz_cal)
{
float m0 = bx - MAG_C[0];
float m1 = by - MAG_C[1];
float m2 = bz - MAG_C[2];
*bx_cal = MAG_W[0][0] * m0 + MAG_W[0][1] * m1 + MAG_W[0][2] * m2;
*by_cal = MAG_W[1][0] * m0 + MAG_W[1][1] * m1 + MAG_W[1][2] * m2;
*bz_cal = MAG_W[2][0] * m0 + MAG_W[2][1] * m1 + MAG_W[2][2] * m2;
}

static float compute_tilt_compensated_yaw(float bx, float by, float bz)
{
float roll = roll_deg * RAD_PER_DEG;
float pitch = pitch_deg * RAD_PER_DEG;
float bx_h = bx * cosf(pitch) + bz * sinf(pitch);
float by_h = bx * sinf(roll) * sinf(pitch) +
by * cosf(roll) -
bz * sinf(roll) * cosf(pitch);
return compute_yaw(bx_h, by_h);
}

B.5 BMP280 气压高度换算

BMP280 先按 Bosch 数据手册补偿温度和压力，再用标准气压高度公式计算相对高度。

static float pressure_to_altitude(float pressure_pa, float sea_level_pa)
{
if (pressure_pa <= 0.0f || sea_level_pa <= 0.0f) {
return NAN;
}
return 44330.0f * (1.0f - powf(pressure_pa / sea_level_pa, 0.19029496f));
}

B.6 GPS NMEA 解析与离线记录

GPS 串口接收 NMEA 0183 文本，固件主要解析 GGA 和 RMC 语句。GGA 用于位置、高度、卫星数、HDOP 与定位质量；RMC 用于速度和航向。

static bool gps_checksum_ok(const char *line)
{
const char *star = strchr(line, '*');
uint8_t calc = 0;
for (const char *p = line + 1; p < star; ++p) {
calc ^= (uint8_t)(*p);
}
uint8_t got = (gps_hex_value(star[1]) << 4) | gps_hex_value(star[2]);
return calc == got;
}

static void gps_parse_and_print(const char *line, int64_t rx_done_us)
{
if (strstr(line, "GGA")) {
/* 提取 utc、lat、lon、quality、satellites、hdop、altitude。 */
gps_log_store_gga(fields[1], quality, lat, lon, alt, sats, hdop, checksum_ok);
} else if (strstr(line, "RMC")) {
/* 提取速度 speed_kn 和航向 course_deg。 */
}
}

B.7 主循环调度与性能统计

主循环使用固定周期调度 IMU、磁力计、气压计和串口输出，并通过 PERF 行统计更新频率与 CPU 时间。

while (true) {
int64_t loop_start_us = esp_timer_get_time();
bmp_log_poll_uart_commands();
gps_poll_uart();

if (has_mpu && mpu_read_sample(&imu) == ESP_OK) {
complementary_update(&imu);
}
if (has_hmc && due_hmc) {
hmc_read_sample(&mag);
mag_calibrate(mag.bx, mag.by, mag.bz, &bx_cal, &by_cal, &bz_cal);
yaw_tilt = compute_tilt_compensated_yaw(bx_cal, by_cal, bz_cal);
mahony_update(&imu, bx_cal, by_cal, bz_cal, yaw_tilt);
}
perf_record(...);
vTaskDelayUntil(&last_wake, pdMS_TO_TICKS(LOOP_PERIOD_MS));
}

附录 C 物料清单（BOM）

BOM 根据 PCB 原理图、实际接线记录和传感器调试结果整理。由于本项目使用 ESP32-S3 开发板插接扩展板，表中将开发板、传感器模块、接口排针、上拉/限流电阻和去耦电容分别列出。

表 C.1 多传感器扩展板 BOM

序号 | 器件 | 规格/型号 | 数量 | 封装/接口 | 说明
1 | 主控开发板 | ESP32-S3 DevKit/兼容开发板 | 1 | 2×排针插接 | 提供 I2C、UART、GPIO、USB 下载和串口输出
2 | 六轴 IMU | MPU6050/MPU6500 兼容模块 | 1 | I2C 模块 | 地址 0x68，实测 WHO_AM_I=0x70
3 | 三轴磁力计 | HMC5883L/GY-273 | 1 | I2C 模块 | 地址 0x1E，用于航向估计和椭球标定
4 | 气压计 | BMP280/BME280 | 1 | I2C 模块 | 地址 0x76，实测 chip_id=0x58
5 | GNSS 模块接口 | GPS UART + PPS | 1 | 5Pin 排针 | RX/TX 接 GPIO16/GPIO17，PPS 接 GPIO21
6 | ESP32 左侧排针 | H1 | 1 | 2.54 mm 排针 | 引出 3V3、5V、GND、I2C、GPS UART、MPU_INT
7 | ESP32 右侧排针 | H2 | 1 | 2.54 mm 排针 | 引出 MAG_DRDY、GPS_PPS 等信号
8 | I2C 上拉电阻 | 4.7 kΩ | 2 | 0603/0805 | R1、R2，SDA/SCL 上拉到 3V3
9 | GPS 串口保护/串联电阻 | 100 Ω | 2 | 0603/0805 | R4、R5，用于 GPS RX/PPS 相关信号预留
10 | LED 限流电阻 | 1 kΩ | 1 | 0603/0805 | R3，配合 LED1 作为状态指示
11 | 状态指示灯 | LED1 | 1 | 0603/0805 | 用于电源或程序状态提示
12 | I2C/传感器去耦电容 | 0.1 µF | 2 | 0603/0805 | C1、C2，靠近传感器电源引脚
13 | GPS 电源电容 | 10 µF | 2 | 0603/0805/钽电容 | C_GPS1、C_GPS2，GPS 供电滤波
14 | 扩展 PCB | 双层 FR-4 | 1 | 嘉立创制板 | 承载传感器模块、排针和连接网络
15 | 修正飞线 | 3V3 至 GPS VCC | 1 | 导线 | 实际调试中 GPS VCC 改接 3V3，避免 5V 接入风险

说明：I2C 总线实测能同时扫描到 HMC5883L、MPU 兼容 IMU 和 BMP280/BME280；GPS 接口采用 UART，PPS 信号接入 GPIO 中断用于时间同步实验。GPS 供电部分按实际调试结果记录为 3V3 修正接法。

附录 D 嘉立创订单截图与 Gerber 文件

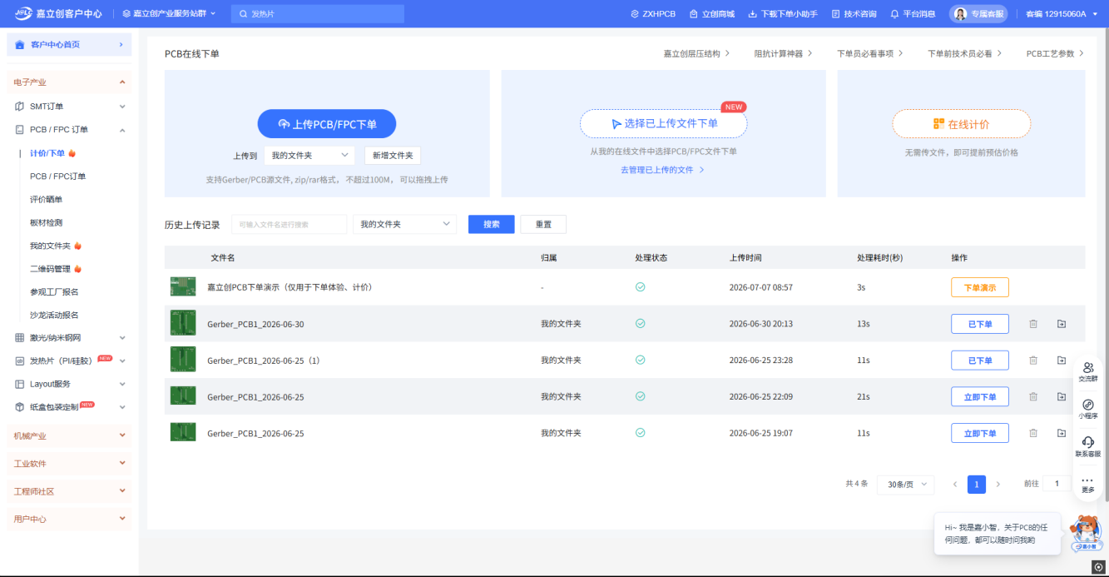
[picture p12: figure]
9c3b0009c5e5c1a0a1741a3a57b19d40

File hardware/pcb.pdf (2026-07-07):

## PCB ?????????

??? PCB ?????? Gerber ??????????????? hardware/gerber/?

Gerber ????/?????????????????????????????????????

?????

- Gerber_TopLayer.GTL?????
- Gerber_BottomLayer.GBL?????
- Gerber_TopSilkscreenLayer.GTO?????
- Gerber_BoardOutlineLayer.GKO???
- Drill_PTH_Through.DRL / Drill_PTH_Through_Via.DRL?????
- FlyingProbeTesting.json???????

?????????? EDA ??????? PCB ?? PDF???? PDF ?? PCB ???????

????? PCB ??? hardware/gerber/Gerber_PCB1_2026-06-30.zip ????????

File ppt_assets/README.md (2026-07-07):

# PPT 图片素材索引

这些图片用于制作课程汇报 PPT，均为 PNG 格式，避免 SVG 在 Office/WPS 中出现遮挡或缩放问题。

| 文件 | 内容 |
|---|---|
| `01_system_architecture.png` | 系统总体架构 |
| `02_accel_calibration_errors.png` | 加速度计六位置标定误差 |
| `03_mag_3d_scatter_before_after.png` | 磁力计校准前后三维散点 |
| `04_mag_norm_before_after.png` | 磁力计校准前后模长 |
| `05_heading_residual_errors.png` | 航向残差补偿误差 |
| `06_attitude_algorithm_compare.png` | 互补滤波与 Mahony 对比 |
| `07_gyro_allan_deviation.png` | 陀螺仪 Allan 方差 |
| `08_bmp_stair_height.png` | BMP280 楼梯高度实验 |
| `09_gnss_ins_static.png` | GNSS/INS 静态松耦合 |
| `10_gps_static_scatter.png` | GPS 静态定位散点 |
| `11_gps_static_drift.png` | GPS 静态漂移 |
| `12_gps_static_altitude.png` | GPS 静态高度变化 |

主要说明和 PPT 使用建议见 `docs/PPT结果展示素材整理.md`。

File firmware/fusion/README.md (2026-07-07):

# fusion

本目录包含姿态融合、GNSS/INS 和可视化相关脚本：

- 互补滤波与 Mahony 滤波主实现位于 `../main.c`
- `analyze_attitude_compare.py`：姿态算法结果对比
- `analyze_eskf_static.py`：静态姿态精度分析
- `gnss_ins_loose_coupling.py`：GNSS/INS 松耦合静态分析
- `realtime_attitude_web.py`：串口实时姿态网页显示

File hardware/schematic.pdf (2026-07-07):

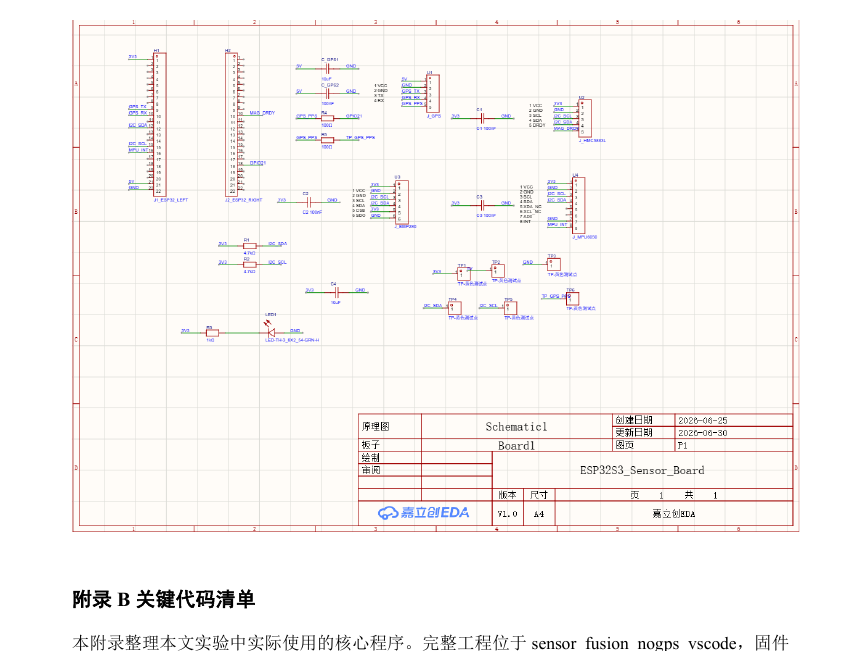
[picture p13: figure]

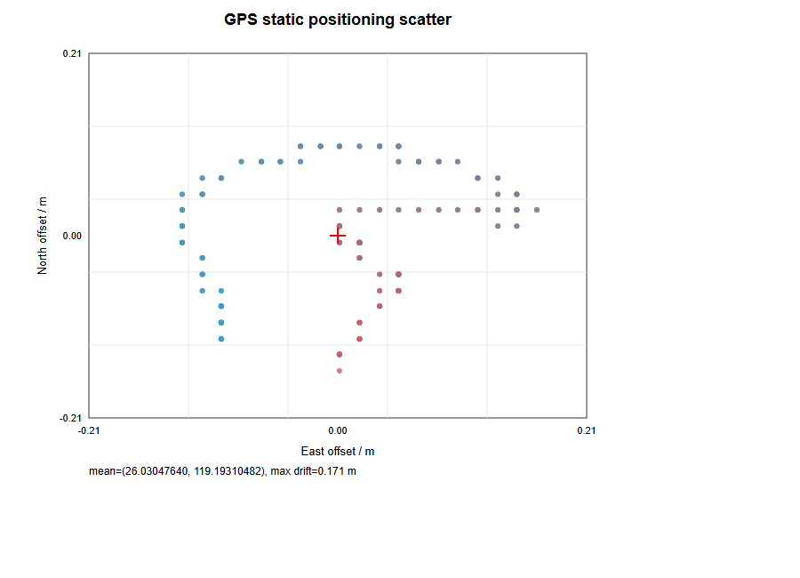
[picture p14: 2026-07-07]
ppt_assets/10_gps_static_scatter.png

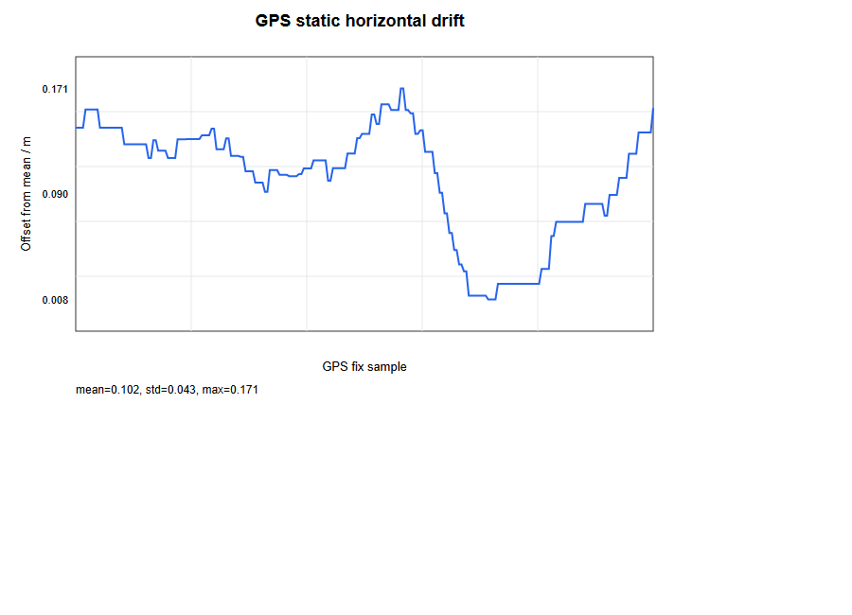
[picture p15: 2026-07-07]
ppt_assets/11_gps_static_drift.png

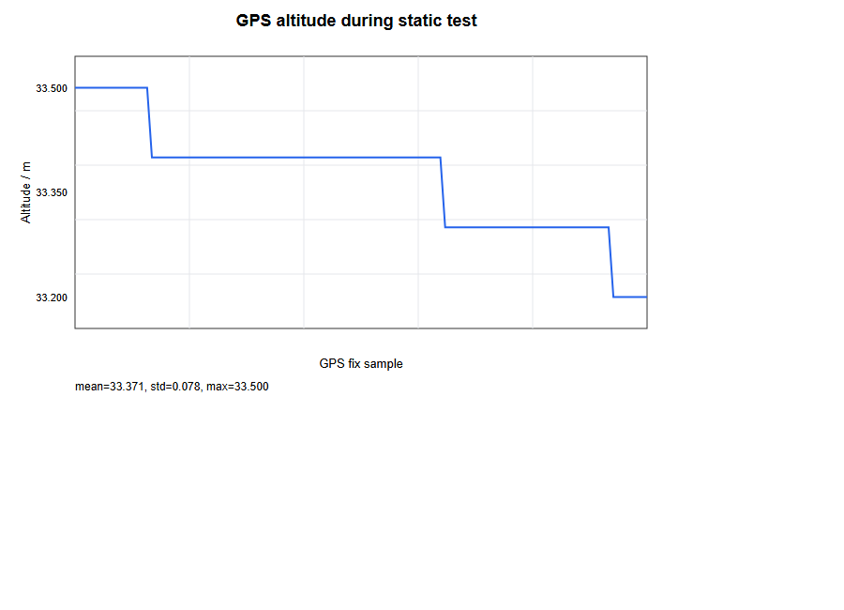
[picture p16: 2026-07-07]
ppt_assets/12_gps_static_altitude.png

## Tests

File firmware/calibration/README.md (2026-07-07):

# calibration

本目录包含课程项目使用的标定与误差分析脚本：

- `calibrate_accel_sixpos.py`：加速度计六位置 12 参数标定
- `calibrate_mag_ellipsoid.py`：磁力计椭球拟合硬铁/软铁补偿
- `analyze_allan.py`：陀螺仪 Allan 方差分析
- `heading_residual_cv.py`：航向残差补偿与交叉验证

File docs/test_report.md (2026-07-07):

# 测试报告

## 1. 硬件连通性

ESP32-S3 通过 I2C 总线连接三类传感器，实测扫描结果包含：

- HMC5883L：`0x1E`
- MPU6050/MPU6500 兼容 IMU：`0x68`
- BMP280/BME280：`0x76`

GNSS 模块通过 UART 接入，RX/TX 分别接 GPIO16/GPIO17，PPS 接 GPIO21。

## 2. 标定结果

### 2.1 加速度计

采用六位置 12 参数模型进行加速度计标定。代表性结果：

- 标定后平均向量误差：`1.798 mg`
- 标定后最大向量误差：`2.120 mg`
- 目标阈值：约 `2 mg`

数据文件位于 `data/calibration/accel_6pos_20260705_114101.csv`。

### 2.2 磁力计

采用椭球拟合估计硬铁中心和软铁补偿矩阵。代表性结果：

- 原始磁场模长均值/标准差：`46.285 / 3.303 uT`
- 补偿后磁场模长均值/标准差：`52.248 / 1.892 uT`

数据文件位于 `data/calibration/mag_rotate_20260705_135521.csv`。

### 2.3 陀螺仪 Allan 方差

完成 300 s 级静态陀螺仪采集和 Allan 方差分析，结果见：

- `data/calibration/gyro_allan_20260705_171933_allan.csv`
- `figures/gyro_allan_deviation.png`

## 3. 姿态融合与可视化

实现互补滤波和 Mahony 滤波两种传统姿态融合算法。实时网页显示能够显示 Roll、Pitch、Yaw、气压高度、磁场模长和样本计数。

相关图表：

- `figures/attitude_algorithm_compare.png`
- `figures/system_architecture.png`

## 4. AI 增强算法

完成 IMU 静态数据 1D 卷积去噪，并与传统低通滤波、1D 卷积 + 一阶 Kalman 混合结构对比。代表性结果：

- 加速度计平均 SNR 提升：传统低通 `9.686 dB`，1D 卷积 `18.121 dB`，1D 卷积 + Kalman `18.687 dB`
- 陀螺仪平均 SNR 提升：传统低通 `12.299 dB`，1D 卷积 `15.697 dB`，1D 卷积 + Kalman `15.837 dB`

## 5. 气压高度实验

BMP280 楼梯高度实验中，人工测量楼层高度 `3.95 m`，BMP280 测量高度约 `3.980 m`，绝对误差约 `0.030 m`，相对误差约 `0.76%`。

相关文件：

- `data/fusion_comparison/bmp_stair_height_20260706_summary.csv`
- `figures/bmp_stair_height_20260706.png`

## 6. GNSS 与时间同步

完成 GNSS NMEA 解析、PPS 时间同步记录和 GNSS/INS 松耦合静态分析。由于台式电脑无法移动，户外连续轨迹叠加未作为最终必做结果提交。

相关文件：

- `data/fusion_comparison/gps_nmea_parse_20260706_171832.csv`
- `data/performance/time_sync_static_20260706_105553.csv`
- `figures/gps_nmea_parse_20260706_171832_gnss_ins_20260706_172456.png`

## 7. 性能测试

板端性能统计证明高频采样/更新达到要求：

- 主循环更新频率：约 `229.617 Hz`
- IMU 更新频率：约 `229.617 Hz`
- 互补滤波更新频率：约 `229.617 Hz`
- Mahony 更新频率：约 `229.617 Hz`

数据文件位于 `data/performance/perf_highrate_20260707_090954.txt`。

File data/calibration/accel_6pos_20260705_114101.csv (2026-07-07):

cycle | position | ax_raw_g | ay_raw_g | az_raw_g
1 | +Z | -0.019043 | 0.015625 | 0.971191
1 | +Z | -0.018066 | 0.01709 | 0.966797
1 | +Z | -0.010742 | 0.019287 | 0.960449
1 | +Z | -0.019043 | 0.017578 | 0.965332
1 | +Z | -0.01709 | 0.012207 | 0.966309
1 | +Z | -0.010498 | 0.015869 | 0.963623
1 | +Z | -0.016846 | 0.018555 | 0.966309
1 | +Z | -0.011719 | 0.017578 | 0.96582
1 | +Z | -0.015381 | 0.013916 | 0.962891
1 | +Z | -0.021729 | 0.016357 | 0.968262
1 | +Z | -0.011719 | 0.015625 | 0.967285
1 | +Z | -0.016846 | 0.017578 | 0.963379
1 | +Z | -0.019531 | 0.017822 | 0.967529
1 | +Z | -0.018311 | 0.013428 | 0.969482
1 | +Z | -0.013916 | 0.020264 | 0.969482
1 | +Z | -0.01709 | 0.017822 | 0.970215
1 | +Z | -0.017822 | 0.012939 | 0.967529
1 | +Z | -0.014893 | 0.014648 | 0.965576
1 | +Z | -0.010986 | 0.020996 | 0.960205
1 | +Z | -0.024414 | 0.014893 | 0.962402
1 | +Z | -0.015869 | 0.016846 | 0.974854
1 | +Z | -0.020508 | 0.014648 | 0.966797
1 | +Z | -0.019531 | 0.01709 | 0.964844
1 | +Z | -0.021973 | 0.012451 | 0.968262
1 | +Z | -0.016602 | 0.015381 | 0.971191
1 | +Z | -0.022461 | 0.018555 | 0.9646
1 | +Z | -0.019775 | 0.014648 | 0.965332
1 | +Z | -0.01123 | 0.01416 | 0.9646
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

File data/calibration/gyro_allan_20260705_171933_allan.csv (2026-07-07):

series | tau_s | adev_dps | clusters
gx_raw_dps | 0.220000 | 0.031380165 | 16364
gx_raw_dps | 0.330000 | 0.025713121 | 10909
gx_raw_dps | 0.440000 | 0.021890552 | 8182
gx_raw_dps | 0.550000 | 0.019675842 | 6545
gx_raw_dps | 0.660000 | 0.018075329 | 5454
gx_raw_dps | 0.770000 | 0.016808535 | 4675
gx_raw_dps | 0.880000 | 0.015941645 | 4091
gx_raw_dps | 1.100000 | 0.014536343 | 3272
gx_raw_dps | 1.320000 | 0.013167056 | 2727
gx_raw_dps | 1.650000 | 0.012066498 | 2181
gx_raw_dps | 2.090000 | 0.010972496 | 1722
gx_raw_dps | 2.530000 | 0.010193608 | 1422
gx_raw_dps | 3.080000 | 0.009284591 | 1168
gx_raw_dps | 3.740000 | 0.008430464 | 962
gx_raw_dps | 4.620000 | 0.007364372 | 779
gx_raw_dps | 5.610000 | 0.007057074 | 641
gx_raw_dps | 6.930000 | 0.006199072 | 519
gx_raw_dps | 8.470000 | 0.005782226 | 425
gx_raw_dps | 10.340000 | 0.005692834 | 348
gx_raw_dps | 12.760000 | 0.005287214 | 282
gx_raw_dps | 15.620000 | 0.005266990 | 230
gx_raw_dps | 19.030000 | 0.004839625 | 189
gx_raw_dps | 23.320000 | 0.004701033 | 154
gx_raw_dps | 28.600000 | 0.004818371 | 125
gx_raw_dps | 35.090000 | 0.004611279 | 102
gx_raw_dps | 42.900000 | 0.005094527 | 83
gx_raw_dps | 52.580000 | 0.005202572 | 68
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

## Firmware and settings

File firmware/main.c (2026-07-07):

#include <math.h>
#include <stdbool.h>
#include <stdint.h>
#include <stdio.h>
#include <stdlib.h>
#include <string.h>

#include "driver/gpio.h"
#include "driver/i2c_master.h"
#include "driver/uart.h"
#include "driver/usb_serial_jtag.h"
#include "esp_check.h"
#include "esp_attr.h"
#include "esp_err.h"
#include "esp_log.h"
#include "esp_rom_sys.h"
#include "esp_timer.h"
#include "freertos/FreeRTOS.h"
#include "freertos/semphr.h"
#include "freertos/task.h"
#include "nvs.h"
#include "nvs_flash.h"

#define I2C_PORT I2C_NUM_0

// 当前固定在 ESP32-S3 扩展板上，I2C 飞线为 SDA=GPIO8、SCL=GPIO9。
// 如果以后换成普通 ESP32 开发板，则使用下面 else 分支的 GPIO21/GPIO22。
#if CONFIG_IDF_TARGET_ESP32S3
#define I2C_SDA_IO GPIO_NUM_8
#define I2C_SCL_IO GPIO_NUM_9
#else
#define I2C_SDA_IO GPIO_NUM_21
#define I2C_SCL_IO GPIO_NUM_22
#endif

#define I2C_FREQ_HZ 100000
#define I2C_TIMEOUT_MS 100

#define GPS_UART_PORT UART_NUM_1
#define GPS_UART_RX_IO GPIO_NUM_16
#define GPS_UART_TX_IO GPIO_NUM_17
#define GPS_UART_BAUD 9600
#define GPS_UART_BUF_SIZE 1024
#define GPS_NMEA_LINE_MAX 160
#define GPS_STATUS_PERIOD_US 5000000LL
#define GPS_PPS_IO GPIO_NUM_21
#define GPS_SYNC_TASK_STACK 4096
#define GPS_SYNC_TASK_PRIORITY 10

#define MPU_ADDR 0x68
#define MPU_REG_SMPLRT_DIV 0x19
#define MPU_REG_CONFIG 0x1A
#define MPU_REG_GYRO_CONFIG 0x1B
#define MPU_REG_ACCEL_CONFIG 0x1C
#define MPU_REG_ACCEL_XOUT_H 0x3B
#define MPU_REG_PWR_MGMT_1 0x6B
#define MPU_REG_WHO_AM_I 0x75
#define MPU_WHO_AM_I_6050 0x68
#define MPU_WHO_AM_I_6500 0x70
#define ACCEL_SCALE_2G 16384.0f
#define GYRO_SCALE_500 65.5f

#define HMC_ADDR 0x1E
#define HMC_REG_CRA 0x00
#define HMC_REG_CRB 0x01
#define HMC_REG_MODE 0x02
#define HMC_REG_DOUT 0x03
#define HMC_REG_SR 0x09
#define HMC_REG_IDA 0x0A
#define HMC_GAIN_LSB_PER_GAUSS 1090.0f

#define BMP280_ADDR_PRIMARY 0x76
#define BMP280_ADDR_SECONDARY 0x77
#define BMP280_REG_ID 0xD0
#define BMP280_REG_RESET 0xE0
#define BMP280_REG_CTRL_MEAS 0xF4
#define BMP280_REG_CONFIG 0xF5
#define BMP280_REG_PRESS_MSB 0xF7
#define BMP280_REG_CALIB 0x88

#define LOOP_PERIOD_MS 4
#define SENSOR_PRINT_PERIOD_MS 100
#define HMC_READ_PERIOD_MS 20
#define BMP_READ_PERIOD_MS 100
#define COMPLEMENTARY_ALPHA 0.98f
#define DEG_PER_RAD 57.2957795f
#define RAD_PER_DEG 0.0174532925f
#define MAHONY_TWO_KP 2.0f
#define MAHONY_TWO_KI 0.0f
#define BMP_LOG_MAGIC 0x424D5031u
#define BMP_LOG_MAX_SAMPLES 360
#define BMP_LOG_DEFAULT_SECONDS 180
#define BMP_LOG_INTERVAL_MS 500
#define BMP_LOG_CMD_BUF_LEN 96
#define GPS_LOG_MAGIC 0x47505332u
#define GPS_LOG_MAX_SAMPLES 600
#define GPS_LOG_DEFAULT_SECONDS 300
#define PERF_REPORT_SAMPLES 1000

static const char *TAG = "NO_GPS_FUSION";

// 三个传感器共用同一条 I2C 总线，启动时分别添加为独立设备句柄。
static i2c_master_bus_handle_t i2c_bus;
static i2c_master_dev_handle_t mpu_dev;
static i2c_master_dev_handle_t hmc_dev;
static i2c_master_dev_handle_t bmp_dev;
static SemaphoreHandle_t i2c_mutex;

static bool has_mpu;
static bool has_hmc;
static bool has_bmp;
static bool has_gps_uart;
static uint8_t bmp_addr;

static bool attitude_initialized;
static int64_t last_attitude_us;
static float roll_deg;
static float pitch_deg;
static bool mahony_initialized;
static int64_t last_mahony_us;
static float mahony_q0 = 1.0f;
static float mahony_q1;
static float mahony_q2;
static float mahony_q3;
static float mahony_integral_x;
static float mahony_integral_y;
static float mahony_integral_z;
static float mahony_roll_deg;
static float mahony_pitch_deg;
static float mahony_yaw_deg;
static float p0_pa;

// MPU6050/MPU6500 加速度计六位置标定参数。
// 标定文件：data/accel_calibration_20260705_114101.txt
// 模型：raw = A * true + C_BIAS，固件中使用 corrected = A_INV * (raw - C_BIAS)。
// 本次验证：标定前平均模长误差 20.068 mg，标定后平均向量残差 1.798 mg。
static const float A_INV[3][3] = {
    {1.000085932f, 0.028224218f, 0.001797831f},
    {-0.028359154f, 1.000349137f, -0.021617191f},
    {-0.004685815f, 0.009701288f, 0.989644763f},
};

static const float C_BIAS[3] = {
    -0.013395542f,
    -0.004354629f,
    -0.044735174f,
};

static const float GYRO_GX_COEF[3] = {2.08491024f, 0.02963530f, -0.00101791f};
static const float GYRO_GY_COEF[3] = {-0.95428364f, 0.08098127f, -0.00180494f};
static const float GYRO_GZ_COEF[3] = {1.28524201f, -0.06686667f, 0.00116076f};

// HMC5883L 磁力计椭球标定参数。
// 标定文件：data/mag_calibration_20260705_134935.txt
// 阶段结果：磁场模长标准差由 3.303 uT 降至 1.892 uT，后续仍需 12 方向航向验证。
static const float MAG_C[3] = {
    2.380116446f,
    -2.222724669f,
    1.008089606f,
};

static const float MAG_W[3][3] = {
    {1.185171607f, 0.006230829f, 0.030442137f},
    {0.006230829f, 1.154072552f, 0.005094636f},
    {0.030442137f, 0.005094636f, 1.210237276f},
};

typedef struct {
    uint16_t dig_T1;
    int16_t dig_T2;
    int16_t dig_T3;
    uint16_t dig_P1;
    int16_t dig_P2;
    int16_t dig_P3;
    int16_t dig_P4;
    int16_t dig_P5;
    int16_t dig_P6;
    int16_t dig_P7;
    int16_t dig_P8;
    int16_t dig_P9;
} bmp280_calib_t;

typedef struct {
    int64_t timestamp_us;
    // raw 字段保留未标定数据，用于重新标定和报告对比。
    float ax_raw;
    float ay_raw;
    float az_raw;
    float gx_raw;
    float gy_raw;
    float gz_raw;
    // 非 raw 字段为固件补偿后的正式输出，姿态算法也使用这些值。
    float ax;
    float ay;
    float az;
    float gx;
    float gy;
    float gz;
    float temp;
} imu_data_t;

typedef struct {
    int64_t timestamp_us;
    float bx;
    float by;
    float bz;
    float magnitude;
} mag_data_t;

typedef struct {
    int64_t timestamp_us;
    float temperature_c;
    float pressure_pa;
    float altitude_m;
} baro_data_t;

typedef struct __attribute__((packed)) {
    uint32_t t_ms;
    int32_t pressure_pa_x100;
    int16_t temp_c_x100;
    int16_t altitude_cm;
} bmp_log_sample_t;

typedef struct {
    uint32_t magic;
    uint32_t sequence;
    uint32_t count;
    uint32_t interval_ms;
    uint32_t duration_ms;
    float p0_pa;
} bmp_log_meta_t;

typedef struct __attribute__((packed)) {
    uint32_t t_ms;
    uint32_t utc_ms;
    int32_t lat_e7;
    int32_t lon_e7;
    int32_t altitude_cm;
    int32_t baro_pressure_pa_x100;
    int16_t baro_temp_c_x100;
    int16_t baro_altitude_cm;
    uint16_t speed_kn_x100;
    uint16_t course_deg_x100;
    uint16_t hdop_x100;
    uint8_t satellites;
    uint8_t quality;
    uint8_t checksum_ok;
} gps_log_sample_t;

typedef struct {
    uint32_t magic;
    uint32_t sequence;
    uint32_t count;
    uint32_t duration_ms;
} gps_log_meta_t;

typedef struct {
    uint32_t count;
    int64_t window_start_us;
    int64_t window_end_us;
    uint32_t imu_update_count;
    uint32_t comp_update_count;
    uint32_t mahony_update_count;
    uint32_t sensor_print_count;
    int64_t loop_sum_us;
    int64_t loop_max_us;
    int64_t mpu_sum_us;
    int64_t mpu_max_us;
    int64_t comp_sum_us;
    int64_t comp_max_us;
    int64_t hmc_sum_us;
    int64_t hmc_max_us;
    int64_t yaw_sum_us;
    int64_t yaw_max_us;
    int64_t mahony_sum_us;
    int64_t mahony_max_us;
    int64_t bmp_sum_us;
    int64_t bmp_max_us;
} perf_stats_t;

static bmp280_calib_t bmp_calib;
static int32_t bmp_t_fine;
static bmp_log_sample_t bmp_log_buffer[BMP_LOG_MAX_SAMPLES];
static gps_log_sample_t gps_log_buffer[GPS_LOG_MAX_SAMPLES];
static bool nvs_ready;
static char bmp_log_cmd_buf[BMP_LOG_CMD_BUF_LEN];
static size_t bmp_log_cmd_len;
static perf_stats_t perf_stats;
static char gps_nmea_line[GPS_NMEA_LINE_MAX];
static size_t gps_nmea_len;
static uint32_t gps_nmea_lines;
static uint32_t gps_nmea_bytes;
static int64_t gps_last_status_us;
static volatile uint32_t gps_pps_count;
static volatile int64_t gps_last_pps_us;
static portMUX_TYPE gps_pps_mux = portMUX_INITIALIZER_UNLOCKED;
static uint32_t gps_reported_pps_count;
static int64_t gps_prev_reported_pps_us;
static TaskHandle_t gps_sync_task_handle;
static bool gps_log_capture_active;
static int64_t gps_log_capture_start_us;
static uint32_t gps_log_capture_count;
static uint16_t gps_latest_speed_kn_x100;
static uint16_t gps_latest_course_deg_x100;

static int16_t be_i16(const uint8_t *buf)
{
    return (int16_t)((buf[0] << 8) | buf[1]);
}

static uint16_t le_u16(const uint8_t *buf)
{
    return (uint16_t)(buf[0] | (buf[1] << 8));
}

static void gps_poll_uart(void);
static bool gps_log_handle_command(const char *cmd);

static int16_t le_i16(const uint8_t *buf)
{
    return (int16_t)(buf[0] | (buf[1] << 8));
}

static esp_err_t add_i2c_device(uint8_t addr, i2c_master_dev_handle_t *out)
{
    i2c_device_config_t dev_config = {
        .dev_addr_length = I2C_ADDR_BIT_LEN_7,
        .device_address = addr,
        .scl_speed_hz = I2C_FREQ_HZ,
    };
    return i2c_master_bus_add_device(i2c_bus, &dev_config, out);
}

static esp_err_t dev_read(i2c_master_dev_handle_t dev, uint8_t reg, uint8_t *data, size_t len)
{
    if (i2c_mutex && xSemaphoreTake(i2c_mutex, pdMS_TO_TICKS(I2C_TIMEOUT_MS)) != pdTRUE) {
        return ESP_ERR_TIMEOUT;
    }
    esp_err_t err = i2c_master_transmit_receive(dev, &reg, 1, data, len, I2C_TIMEOUT_MS);
    if (i2c_mutex) {
        xSemaphoreGive(i2c_mutex);
    }
    return err;
}

static esp_err_t dev_write_u8(i2c_master_dev_handle_t dev, uint8_t reg, uint8_t value)
{
    uint8_t data[2] = {reg, value};
    if (i2c_mutex && xSemaphoreTake(i2c_mutex, pdMS_TO_TICKS(I2C_TIMEOUT_MS)) != pdTRUE) {
        return ESP_ERR_TIMEOUT;
    }
    esp_err_t err = i2c_master_transmit(dev, data, sizeof(data), I2C_TIMEOUT_MS);
    if (i2c_mutex) {
        xSemaphoreGive(i2c_mutex);
    }
    return err;
}

static esp_err_t i2c_bus_init(void)
{
    i2c_master_bus_config_t bus_config = {
        .clk_source = I2C_CLK_SRC_DEFAULT,
        .i2c_port = I2C_PORT,
        .scl_io_num = I2C_SCL_IO,
        .sda_io_num = I2C_SDA_IO,
        .glitch_ignore_cnt = 7,
        .flags.enable_internal_pullup = true,
    };

    i2c_mutex = xSemaphoreCreateMutex();
    if (!i2c_mutex) {
        return ESP_ERR_NO_MEM;
    }
    ESP_RETURN_ON_ERROR(i2c_new_master_bus(&bus_config, &i2c_bus), TAG, "I2C bus init failed");
    ESP_LOGI(TAG, "I2C initialized: SDA=%d SCL=%d freq=%d Hz", I2C_SDA_IO, I2C_SCL_IO, I2C_FREQ_HZ);
    return ESP_OK;
}

static void i2c_scan(void)
{
    // 上电自检：确认 0x68(MPU)、0x1E(HMC)、0x76(BMP) 是否在总线上。
    printf("I2C_SCAN_BEGIN\n");
    for (uint8_t addr = 0x03; addr <= 0x77; addr++) {
        esp_err_t err = i2c_master_probe(i2c_bus, addr, 30);
        if (err == ESP_OK) {
            printf("I2C_DEVICE,0x%02X\n", addr);
        }
    }
    printf("I2C_SCAN_END\n");
}

static esp_err_t mpu_init(void)
{
    ESP_RETURN_ON_ERROR(add_i2c_device(MPU_ADDR, &mpu_dev), TAG, "add MPU failed");

    uint8_t id = 0;
    esp_err_t err = dev_read(mpu_dev, MPU_REG_WHO_AM_I, &id, 1);
    if (err != ESP_OK) {
        ESP_LOGW(TAG, "MPU not found at 0x%02X: %s", MPU_ADDR, esp_err_to_name(err));
        return err;
    }
    if (id != MPU_WHO_AM_I_6050 && id != MPU_WHO_AM_I_6500 && id != 0x69) {
        ESP_LOGW(TAG, "Unexpected MPU WHO_AM_I=0x%02X; continuing for board test", id);
    } else {
        ESP_LOGI(TAG, "MPU detected: WHO_AM_I=0x%02X", id);
    }

    ESP_RETURN_ON_ERROR(dev_write_u8(mpu_dev, MPU_REG_PWR_MGMT_1, 0x01), TAG, "wake MPU failed");
    vTaskDelay(pdMS_TO_TICKS(100));
    ESP_RETURN_ON_ERROR(dev_write_u8(mpu_dev, MPU_REG_SMPLRT_DIV, 3), TAG, "MPU sample rate failed");
    ESP_RETURN_ON_ERROR(dev_write_u8(mpu_dev, MPU_REG_CONFIG, 0x03), TAG, "MPU DLPF failed");
    ESP_RETURN_ON_ERROR(dev_write_u8(mpu_dev, MPU_REG_GYRO_CONFIG, 0x08), TAG, "MPU gyro range failed");
    ESP_RETURN_ON_ERROR(dev_write_u8(mpu_dev, MPU_REG_ACCEL_CONFIG, 0x00), TAG, "MPU accel range failed");

    has_mpu = true;
    return ESP_OK;
}

static void apply_accel_calibration(float *ax, float *ay, float *az)
{
    // 六位置标定的在线应用：先减零偏，再乘 3x3 逆矩阵修正比例因子与轴间耦合。
    float raw[3] = {
        *ax - C_BIAS[0],
        *ay - C_BIAS[1],
        *az - C_BIAS[2],
    };
    float corrected[3];
    for (int row = 0; row < 3; row++) {
        corrected[row] = A_INV[row][0] * raw[0] +
                         A_INV[row][1] * raw[1] +
                         A_INV[row][2] * raw[2];
    }
    *ax = corrected[0];
    *ay = corrected[1];
    *az = corrected[2];
}

static float compensate_gyro(float raw, const float coef[3], float temp)
{
    // 陀螺仪温度补偿使用二次多项式 bias = a + b*T + c*T^2。
    float bias = coef[0] + coef[1] * temp + coef[2] * temp * temp;
    return raw - bias;
}

static esp_err_t mpu_read_sample(imu_data_t *out)
{
    uint8_t raw[14];
    ESP_RETURN_ON_ERROR(dev_read(mpu_dev, MPU_REG_ACCEL_XOUT_H, raw, sizeof(raw)), TAG, "read MPU sample failed");

    int16_t raw_ax = be_i16(&raw[0]);
    int16_t raw_ay = be_i16(&raw[2]);
    int16_t raw_az = be_i16(&raw[4]);
    int16_t raw_temp = be_i16(&raw[6]);
    int16_t raw_gx = be_i16(&raw[8]);
    int16_t raw_gy = be_i16(&raw[10]);
    int16_t raw_gz = be_i16(&raw[12]);

    out->timestamp_us = esp_timer_get_time();
    out->ax_raw = raw_ax / ACCEL_SCALE_2G;
    out->ay_raw = raw_ay / ACCEL_SCALE_2G;
    out->az_raw = raw_az / ACCEL_SCALE_2G;
    out->gx_raw = raw_gx / GYRO_SCALE_500;
    out->gy_raw = raw_gy / GYRO_SCALE_500;
    out->gz_raw = raw_gz / GYRO_SCALE_500;

    // 加速度：同时输出 raw 和标定后数据，便于验证“标定前/后误差”。
    out->ax = out->ax_raw;
    out->ay = out->ay_raw;
    out->az = out->az_raw;
    out->temp = raw_temp / 340.0f + 36.53f;
    apply_accel_calibration(&out->ax, &out->ay, &out->az);

    // 陀螺仪：保留 raw，同时输出温度补偿后的 gx/gy/gz。
    out->gx = compensate_gyro(out->gx_raw, GYRO_GX_COEF, out->temp);
    out->gy = compensate_gyro(out->gy_raw, GYRO_GY_COEF, out->temp);
    out->gz = compensate_gyro(out->gz_raw, GYRO_GZ_COEF, out->temp);
    return ESP_OK;
}

static void complementary_update(const imu_data_t *data)
{
    // 互补滤波：加速度计给低频姿态，陀螺仪积分给短时动态响应。
    float roll_acc = atan2f(data->ay, data->az) * DEG_PER_RAD;
    float pitch_acc = atan2f(-data->ax, sqrtf(data->ay * data->ay + data->az * data->az)) * DEG_PER_RAD;

    if (!attitude_initialized) {
        roll_deg = roll_acc;
        pitch_deg = pitch_acc;
        last_attitude_us = data->timestamp_us;
        attitude_initialized = true;
        return;
    }

    float dt_s = (data->timestamp_us - last_attitude_us) / 1000000.0f;
    last_attitude_us = data->timestamp_us;
    if (dt_s <= 0.0f || dt_s > 1.0f) {
        dt_s = LOOP_PERIOD_MS / 1000.0f;
    }

    roll_deg += data->gx * dt_s;
    pitch_deg += data->gy * dt_s;
    roll_deg = COMPLEMENTARY_ALPHA * roll_deg + (1.0f - COMPLEMENTARY_ALPHA) * roll_acc;
    pitch_deg = COMPLEMENTARY_ALPHA * pitch_deg + (1.0f - COMPLEMENTARY_ALPHA) * pitch_acc;
}

static bool normalize3(float *x, float *y, float *z)
{
    float norm = sqrtf((*x) * (*x) + (*y) * (*y) + (*z) * (*z));
    if (!isfinite(norm) || norm <= 1e-6f) {
        return false;
    }
    *x /= norm;
    *y /= norm;
    *z /= norm;
    return true;
}
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
void app_main(void)
{
    nvs_init_for_logs();
    ESP_ERROR_CHECK_WITHOUT_ABORT(uart_driver_install(UART_NUM_0, 1024, 0, 0, NULL, 0));
    usb_serial_jtag_driver_config_t usb_jtag_config = {
        .tx_buffer_size = 1024,
        .rx_buffer_size = 1024,
    };
    ESP_ERROR_CHECK_WITHOUT_ABORT(usb_serial_jtag_driver_install(&usb_jtag_config));
    ESP_ERROR_CHECK_WITHOUT_ABORT(gps_uart_init());
    ESP_ERROR_CHECK(i2c_bus_init());
    i2c_scan();
    init_all_sensors();
    if (has_gps_uart && (has_mpu || has_hmc)) {
        BaseType_t ok = xTaskCreate(gps_sync_task, "gps_sync", GPS_SYNC_TASK_STACK, NULL,
                                    GPS_SYNC_TASK_PRIORITY, &gps_sync_task_handle);
        if (ok != pdPASS) {
            gps_sync_task_handle = NULL;
            ESP_LOGW(TAG, "GPS sync task create failed");
        }
    }
    bmp_log_print_status();
    gps_log_print_status();
    bmp_log_capture_if_armed();
    gps_log_capture_if_armed();
    print_header();

    mag_data_t mag = {
        .timestamp_us = 0,
        .bx = NAN,
        .by = NAN,
        .bz = NAN,
        .magnitude = NAN,
    };
    baro_data_t baro = {
        .timestamp_us = 0,
        .temperature_c = NAN,
        .pressure_pa = NAN,
        .altitude_m = NAN,
    };
    float bx_cal = NAN;
    float by_cal = NAN;
    float bz_cal = NAN;
    float mag_cal = NAN;
    float yaw_flat = NAN;
    float yaw_tilt = NAN;
    int64_t last_hmc_read_us = -HMC_READ_PERIOD_MS * 1000LL;
    int64_t last_bmp_read_us = -BMP_READ_PERIOD_MS * 1000LL;
    int64_t last_sensor_print_us = -SENSOR_PRINT_PERIOD_MS * 1000LL;

    while (1) {
        bmp_log_poll_uart_commands();
        gps_poll_uart();
        int64_t loop_start_us = esp_timer_get_time();
        int64_t now_us = loop_start_us;
        int64_t mpu_us = 0;
        int64_t comp_us = 0;
        int64_t hmc_us = 0;
        int64_t yaw_us = 0;
        int64_t mahony_us = 0;
        int64_t bmp_us = 0;
        bool imu_ok = false;
        bool comp_updated = false;
        bool mahony_updated = false;
        bool sensor_printed = false;

        imu_data_t imu = {
            .timestamp_us = now_us,
            .ax_raw = NAN,
            .ay_raw = NAN,
            .az_raw = NAN,
            .gx_raw = NAN,
            .gy_raw = NAN,
            .gz_raw = NAN,
            .ax = NAN,
            .ay = NAN,
            .az = NAN,
            .gx = NAN,
            .gy = NAN,
            .gz = NAN,
            .temp = NAN,
        };

        int64_t stage_start_us = esp_timer_get_time();
        if (has_mpu && mpu_read_sample(&imu) == ESP_OK) {
            mpu_us = esp_timer_get_time() - stage_start_us;
            stage_start_us = esp_timer_get_time();
            complementary_update(&imu);
            comp_us = esp_timer_get_time() - stage_start_us;
            imu_ok = true;
            comp_updated = true;
        } else {
            mpu_us = esp_timer_get_time() - stage_start_us;
        }

        if (has_hmc && (now_us - last_hmc_read_us) >= HMC_READ_PERIOD_MS * 1000LL) {
            stage_start_us = esp_timer_get_time();
            last_hmc_read_us = now_us;
            if (hmc_read_sample(&mag) == ESP_OK) {
                hmc_us = esp_timer_get_time() - stage_start_us;
                mag_calibrate(mag.bx, mag.by, mag.bz, &bx_cal, &by_cal, &bz_cal);
                mag_cal = sqrtf(bx_cal * bx_cal + by_cal * by_cal + bz_cal * bz_cal);
            } else {
                hmc_us = esp_timer_get_time() - stage_start_us;
            }
        }

        if (isfinite(bx_cal) && isfinite(by_cal) && isfinite(bz_cal)) {
            stage_start_us = esp_timer_get_time();
            yaw_flat = compute_yaw(bx_cal, by_cal);
            if (attitude_initialized) {
                yaw_tilt = compute_tilt_compensated_yaw(bx_cal, by_cal, bz_cal);
            }
            yaw_us = esp_timer_get_time() - stage_start_us;
            if (imu_ok && isfinite(yaw_tilt)) {
                stage_start_us = esp_timer_get_time();
                if (mahony_update(&imu, bx_cal, by_cal, bz_cal, yaw_tilt)) {
                    mahony_updated = true;
                }
                mahony_us = esp_timer_get_time() - stage_start_us;
            }
        }

        if (has_bmp && (now_us - last_bmp_read_us) >= BMP_READ_PERIOD_MS * 1000LL) {
            stage_start_us = esp_timer_get_time();
            last_bmp_read_us = now_us;
            (void)bmp_read_sample(&baro);
            bmp_us = esp_timer_get_time() - stage_start_us;
        }

        if ((now_us - last_sensor_print_us) >= SENSOR_PRINT_PERIOD_MS * 1000LL) {
            last_sensor_print_us = now_us;
            sensor_printed = true;
            int64_t imu_dt_us = imu.timestamp_us - loop_start_us;
            int64_t mag_dt_us = mag.timestamp_us - loop_start_us;
            int64_t bmp_dt_us = baro.timestamp_us - loop_start_us;
            int64_t imu_mag_dt_us = mag.timestamp_us - imu.timestamp_us;
            int64_t imu_bmp_dt_us = baro.timestamp_us - imu.timestamp_us;

            printf("SENSOR,%.3f,"
                   "%.6f,%.6f,%.6f,%.6f,%.6f,%.6f,"
                   "%.6f,%.6f,%.6f,%.6f,%.6f,%.6f,%.3f,"
                   "%.3f,%.3f,"
                   "%.4f,%.4f,%.4f,%.4f,"
                   "%.4f,%.4f,%.4f,%.4f,"
                   "%.3f,%.3f,"
                   "%.3f,%.3f,%.3f,"
                   "%.3f,%.2f,%.3f,"
                   "%lld,%lld,%lld,%lld,%lld\n",
                   now_us / 1000000.0,
                   imu.ax_raw, imu.ay_raw, imu.az_raw, imu.gx_raw, imu.gy_raw, imu.gz_raw,
                   imu.ax, imu.ay, imu.az, imu.gx, imu.gy, imu.gz, imu.temp,
                   roll_deg, pitch_deg,
                   mag.bx, mag.by, mag.bz, mag.magnitude,
                   bx_cal, by_cal, bz_cal, mag_cal,
                   yaw_flat, yaw_tilt,
                   mahony_roll_deg, mahony_pitch_deg, mahony_yaw_deg,
                   baro.temperature_c, baro.pressure_pa, baro.altitude_m,
                   (long long)imu_dt_us, (long long)mag_dt_us, (long long)bmp_dt_us,
                   (long long)imu_mag_dt_us, (long long)imu_bmp_dt_us);
        }

        int64_t loop_process_us = esp_timer_get_time() - loop_start_us;
        int64_t remaining_us = LOOP_PERIOD_MS * 1000LL - loop_process_us;
        if (remaining_us > 0) {
            esp_rom_delay_us((uint32_t)remaining_us);
        }

        perf_record(loop_process_us, mpu_us, comp_us, hmc_us, yaw_us, mahony_us, bmp_us,
                    imu_ok, comp_updated, mahony_updated, sensor_printed);
        perf_print_if_ready();

    }
}

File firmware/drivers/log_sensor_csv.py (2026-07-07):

import argparse
import csv
import re
import time
from datetime import datetime
from pathlib import Path

import serial


DEFAULT_HEADER = [
    "t_s",
    "ax_raw_g",
    "ay_raw_g",
    "az_raw_g",
    "gx_raw_dps",
    "gy_raw_dps",
    "gz_raw_dps",
    "ax_g",
    "ay_g",
    "az_g",
    "gx_dps",
    "gy_dps",
    "gz_dps",
    "mpu_temp_c",
    "roll_deg",
    "pitch_deg",
    "bx_uT",
    "by_uT",
    "bz_uT",
    "mag_uT",
    "bx_cal_uT",
    "by_cal_uT",
    "bz_cal_uT",
    "mag_cal_uT",
    "yaw_flat_deg",
    "yaw_tilt_deg",
    "mahony_roll_deg",
    "mahony_pitch_deg",
    "mahony_yaw_deg",
    "bmp_temp_c",
    "pressure_pa",
    "altitude_m",
    "imu_dt_us",
    "mag_dt_us",
    "bmp_dt_us",
    "imu_mag_dt_us",
    "imu_bmp_dt_us",
]


ANSI_RE = re.compile(r"\x1b\[[0-9;]*[A-Za-z]")


def clean_line(raw: bytes) -> str:
    text = raw.decode("utf-8", errors="ignore").strip()
    return ANSI_RE.sub("", text)


def parse_args():
    parser = argparse.ArgumentParser(description="Log SENSOR CSV rows from ESP32-S3 monitor serial output.")
    parser.add_argument("--port", default="COM7")
    parser.add_argument("--baud", type=int, default=115200)
    parser.add_argument("--seconds", type=float, default=30.0)
    parser.add_argument("--output", default="")
    parser.add_argument("--gps-raw-output", default="")
    parser.add_argument("--gps-fix-output", default="")
    parser.add_argument("--gps-parsed-output", default="")
    parser.add_argument("--gps-pps-output", default="")
    parser.add_argument("--gps-nmea-ts-output", default="")
    parser.add_argument("--sync-sample-output", default="")
    parser.add_argument("--prefix", default="sensor_static")
    return parser.parse_args()


def nmea_latlon(value: str, hemi: str):
    if not value or not hemi:
        return ""
    dot = value.find(".")
    deg_digits = 2 if dot == 4 else 3
    try:
        degrees = float(value[:deg_digits])
        minutes = float(value[deg_digits:])
    except ValueError:
        return ""
    coord = degrees + minutes / 60.0
    if hemi in ("S", "W"):
        coord = -coord
    return f"{coord:.8f}"


def parse_gps_fix(nmea: str, host_t_s: float):
    parts = nmea.split("*", 1)[0].split(",")
    if not parts:
        return None
    msg = parts[0][-3:]
    if msg == "GGA" and len(parts) >= 10:
        return [
            f"{host_t_s:.3f}",
            parts[0][1:],
            parts[1],
            parts[6],
            nmea_latlon(parts[2], parts[3]),
            nmea_latlon(parts[4], parts[5]),
            parts[9],
            "",
            "",
            "",
            parts[7],
            parts[8],
        ]
    if msg == "RMC" and len(parts) >= 10:
        return [
            f"{host_t_s:.3f}",
            parts[0][1:],
            parts[1],
            parts[2],
            nmea_latlon(parts[3], parts[4]),
            nmea_latlon(parts[5], parts[6]),
            "",
            parts[7],
            parts[8],
            parts[9],
            "",
            "",
        ]
    return None


def main():
    args = parse_args()
    out_dir = Path(__file__).resolve().parents[1] / "data"
    out_dir.mkdir(parents=True, exist_ok=True)

    stamp = datetime.now().strftime("%Y%m%d_%H%M%S")
    if args.output:
        out_path = Path(args.output)
    else:
        out_path = out_dir / f"{args.prefix}_{stamp}.csv"
    gps_raw_path = Path(args.gps_raw_output) if args.gps_raw_output else out_dir / f"{args.prefix}_gps_raw_{stamp}.txt"
    gps_fix_path = Path(args.gps_fix_output) if args.gps_fix_output else out_dir / f"{args.prefix}_gps_fix_{stamp}.csv"
    gps_parsed_path = (
        Path(args.gps_parsed_output)
        if args.gps_parsed_output
        else out_dir / f"{args.prefix}_gps_parsed_{stamp}.csv"
    )
    gps_pps_path = Path(args.gps_pps_output) if args.gps_pps_output else out_dir / f"{args.prefix}_gps_pps_{stamp}.csv"
    gps_nmea_ts_path = (
        Path(args.gps_nmea_ts_output)
        if args.gps_nmea_ts_output
        else out_dir / f"{args.prefix}_gps_nmea_ts_{stamp}.csv"
    )
    sync_sample_path = (
        Path(args.sync_sample_output)
        if args.sync_sample_output
        else out_dir / f"{args.prefix}_sync_sample_{stamp}.csv"
    )

    header = DEFAULT_HEADER
    count = 0
    gps_raw_count = 0
    gps_fix_count = 0
    gps_parsed_count = 0
    gps_pps_count = 0
    gps_nmea_ts_count = 0
    sync_sample_count = 0
    deadline = time.time() + args.seconds

    print(f"Opening {args.port} at {args.baud} baud")
    print(f"Logging SENSOR rows for {args.seconds:.1f}s -> {out_path}")
    print(f"Logging GPS raw NMEA -> {gps_raw_path}")
    print(f"Logging GPS fixes -> {gps_fix_path}")
    print(f"Logging firmware GPS parsed rows -> {gps_parsed_path}")
    print(f"Logging GPS PPS timestamps -> {gps_pps_path}")
    print(f"Logging GPS NMEA timestamps -> {gps_nmea_ts_path}")
    print(f"Logging PPS-triggered sensor samples -> {sync_sample_path}")
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
